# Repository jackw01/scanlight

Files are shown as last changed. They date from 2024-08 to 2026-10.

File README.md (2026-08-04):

# A Better Light Source For Scanning Color Negative Film

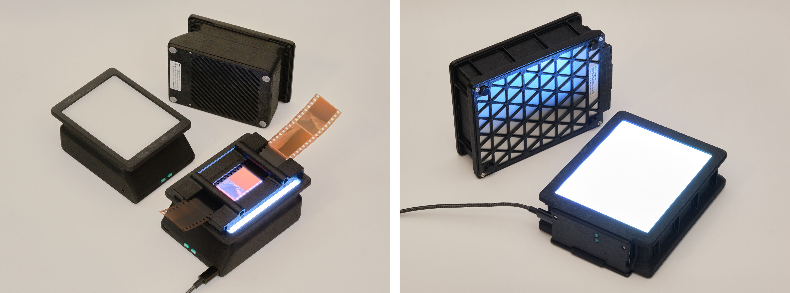
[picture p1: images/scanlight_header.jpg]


Left: [scanlight v4](./v4.md), right: [big scanlight](./big.md)

<small>Originally published 2024-08-05, last updated 2026-08-02</small>

## tl;dr

Narrowband trichromatic (RGB) light sources are superior to broadband (white) light for scanning color negative film; there are very good reasons why all commercial film scanners use RGB. ([film scanners were using blue LEDs at least a decade before they would be widely used in consumer products!](https://patents.google.com/patent/JPH09130546A/en?q=(film+scanner+LED)&oq=film+scanner+LED&sort=old)) Scanning film with an RGB light source produces high quality results with minimal post-processing, without the need for specialized software.

### the results

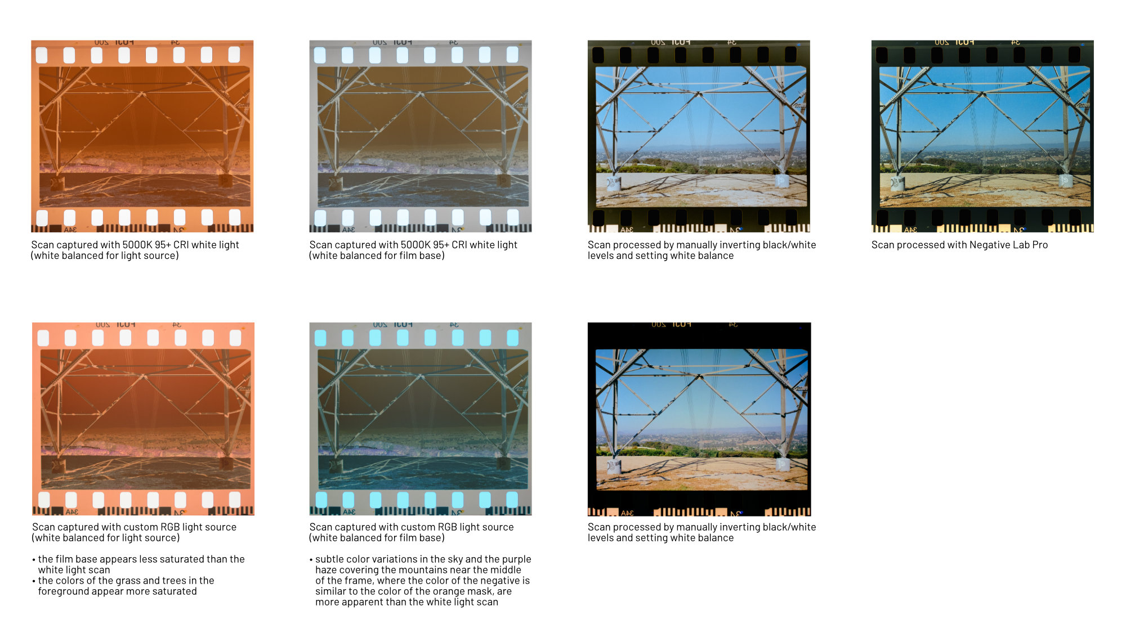
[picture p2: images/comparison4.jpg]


<small>Both scans captured using Fujifilm X-T30. White light scan captured using 95+ CRI 5000K light source. RGB scan captured using custom 450nm+525nm+665nm light source.</small>

## the simplified explanation

Color negative (C-41) film stores an image using cyan, magenta, and yellow dyes. Dyes appear a certain color because they absorb some wavelengths of light; for example, yellow dye mostly absorbs light in the 400-550nm range (which we perceive as violet through green), while allowing other wavelengths (yellow through red) to pass through the film. **These dyes are not intended to produce a human-viewable image, but rather to attenuate certain wavelengths of light for making prints on photosensitive paper.**

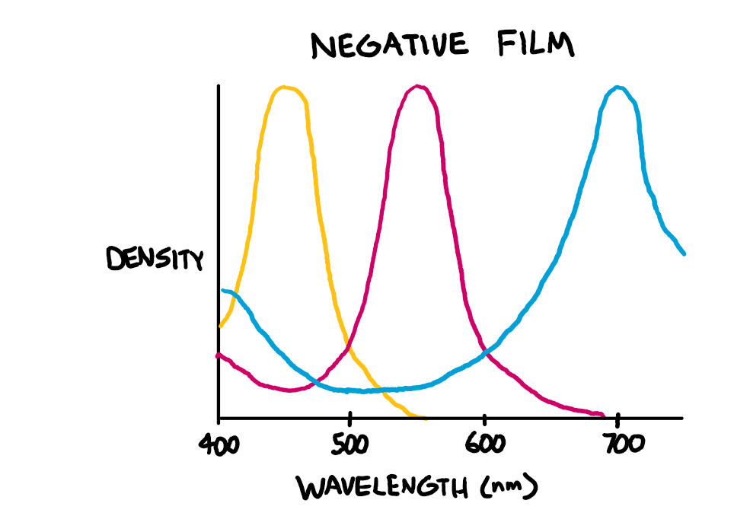
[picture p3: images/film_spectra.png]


White light sources emit light over a broad spectrum of wavelengths. When white light passes through C-41 film, some of these wavelengths are only slightly absorbed by the dyes, which means that these wavelengths aren't useful for recovering the information stored in the individual dye layers - for example, the 580-620nm band (yellow through red-orange light) is mostly transmitted through the film, with a small amount being absorbed by both the magenta and cyan dye layers.

The quality of white light sources is measured with CRI, which represents how well a light source reproduces the true color of a set of standardized color swatches. CRI is effectively a weighted average of how much light a light source emits across different parts of the visible light spectrum, and only a few of these parts matter when it comes to extracting information from color film. **CRI doesn't take into account the deep red (>630nm) and deep blue (<480nm) parts of the spectrum, so as a result, many high-CRI LEDs don't emit much light at these wavelengths, which happen to be where the yellow and cyan dyes absorb the most light.**

<small>note: Standardized scores that take into account these wavelength bands at the edges of the visible spectrum do exist (R9 and R12), but are not readily provided by all LED manufacturers.</small>

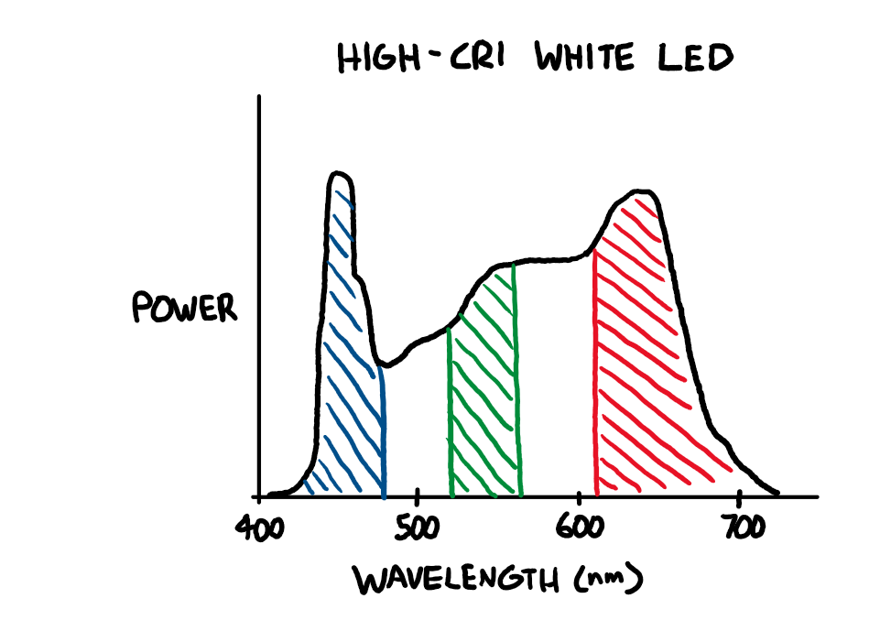
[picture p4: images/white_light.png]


With darkroom printing, this is not an issue, as RA-4 color print paper (and motion picture print film) are, by design, most sensitive to specific bands of wavelengths that avoid the crosstalk regions between the dye layers in negative film, and the paper is exposed with an incandescent light source with a smooth emission spectrum across the entire visible range (400-700nm) and beyond.

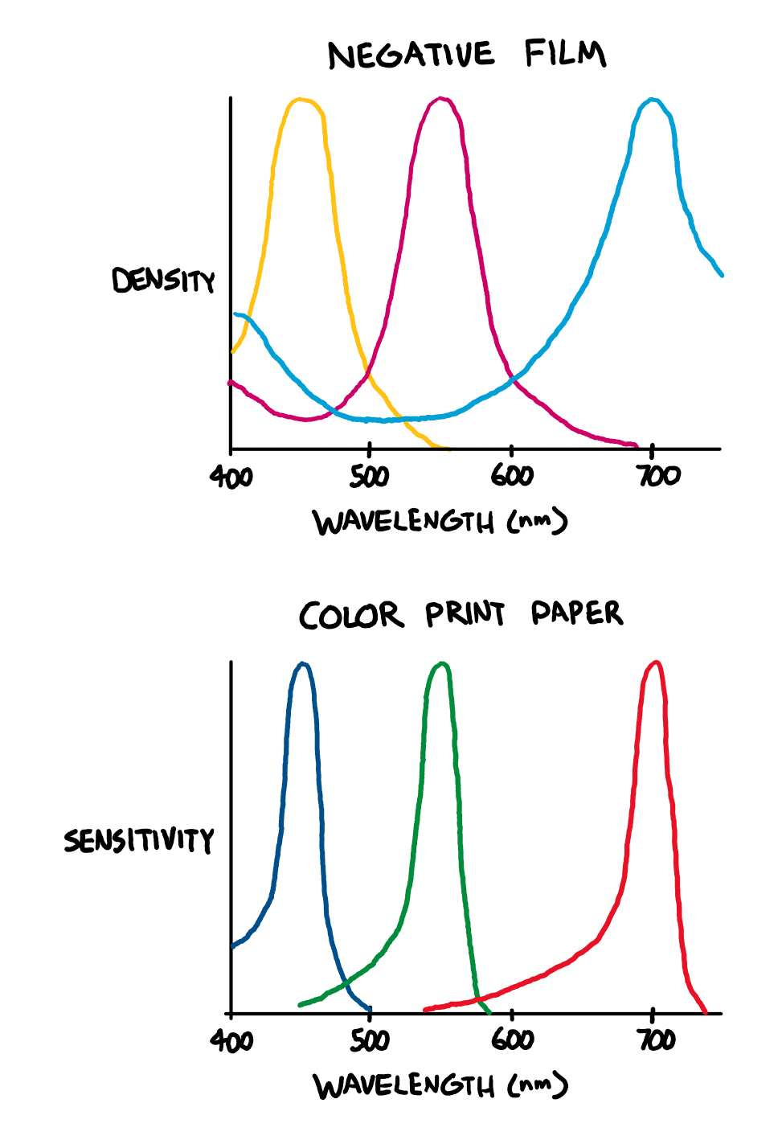
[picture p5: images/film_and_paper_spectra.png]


What about scanning film with a digital camera? Digital camera sensors are designed to capture light in a way that allows for a faithful reproduction of the colors that humans would perceive (this is a gross oversimplification.) C-41 film was *not* designed to be directly viewed by humans.

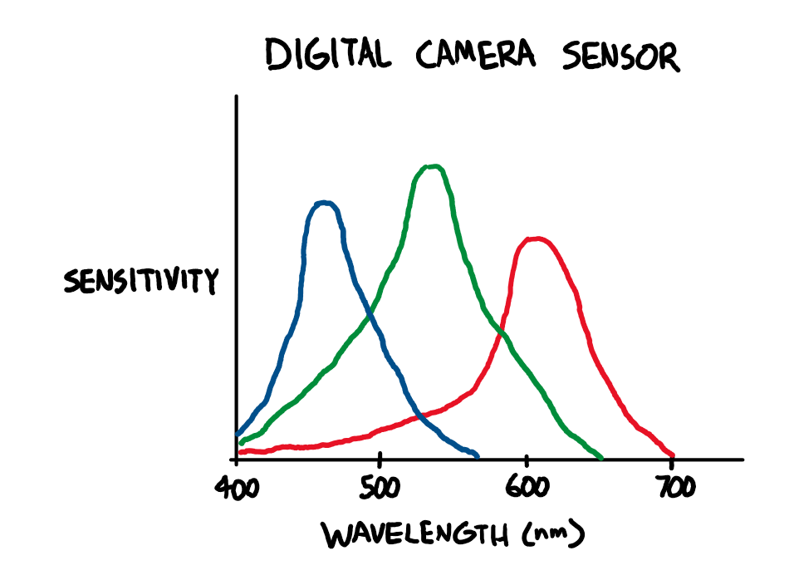
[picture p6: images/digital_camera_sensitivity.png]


Not only is the camera sensitive to wavelengths of light that are effectively ignored by RA-4 paper, there is significant crosstalk between the color channel sensitivities of digital camera sensors: light in the ~580-600nm range is seen roughly equally by the red and green channels, and light in the ~480-500nm range is seen by both the green and blue channels.

The red channel of the scan will contain not just information from the red-blocking cyan dye, but also the green-blocking magenta dye. The green channel will contain information from all three dye layers. Additionally, the overall light transmission of C-41 film is heavily biased towards yellow and orange wavelengths due to the orange mask and the relatively large gap between the magenta and cyan dye absorption peaks, which means that **a lot** of light gets through that interferes with both the red and green channels in the camera sensor without carrying much useful information about the colors stored in the film.

<small>note: the orange color of C-41 film is often misunderstood to be the color of the plastic film base, or an orange tint evenly applied over the whole image. It is actually a corrective mask made up of blue- and green-blocking positive images which compensate for deficiencies in the red-sensing and green-sensing layers of the film. For a good explanation of how this works, see [this article](https://observablehq.com/@dorskyee/understanding-color-film). In practice, this means that less-exposed parts of the negative let through disproportionately more yellow, orange, and red light.</small>

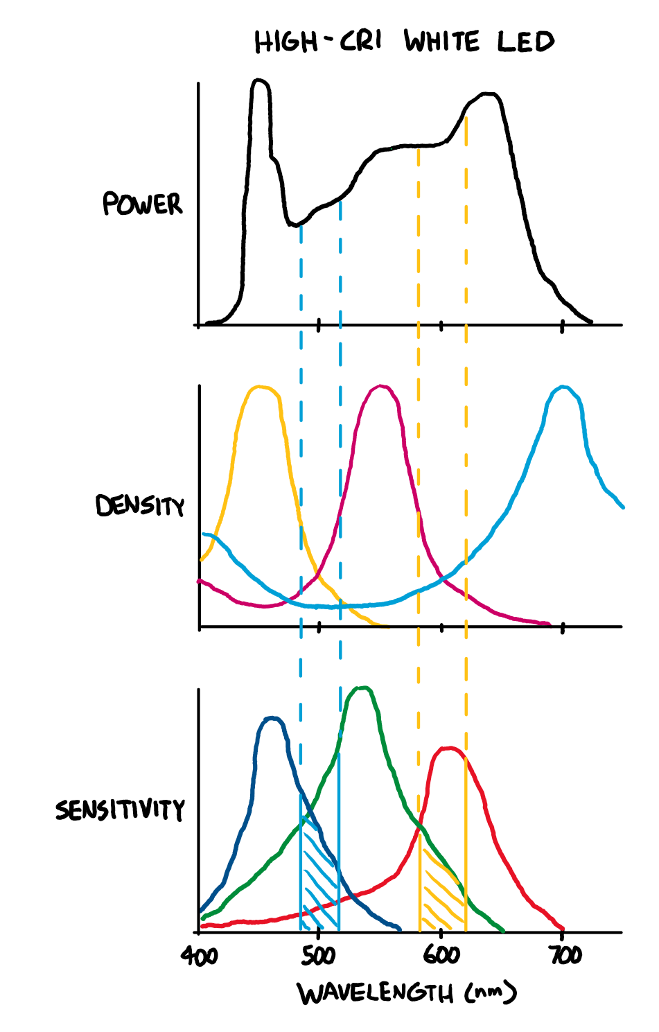
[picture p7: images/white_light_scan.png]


So if you scan color negative film with white light, you can't just invert the colors and expect a good result. You need to do some math to try to recover the individual dye layers of the film from ambiguous input data. This can't be done in standard image editing software, which is why dedicated software for negative conversion exists. The level of crosstalk on each channel depends heavily on both the emission spectra of the light source and the spectral sensitivity of the camera, so the conversion process needs to be either calibrated, manually adjusted until it looks “right”, or deduced by the processing software with varying degrees of accuracy. The color depth of the resulting positive image will be relatively low because much of the information recorded by the camera is effectively useless yellow-orange light that has passed through the film without being significantly attenuated by any of the dyes.

To avoid these issues, (almost?) all commercial negative film scanners use a trichromatic narrowband light source with red, green, and blue LEDs to minimize crosstalk between the dye layers in the film and the color channels on the image sensor, and some use monochrome sensors to eliminate sensor crosstalk entirely. When doing it this way, no guesswork is needed to recover a usable image and it's really as simple as inverting the color channels and setting the color balance and black/white points. There is still some crosstalk between camera sensor channels, but now that the light source emits light in three narrow, independently controllable wavelength bands, it can be easily measured and compensated for, or it can be avoided completely by imaging the red, green, and blue channels separately.

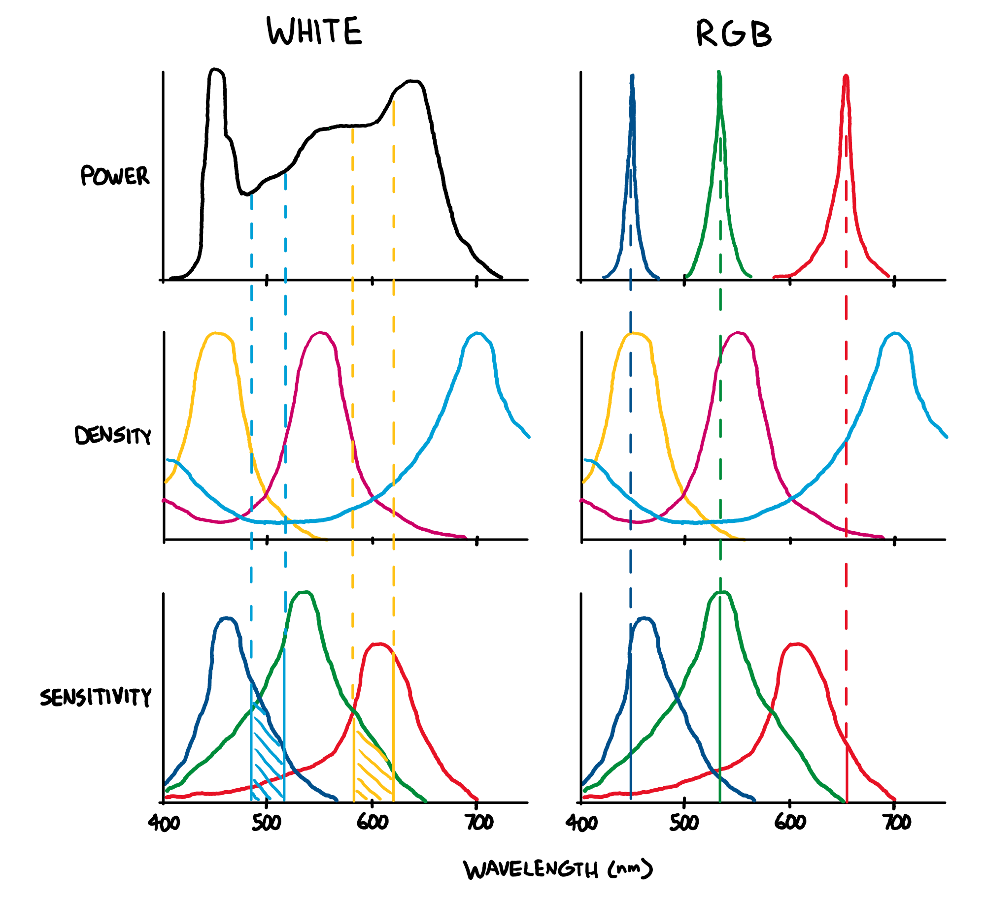
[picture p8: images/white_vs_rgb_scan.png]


### what light source works the best?

When considering the limitations of digital camera sensors, the ideal wavelengths are >650nm for red and <450nm for blue, as shown in the diagram above. Ideally, the green wavelength is 540-560nm to match the absorption peak of the magenta dye, but LEDs in that range are just not practical (see FAQ below for more details), and the standard 525nm works very well.

The next best alternative is to use general purpose RGB LEDs, which typically use 620-630nm for red and 460-480nm for blue. The results will not be the absolute best possible, but will still be far better than with white light. The Fuji Frontier SP3000, a popular professional scanner, uses 630nm for red and 465nm for blue ([source](https://discuss.pixls.us/t/input-color-profile-to-use-for-negatives/20271/13)), but it does not have to contend with the color channel sensitivity of a typical digital camera - it has a monochrome image sensor and combines three exposures taken with red, green, and blue light.

To get the best possible results, I designed my own custom RGB light sources using 665nm red and 455nm blue LEDs. More information on the designs can be found [here (scanlight v4)](./v4.md) and [here (big scanlight)](./big.md).



All design files for the light sources and film carriers, both current and older versions, can be downloaded from the [GitHub repository](https://github.com/jackw01/scanlight/).

### more sample scans

All scans were processed in [NegPy](https://github.com/marcinz606/NegPy), leaving all settings at the default values. Sensor calibration was used for the RGB scans. The groups of four negatives were scanned and manually processed together in order to demonstrate how the light source affects the overall look of the scans rather than to show a subjectively ideal edit for each photo.

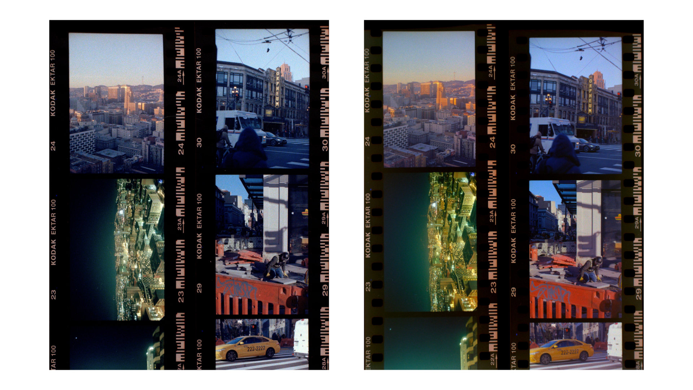
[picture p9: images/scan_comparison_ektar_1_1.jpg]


<p align="center"><small>Kodak Ektar 100 (left: white light, right: narrowband RGB light)</small></p>

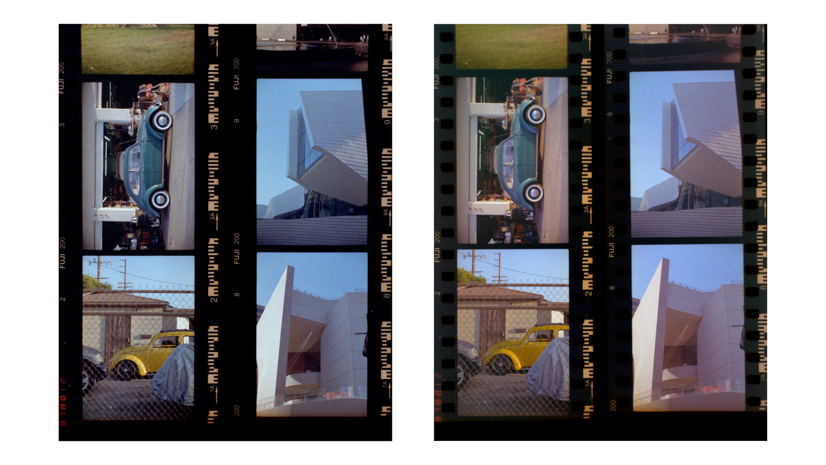
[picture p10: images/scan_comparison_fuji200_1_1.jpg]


<p align="center"><small>Fuji 200 (left: white light, right: narrowband RGB light)</small></p>

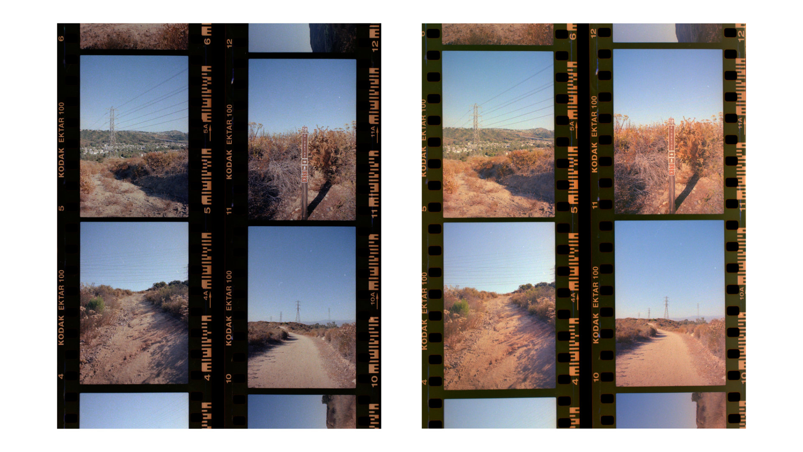
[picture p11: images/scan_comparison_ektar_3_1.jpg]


<p align="center"><small>Kodak Ektar 100 (left: white light, right: narrowband RGB light)</small></p>

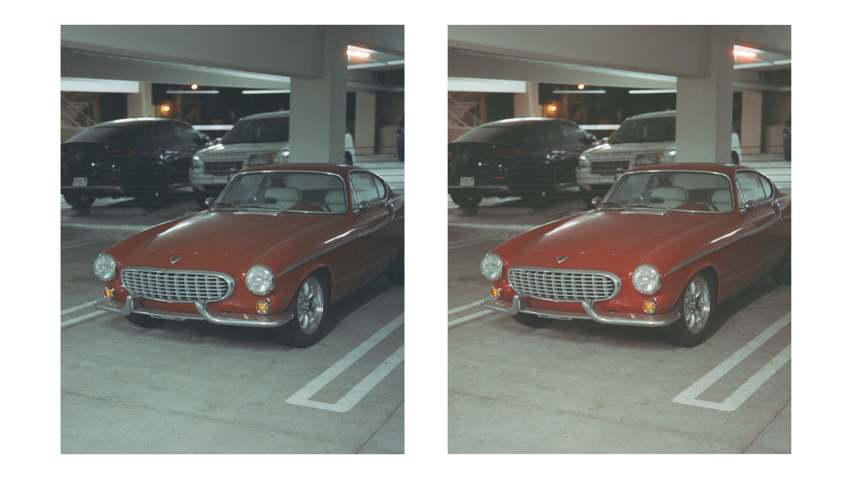
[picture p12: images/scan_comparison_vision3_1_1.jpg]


<p align="center"><small>Kodak Vision3 500T (left: white light, right: narrowband RGB light)</small></p>

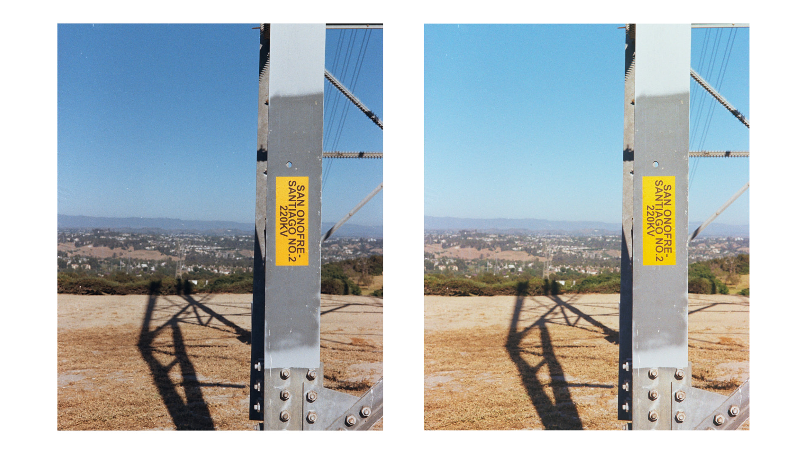
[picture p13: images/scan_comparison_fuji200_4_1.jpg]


<p align="center"><small>Fuji 200 (left: white light, right: narrowband RGB light)</small></p>

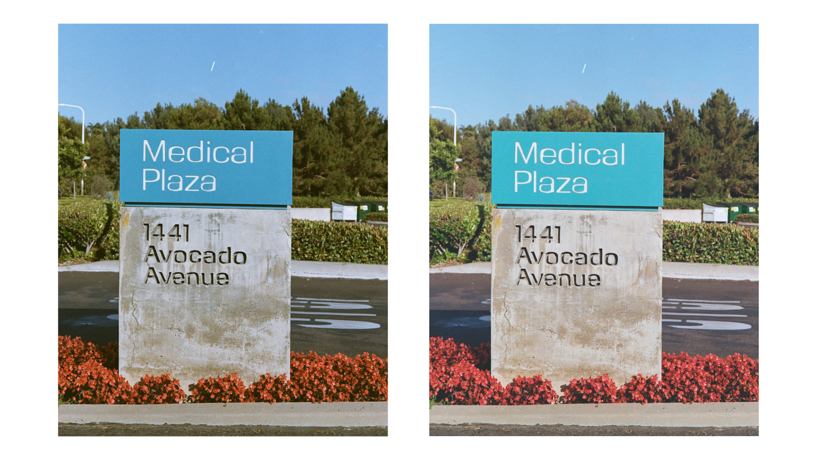
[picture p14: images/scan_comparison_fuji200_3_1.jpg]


<p align="center"><small>Fuji 200 (left: white light, right: narrowband RGB light)</small></p>

### recommended reading, if you're curious

* Edward J Giorgianni and Thomas E Madden, *Digital Color Management: Encoding Solutions, 2nd Edition*
* Robert L Shanebrook, *Making Kodak Film*

## part 2: responses to frequent questions and comments

<small>Updated 2026-08-02</small>

#### how should i process my scans?
As of 2026, free and open-source film scan processing software exists ([NegPy](https://github.com/marcinz606/NegPy)) which produces excellent results with little effort when inverting single-exposure RGB scans. NegPy uses a processing pipeline which emulates the RA-4 printing process, and supports flat-field correction and automatic merging of trichromatic (separate exposures for red, green, and blue) scans. I would highly recommend this to anyone who is looking to start scanning film at home or is having difficulty with their current processing workflow.

Using software specifically designed for processing white light scans (e.g. Negative Lab Pro) to process RGB scans may give suboptimal results. It's also possible to get good results without using any specialized software, by manually inverting your scans in photo editing software as described below. Manual inversion is much easier with RGB scans than with white light scans, but it still takes more effort than NegPy, and compensating for camera sensor crosstalk may be difficult depending on which image editing software you use.

#### but can't i just edit the white light scan to look like the RGB scan?
You can't get the exact same colors as the RGB scan by adjusting the white balance or individual color channels of a white light scan. This is physically impossible because the light interacted with the film in a fundamentally different way in the white light scan vs. the RGB scan before it was reduced to three bins of wavelengths approximately representing red, green, and blue by the camera sensor; some of the color information stored in the film is lost in this process.

#### but i keep seeing/hearing that using RGB light results in oversaturation or hue shifts
Increasing saturation is often done on purpose to produce a visually striking and not entirely accurate demonstration of why RGB is better (in practice, the differences in color reproduction are more subtle once saturation is equalized), or is the result of processing RGB scans with processing workflows intended to produce normal-looking results with white light scans. No one is saying you can’t adjust saturation in post, or use processing software that produces less-saturated results. Hue shifts are a result of using a processing workflow that doesn't compensate for camera sensor channel crosstalk, and should be a complete non-issue if using the sensor calibration tool in NegPy.

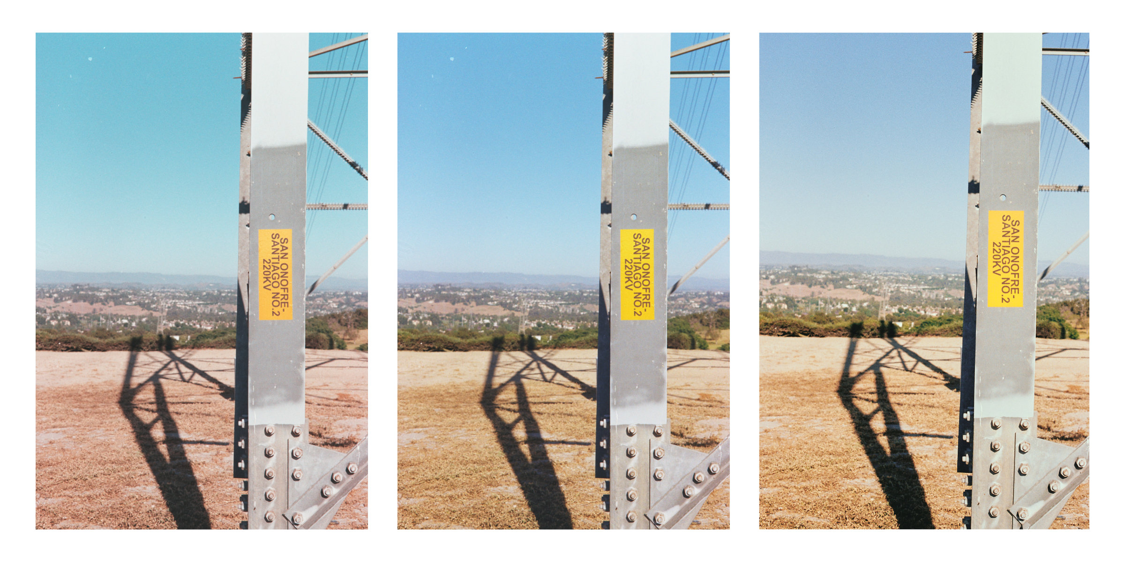
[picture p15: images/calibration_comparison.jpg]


<p align="center"><small>From left to right: RGB scan without sensor calibration (note blue-to-cyan and orange-to-magenta shifts); RGB scan with sensor calibration; Noritsu HS-1800 lab scan</small></p>

#### but the colors in the sample scans still don't look good to me / the colors don't look the way i think film should look
Getting the desired colors from C-41 film, whether by darkroom printing or scanning and editing, has always involved some level of manual adjustment. It is also worth noting that our collective idea of how film is supposed to look is often influenced by highly edited or low-quality scans; old, faded prints; or even software emulations. **Photography is art, and as such it has always involved making subjective decisions about how images should look; all photos are interpretations of raw data and it's up to the photographer to decide what interpretation looks best.** The best starting point for editing is a scan that represents the image data stored in the dye layers of the film with maximum dynamic range and minimal crosstalk.

#### won't this make all film look the same?
Scanning film with RGB light does not neutralize the differences in the "look" of different films; actually, it should produce results that are closer to the intended look of the film when printed on RA-4 paper. The differences in look come from differences in the film's sensitivity to light during exposure and chemical reactions that affect how the dyes are formed during development, not the absorption characteristics of the dyes themselves.

#### should i capture three separate exposures for each color channel?
You can either capture a single image with the red, green, and blue channels on at the same time or capture separate images for each color and merge them later. Both methods can produce satisfactory results. The latter approach has the potential for more technically accurate colors as it eliminates any chance of crosstalk between color channels, but takes significantly more work than capturing a single RGB image which can be processed directly.

When capturing red, green, and blue at the same time, the severity of crosstalk depends heavily on the spectral response of the camera's image sensor and camera manufacturer's color profile, and it may not even be noticeable in many cases. Crosstalk typically manifests as consistent color shifts (usually, reds appearing too pink or greens appearing too yellow,) and can usually be resolved by post-processing with software that supports a crosstalk matrix or RGB primary calibration, such as NegPy (open-source) or Lightroom.

#### how should i adjust the red/green/blue channel levels on the light source?
The red, green, and blue channels on the light source should be adjusted to maximize how much of the camera's dynamic range is utilized on all three color channels. To do this, set the camera white balance to neutral/5000K and adjust the light source so that the histogram peaks on each channel become aligned when the camera is viewing the light through an unexposed, developed piece of film. The deep red (~650nm) and deep blue (~450nm) wavelengths used for RGB scanning are near the edge of what most Bayer-filter image sensors are sensitive to, so some cameras will be significantly more sensitive to one of these wavelengths than others. Therefore, the optimal settings will differ between camera manufacturers and models.

#### should i use narrowband light for scanning color positive (slide) film?
Some people have had success using an adjustable RGB light source for recovering faded slides, but I would not recommend using a narrowband light source for scanning slides that are in good condition. The results I have seen so far are not promising compared to using white light, as colors are typically oversaturated and pink, red, and orange hues become indistinguishable from each other. This likely all comes down to the fact that color positive film is designed to reproduce colors naturally when viewed with a broad-spectrum light source. Any high CRI (95+) white light source should work well. There is some debate over the ideal color temperature: the majority of slide projectors used halogen bulbs with a 3000K-3500K color temperature, but some will argue that a 5000K color temperature should be used instead (this seems to be because Fujifilm datasheets recommend viewing with a ISO 3664 compliant viewer, which historically would have used specialized 5000K high-CRI fluorescent tubes as a light source). I haven't seen a side-by-side comparison, but I would assume that the difference in results would be very subtle or nonexistent if the white balance is corrected when editing the scans.

#### does light source / color matter for scanning black and white film?
No. White and narrowband light sources work equally well for scanning B&W film.

#### what are your thoughts on film carriers?
I have received quite a few emails echoing the sentiment that the film carriers on the market now are generally overpriced for what they are, and there seems to be little correlation between price and user experience. Most film carriers made for DSLR scanning guide the film through a narrow slot with an S-shaped curve on each end to keep it flat. For 35mm film, this seems to generally work well, and based on the reviews and comments I have seen I am not convinced that out of the many film carriers using this design, any perform significantly better than the others. For 120 film, the s-curve design struggles with film flatness when scanning the end frames on cut pieces of film, or if the film is curled across its width. There are a few alternative designs out there that should be able to provide superior film flatness in this case, but I haven't yet seen a thorough quantitative comparison of these. Some of these also involve rough 3D-printed parts coming into direct contact with the film emulsion, which doesn't seem ideal.

##### what about full-border scanning?
Film carriers that allow full-border scanning tend to be significantly worse at keeping the film flat and handling curled film, except for ones that hold the film against glass or acrylic, but those come with other issues (high cost, difficulty keeping the glass clean, Newton's rings, etc.)

#### what lens should i use?
[This list](https://www.pixl-latr.com/how-good-a-macro-lens-do-you-really-need-for-dslr-mirrorless-camera-scanning/) is generally a good starting point. The Micro-Nikkor 55mm f/2.8 AI is my personal recommendation; it outperforms many modern lenses in field flatness, corner-to-corner sharpness, and chromatic aberration, and it is very affordable.

I would **not** recommend low-cost third-party macro lenses like the TTArtisan 40mm f/2.8 Macro or 7artisans 60mm f/2.8 Macro II. While the build quality of these lenses is excellent and they generally have superior contrast to vintage lenses due to better optical coatings, in my experience they cannot match the top tiers of lenses in the above list in corner-to-corner sharpness and lack of chromatic aberration. I would also recommend against using extension tubes with modern lenses; this tends to result in field curvature and other aberrations which can be quite severe depending on the lens.

#### does brightness enhancing film actually work? should i use it?
Brightness enhancing film (BEF) does indeed work to make diffuse light sources more directional, but this can cause other issues. Collimated light makes the image on the film appear slightly sharper, but also exaggerates the appearance of dust and scratches. Depending on the relative positioning of the light source, film, and lens; and type of lens used; grid or moiré patterns may appear due to the structure of the brightness enhancing film and vignetting may occur or become more pronounced. BEF also tends to be difficult to keep clean of dust and fingerprints.

#### what about using an LCD/OLED display as the light source?
OLED displays do contain separate red, green, and blue emitters, but they typically have broader emission spectra than inorganic LEDs, and the red and blue peak wavelengths tend to be closer to 620nm and 470nm respectively. They will produce results with less crosstalk than a white light source, but not as good as RGB LEDs.

Older LCD displays generally emit white light that has been filtered through red, green, and blue filters and recombined. The results will depend on the emission spectrum of the exact display used, and will generally be no better than a white light source. Newer high-gamut LCDs (especially quantum dot LED LCDs) use backlight LEDs with special phosphors designed to emit in narrower bands than typical white LEDs, so they should in theory work as well as OLED.

#### 540-560nm appears to be the ideal green wavelength, why use 525nm?
LEDs in the 540-560nm range are impractical for most uses due to poor efficiency and thus are not widely available. Some GaP green LEDs exist which have peak emission at 555nm, but they are extremely inefficient, requiring hundreds to match the light output of a single 2835 mid-power InGaN LED. Some manufacturers do offer 530-535nm wavelength bins of their InGaN mid-power green LEDs, but these are difficult to source as they are commercially undesirable due to lower efficiency. Applications where a "true green" or "lime green" color is desired usually now use phosphor-converted LEDs, which are very efficient but are suboptimal for film scanning as they output light over a much broader band of wavelengths (60-100nm FWHM vs 15-30nm for direct green LEDs.)

##### how did old film scanners get ~540nm?
They either used cold-cathode fluorescent lamps with phosphors tuned to emit at the desired wavelengths, or used InGaN green LEDs from a higher wavelength bin. These have become increasingly hard to find as manufacturing processes have become more consistent and the industry has settled on ~525nm as the standard green wavelength for lighting and display applications. On the other hand, mid- and high-power ~450nm deep blue and ~660nm deep red LEDs have stayed available alongside their more common ~470nm and ~620nm counterparts due to increased demand, mostly in horticultural applications.

#### why does big scanlight have infrared LEDs?
The IR LEDs are for dust removal – the dyes in color negative film transmit infrared light, but dust does not. By capturing a separate IR image with an IR-sensitive camera, dust particles on the image can be easily located and inpainted. I originally added the LEDs for a specific customer who uses a specialized industrial camera and custom software processing pipeline to do this. As of June 2026, the only free/open-source software I know of that can automate this process is [NegPy](https://github.com/marcinz606/NegPy), although I haven't yet tested it with output from big scanlight.

#### will there be a desktop app for scanlight?
There are no plans for a desktop app right now, since the easiest way to make one by far is to just repackage a web app as a desktop app and there is little to be gained by doing this. It is possible to install the app as a progressive web app on most platforms, which will make it appear as a desktop app and allow it to be used without an internet connection.

#### what if i want to manually invert my scans?
It's definitely much easier to do this with narrowband scans than white light scans, but I still recommend using NegPy due to its automatic analysis and camera sensor calibration abilities.

##### 1. scan
Scan all frames as RAW using fixed white balance and exposure. Exposure should be set such that none of the color channels are clipping.
##### 2. import
Import scans into image editing software. Use a linear RAW profile. Apply lens corrections and use Lens Cast Calibration in Capture One or Flat-Field Correction in Lightroom to compensate for any unevenness in the light source if necessary.
##### 3. d-min balance
Neutralize the color of the minimum density (unexposed) areas of one negative by adjusting the red, green, and blue channel max levels.
##### 4. inversion
Invert the black and white points using the Levels or Curves tool and apply an s-shaped tone curve to adjust contrast. Use the brightness/gamma/Levels tool midpoint controls to adjust the overall scene brightness without affecting the black and white points.
##### 5. fine tuning
Apply the same adjustments to all scans from the same roll of film. Manually fine-tune the black and white points and brightness/gamma for all scans.
##### 6. crosstalk compensation
Use either the primary calibration panel in Lightroom, or the color tools in Capture One (more difficult), correct any hue shifts in the scans. Since hue shifts occur due to crosstalk between camera sensor channels in the light source emission bands, not any property of the film itself, this adjustment should be performed across a broad sample of images and saved for future use.

## license

The PCB schematic, layout, and Gerber files and the 3D CAD files for this project are released under the [CERN Open Hardware Licence Version 2 - Weakly Reciprocal](https://choosealicense.com/licenses/cern-ohl-w-2.0/) (CERN-OHL-W V2). Software and firmware are released under the MIT License. The text and illustrations in this article may not be reproduced without permission.

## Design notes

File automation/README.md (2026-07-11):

# scanlight firmware and web app

## hardware versions and binaries

| hardware | hardware version ID | firmware binary filename |
| --- | - | --- |
| scanlight v2/v3 | 2 | sl2_controller* |
| scanlight v4 with 26a901a PCB | 1 | sl4a_controller* |
| scanlight v4 with 26a901b PCB (focus support) | 3 | sl4b_controller* |
| big scanlight | 0 | bsl1_controller* |

## documentation

* [scanlight unified firmware control interface documentation](./bsl_control_interface.md)

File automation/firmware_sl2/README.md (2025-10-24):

Red, green, and blue channel control signals connect to Pi Pico pins 7, 8, and 9 respectively.

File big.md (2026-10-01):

# big scanlight info & instructions

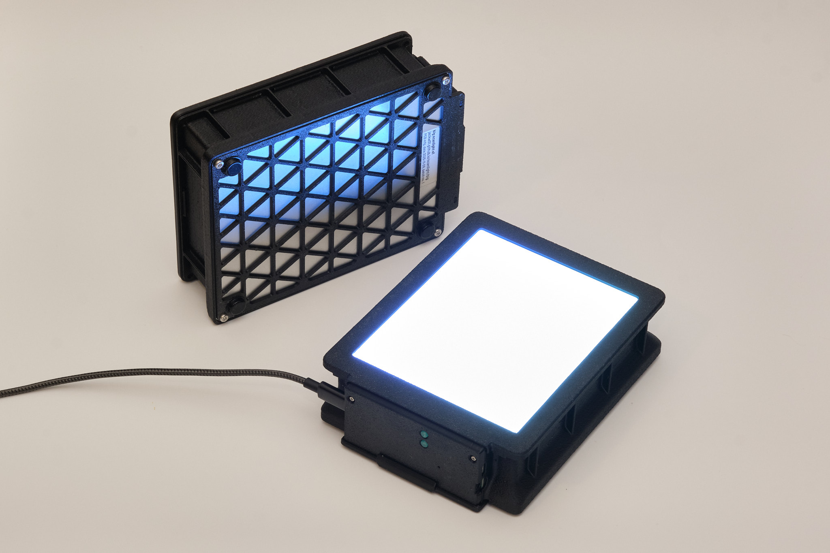
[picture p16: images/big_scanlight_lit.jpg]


## features
* Illuminated area dimensions: 108x134mm (approx. 4.25x5.25in)
* Suitable for use with 35mm, medium format, and 4x5 film
* 20 each of deep red (665nm), green (525nm), deep blue (455nm), and 5000K 95CRI white, and 16 infrared (850nm) LEDs mounted on aluminum PCB for optimal heat dissipation
* Up to 15EV brightness<sup>1</sup> in RGB combined mode, 14EV in white mode
* Better light uniformity over medium format frame sizes than scanlight v2/v3/v4
* Diffuser made from fingerprint- and scratch-resistant textured acrylic
* 3D printed ABS housing
* Fully controllable via USB with [web app](https://jackw01.github.io/scanlight/automation/app_bsl/dist/index.html)
* On/off and mode toggle buttons on light source for standalone usage
* Compatible with accessories made for Negative Supply 4x5" light sources<sup>2</sup>
* Adapters available for compatibility with ToneCarrier and Valoi 360 Advancer
* Minimalist 35mm and medium format film carriers available
* Automated camera shutter control for capturing separate red/green/blue images
* Powered using any USB-C power source (at least 9V at 18W required for full brightness)
* Open source hardware and software

<small>
<sup>1</sup>1/500s at f/8, ISO 100. Direct measurement of the light source (without film.)<br />
<sup>2</sup>big scanlight's diffuser panel is inside a 108x134mm, 1.5mm deep recess in the diffuser bezel, designed to accept masks and film carriers for Negative Supply 4x5" light sources. Check dimensions of accessories you plan to use before buying.
</small><br /><br />

Original article on scanning film with narrowband light (with sample scans): *[A Better Light Source For Scanning Color Negative Film](./README.md)*.

## instructions



### basic operation

The light source is powered via the **left USB-C port**. A USB-C PD power source that can supply at least 2A at 9V (e.g. most USB-C phone, tablet, and laptop chargers) is required to operate at full brightness; however, the light will still operate at reduced brightness from any USB power source capable of delivering at least 2A at 5V (e.g. almost all USB chargers from the last 10 years.)

*It is not recommended to power the light from a USB port on a computer; a dedicated USB power supply should be used instead.*

Press the **upper button** to toggle the light on and off. Press the **lower button** to toggle between narrowband RGB and 95CRI white modes. The buttons work even when the light is not connected to a computer. The default RGB channel brightnesses in this mode can be configured from the GUI, as explained below.

To adjust color and brightness and automate the process of scanning red, green, and blue channels separately, the light source can be connected to a computer via the **right USB-C port** and controlled with the web app located [here](https://jackw01.github.io/scanlight/automation/app_bsl/dist/index.html). The web app requires a Chromium-based web browser or Firefox 151 or newer.

In the **Manual Control** panel of the web app, the red, green, and blue channel brightnesses can be adjusted and the color channels can be turned on individually or together. In **RGB** (narrowband trichromatic) mode, the red, green, and blue LEDs are on at the same time. In **White** mode, only the 95CRI white LEDs are on. The red, green, blue, and infrared LEDs can also be turned on individually; the RGB channel brightness adjustments still apply in this case.

The **RGB Presets** panel of the web app allows RGB channel brightness settings to be stored to and loaded from web browser local storage, using the **Load**, **Create**, **Rename**, and **Delete** buttons.

The **Set as Default** and **Load Default** buttons refer to the default RGB preset, which is stored onboard the light source. This functionality is separate from presets stored in the web app and sets the RGB channel brightnesses used when the light is first powered on and when it is not connected to a computer.

### remote shutter release usage

The **3.5mm jack** can be connected to a camera so that the shutter can be remotely triggered from the web app to automatically capture images for each color channel. The length of the shutter trigger pulse and the delay after are both configurable. The default settings should work for most use cases. Operation in the **R,G,B** mode is shown in the timing diagram below; the other modes work similarly.



A cable with a male 3.5mm plug (otherwise known as a headphone connector) on one end and a camera-specific connector on the other end is required to use this functionality. A wide variety of these cables are available from online retailers; I cannot vouch for the quality of any of them or verify that a specific cable will work, as wiring diagrams are almost never published by the manufacturers. The design has been tested and works with several Fujifilm and Canon cameras that use the 2.5mm microphone jack as the remote shutter release input, with a 3.5mm to 2.5mm cable as well as a standard 3.5mm audio cable and 3.5mm to 2.5mm adapter.

On the original and current PCB revisions (26a902**a**/**b** marked on label), the 3.5mm jack is not electrically isolated. If planning to tether the camera to a computer while controlling the shutter using a light source with this PCB, test that the camera and cable are wired correctly first. Connect both the shutter control cable and a USB cable to the camera, and touch the tip of the 3.5mm plug to the exposed metal shell of the USB connector. If this *does not* trigger the camera shutter, the internal wiring of the camera or cable is likely reversed from the de facto standard and connecting the camera to both the light source and computer at the same time may cause issues. This PCB also does not connect the ring (focus) terminal on the 3.5mm jack, and requires a hardware modification to connect this terminal for remote shutter release compatibility with Nikon and Sony cameras, and possibly others. Units with the modification can be identified by light gray paint applied to the externally visible part of the 3.5mm jack. Some third-party remote shutter release cables for Nikon and Sony cameras already connect the shutter and focus signals together, so the issue may not occur with all camera/cable combinations. There is a workaround for using unmodified units with Nikon cameras, which is to connect the camera cable to the light through a 3.5mm mono-to-stereo adapter. If doing this, it is important that the male end of the adapter used is a two-terminal (mono) plug, rather than a three-terminal (stereo) plug.

### frequently asked questions

See [here](https://jackw01.github.io/scanlight/#part-3-responses-to-frequent-questions-and-comments)

### firmware updates

The web app will automatically notify if a firmware update is available and show a button to put the device into firmware update mode. To manually enter firmware update mode, press and hold down the **DFU mode button** while connecting the **right USB-C port** to a computer. The light source will show up as a USB storage device, and a firmware binary file can be copied to this device to update the firmware.

### cleaning precautions

Cleaning the acrylic diffuser panel with cleaning solutions containing high concentrations of isopropanol, other organic solvents, or ammonia can cause crazing or cracking of the acrylic. If needed, use a cleaner meant for eyeglasses or a diluted household all-purpose cleaner like Simple Green. Do not spray liquids directly on the light source.

### brightness trimming

In order to simplify the electrical design of the light source, the red, green, blue, and white color channels are split into two independently driven sides as shown below. The components used are very well matched, so the difference in brightness between the two sides should be a few percent at most and will generally not be noticed unless working with very low-contrast negatives. If there is a noticeable and consistent "split" in brightness or color across the centerline of the light source, the relative brightness of the two halves can be fine-tuned in the **Brightness Trimming** menu in the web app. Setting the trim values to a positive number increases the relative brightness of side 2; setting them to a negative number increases the relative brightness of side 1.



## technical details

### dimensions



### film carrier compatibility

Adapters are available for improved usability with [toneCarrier](https://tonephotographic.com/) and [Valoi 360 Advancer](https://cinestillfilm.com/products/valoi360-advancer) film carriers. Drawings of the adapters with critical dimensions are included below for reference; the dimensions of these third-party film carriers are not published by the manufacturers and are subject to change, so please use these drawings to verify compatibility with your film carriers before buying.

#### toneCarrier 35mm/120 adapter


<small>All dimensions in millimeters. This adapter is NOT compatible with the old 35mm toneCarrier design found on Printables.com.</small>

#### Valoi 360 Advancer adapter


<small>All dimensions in millimeters. Four M4 screws are required, such as the screws included in Valoi kits for attaching the CS-LITE adapter to the Valoi 360 Advancer.</small>

### optical design

Big scanlight uses a very simple optical design consisting of a matte white acrylic diffuser panel, an LED array which spans the entire illuminated area of the diffuser, and a housing with diffusely reflective sidewalls perpenicular to the PCB and chamfered corners to reduce brightness falloff. In both RGB and white modes, big scanlight achieves similar lighting uniformity to scanlight v4 (slightly better than scanlight v2/v3) over a larger area.

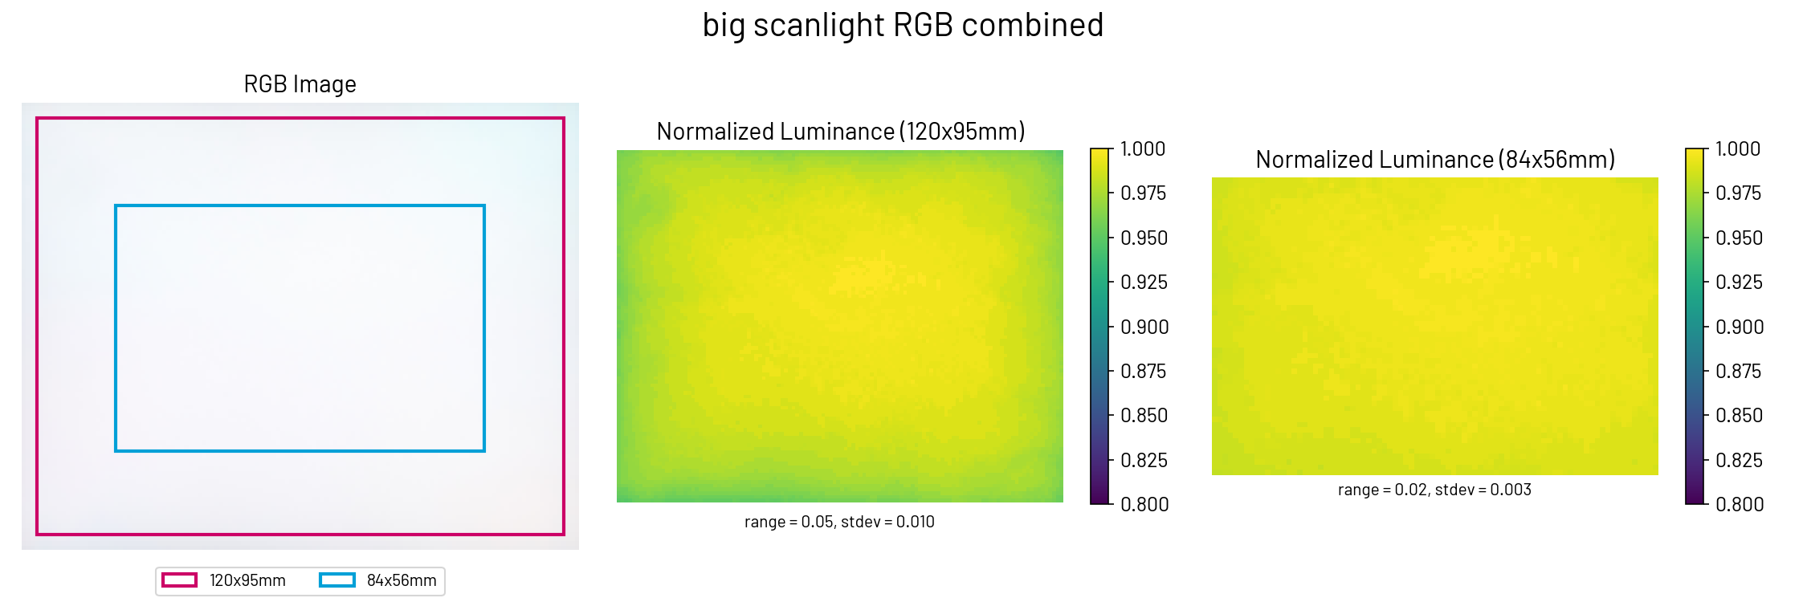
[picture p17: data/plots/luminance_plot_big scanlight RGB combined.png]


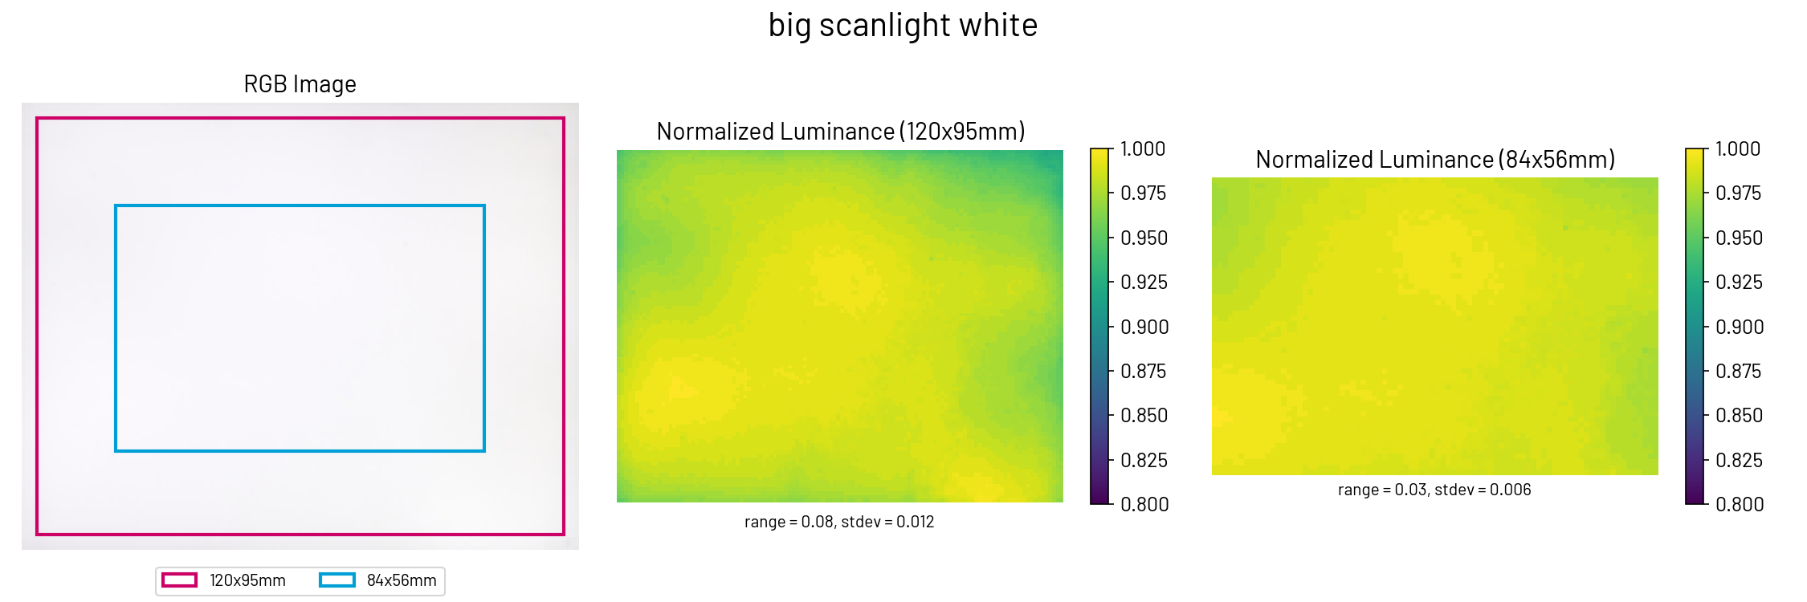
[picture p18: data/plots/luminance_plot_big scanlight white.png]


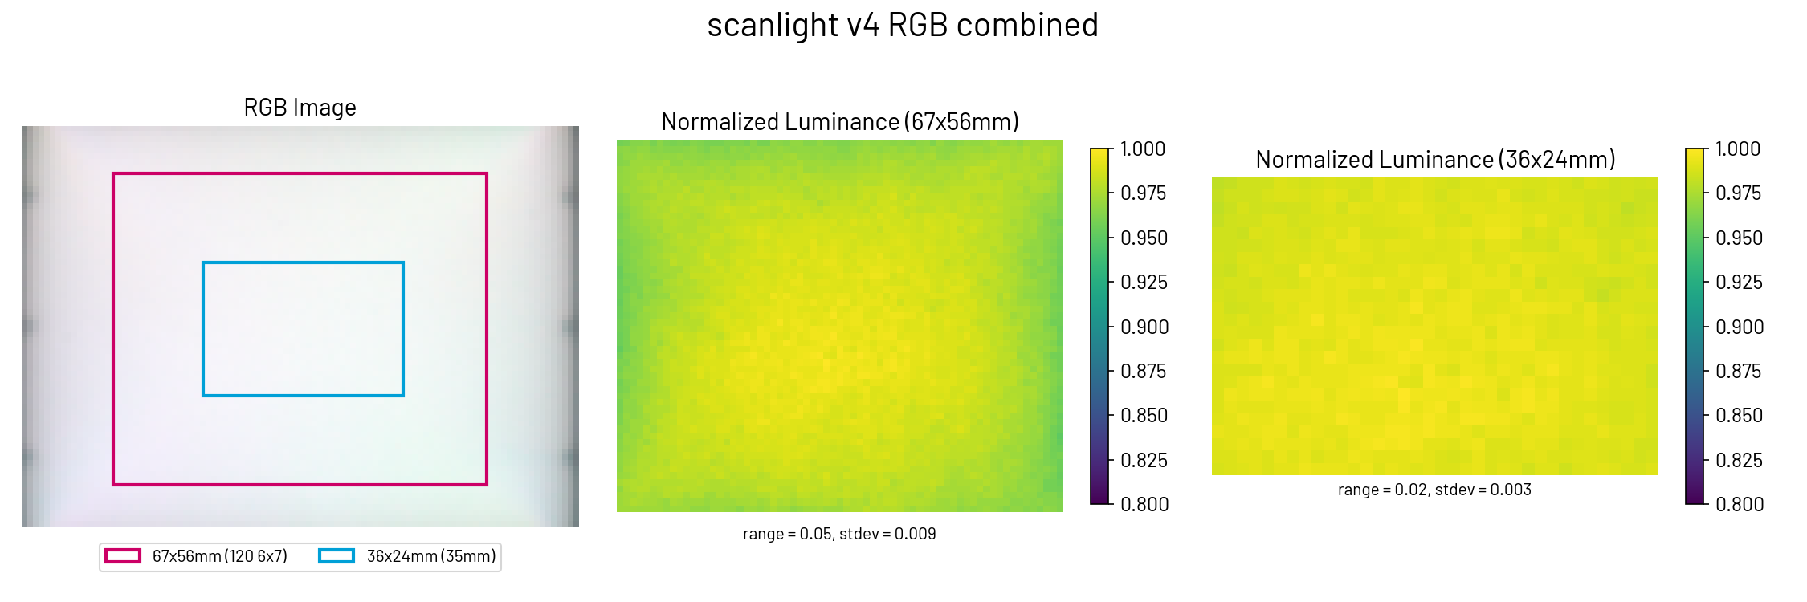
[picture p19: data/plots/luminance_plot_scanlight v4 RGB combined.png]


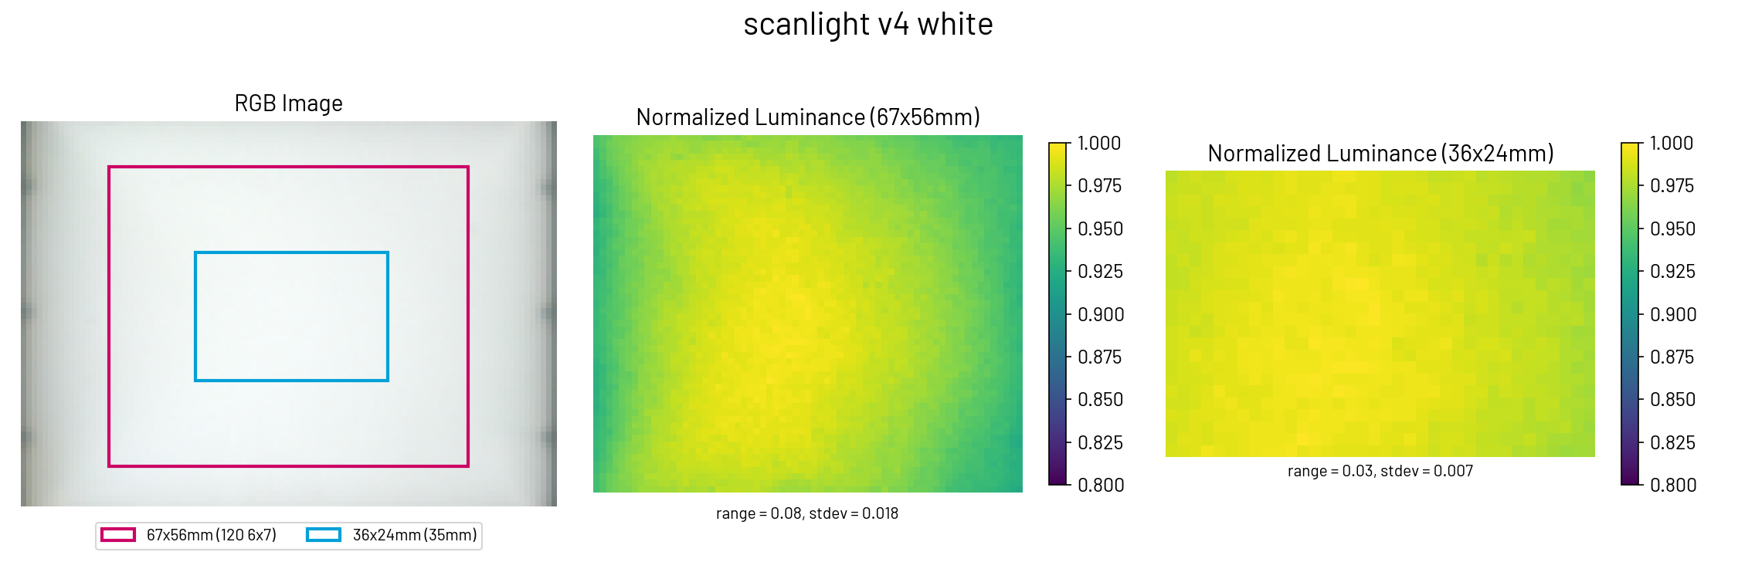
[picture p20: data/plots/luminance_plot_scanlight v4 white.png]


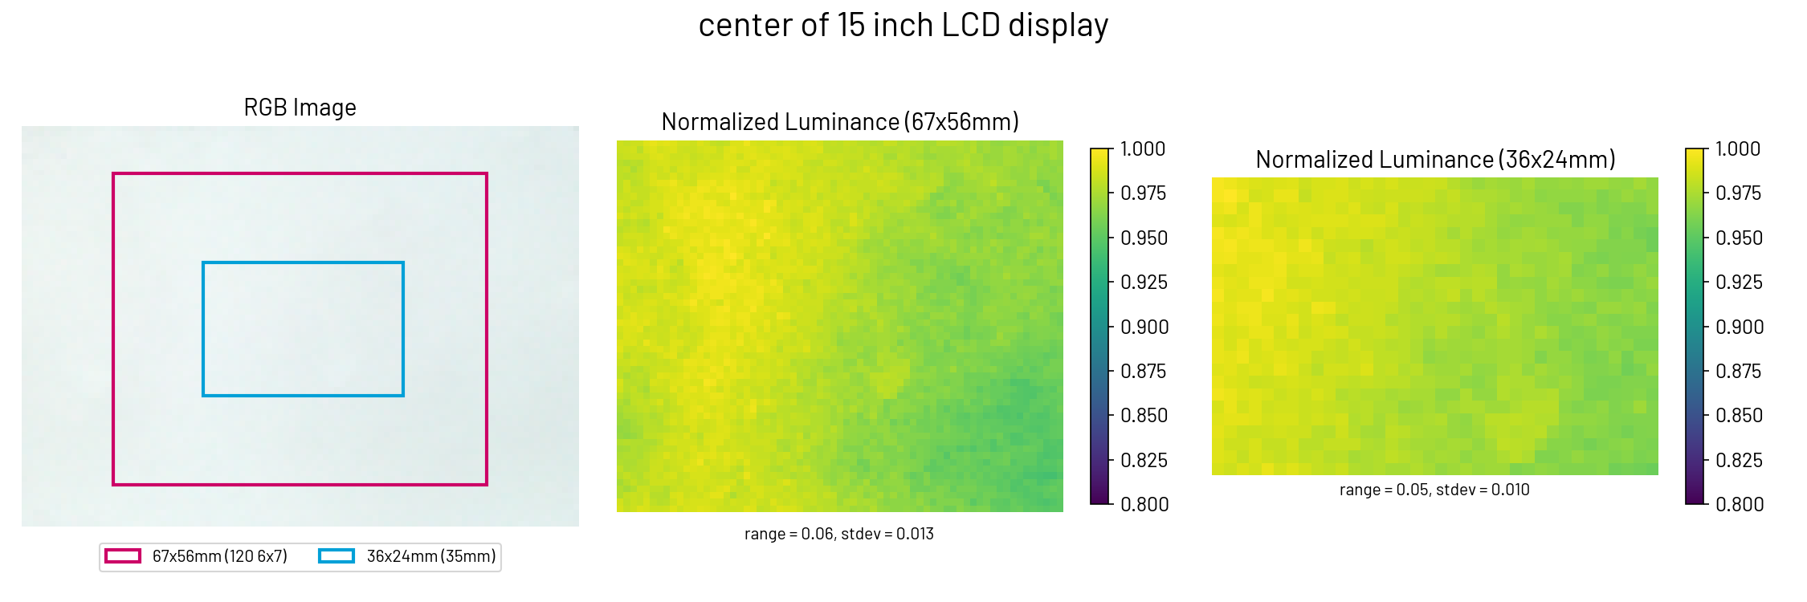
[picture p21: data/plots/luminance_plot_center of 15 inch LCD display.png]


### PCBs

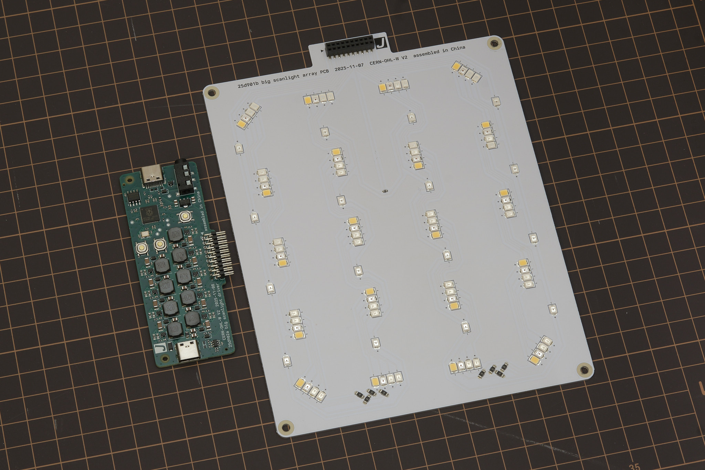
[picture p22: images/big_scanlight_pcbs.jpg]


The driver PCB integrates a RP2040 32-bit ARM Cortex-M0+ microcontroller, nine [TPS61169](https://www.ti.com/lit/ds/symlink/tps61169.pdf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) constant-current boost converters configured for 80mA output current at up to 38V, and a [CH221K](https://www.wch.cn/products/CH224.html) USB-PD protocol controller on a 86x34mm four-layer PCB.

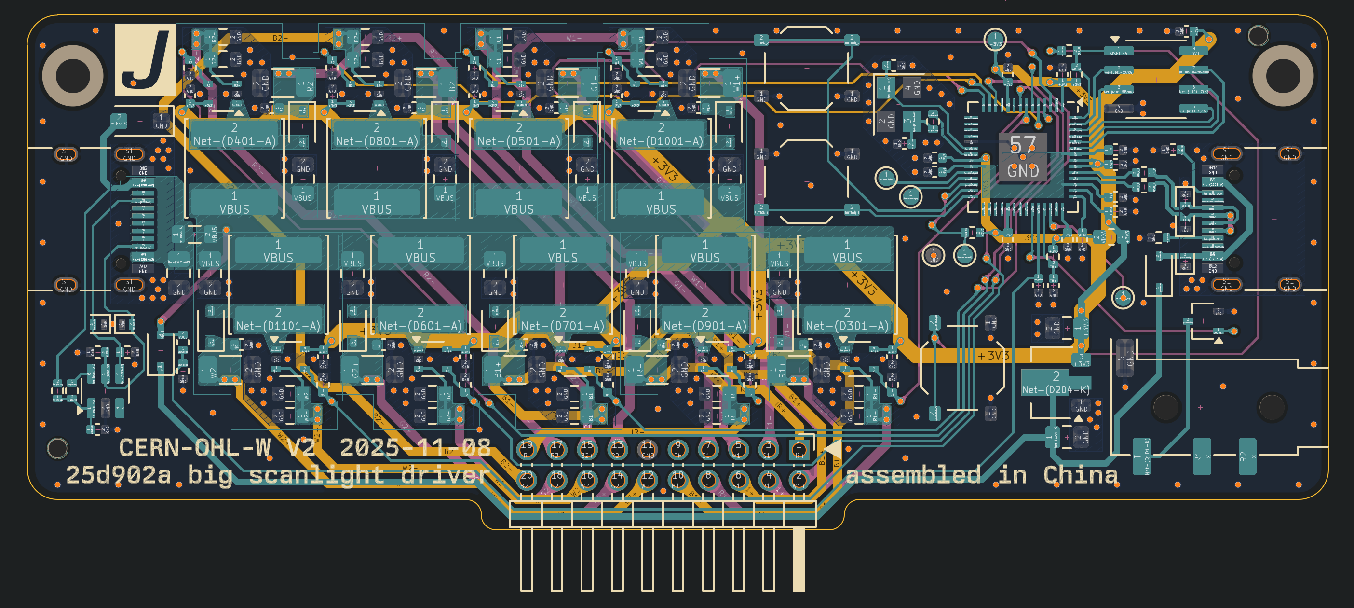
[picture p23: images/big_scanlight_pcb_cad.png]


All design files for the [driver pcb](https://github.com/jackw01/scanlight/tree/main/pcb/bsl_driver_v1.1) and [LED PCB](https://github.com/jackw01/scanlight/tree/main/pcb/bsl_array_v1.1) can be downloaded from the GitHub repository.

[Driver PCB Schematic (PDF)](pcb/bsl_driver_v1.1/bsl_drv_v1.1_20260120.pdf)

[Driver PCB BOM (CSV)](pcb/bsl_driver_v1.1/bsl_drv_v1.1_20260120.csv)

[LED PCB Schematic (PDF)](pcb/bsl_array_v1.1/bsl_array_v1.1_20260120.pdf)

[LED PCB BOM (CSV)](pcb/bsl_array_v1.1/bsl_array_v1.1_20260120.csv)

### mechanical design

STEP files for all parts of the light source, film carrier adapters, and film carriers can be downloaded from the [GitHub repository](https://github.com/jackw01/scanlight/tree/main/3d).

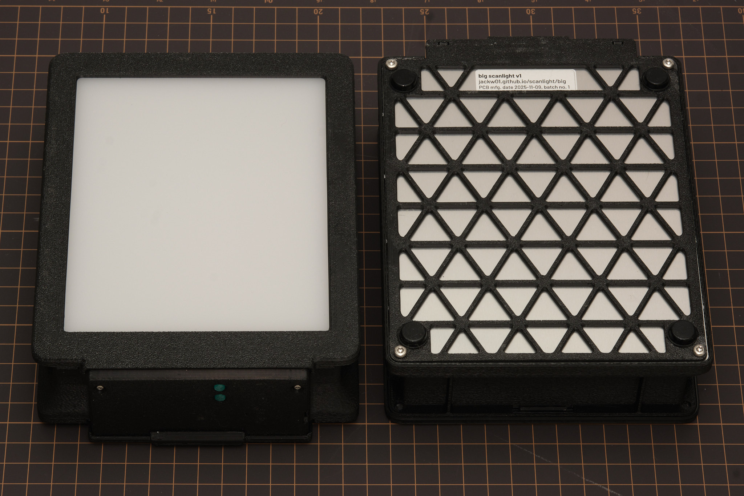
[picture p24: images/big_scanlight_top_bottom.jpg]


### firmware and web app

The [source code for the RP2040 firmware](https://github.com/jackw01/scanlight/tree/main/automation/firmware_bsl1), a [ready-to-flash firmware binary](https://github.com/jackw01/scanlight/blob/main/automation/bsl1_controller_v1.0.uf2), and the [source code for the remote control web app](https://github.com/jackw01/scanlight/tree/main/automation/app_bsl) can be downloaded from the GitHub repository. The firmware is implemented using the RP2040 SDK and the web app is made with [Vue](https://github.com/vuejs) and [Vuetify](https://github.com/vuetifyjs/vuetify).

Interested in building your own control software? The USB serial communication interface used by the firmware is fully documented [here](https://github.com/jackw01/scanlight/blob/main/automation/bsl_control_interface.md).

### license

The PCB schematic, layout, and Gerber files and the 3D CAD files for this project are released under the [CERN Open Hardware Licence Version 2 - Weakly Reciprocal](https://choosealicense.com/licenses/cern-ohl-w-2.0/) (CERN-OHL-W V2). Software and firmware are released under the MIT License.

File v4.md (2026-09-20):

# scanlight v4 info & instructions

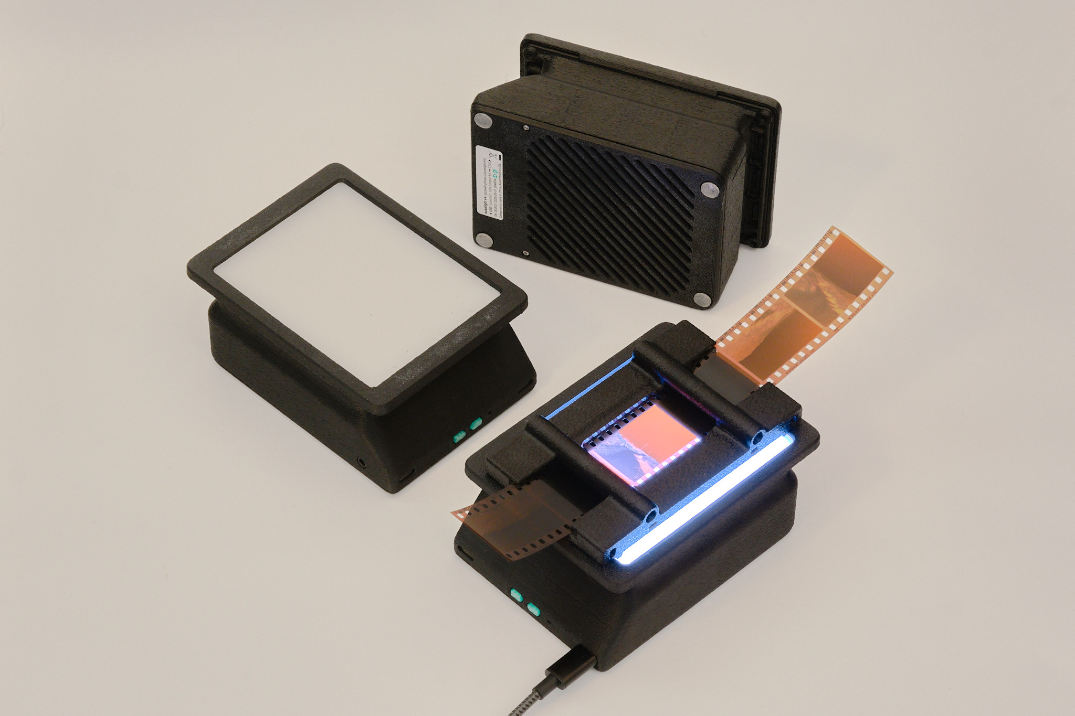
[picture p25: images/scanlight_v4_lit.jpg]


## features
* Illuminated area dimensions: 100x76mm (approx. 4x3in)
* Suitable for use with 35mm and medium format film (optimized for 6x7 and smaller sizes)
* Nine each of deep red (665nm), green (525nm), deep blue (455nm), and 5000K 95CRI white LEDs
* Up to 15EV brightness<sup>1</sup> in RGB combined mode, 14EV in white mode
* Moderately improved lighting uniformity for medium format over scanlight v2/v3
* Diffuser made from fingerprint- and scratch-resistant textured acrylic
* 3D printed ABS housing
* Fully controllable via USB with [web app](https://jackw01.github.io/scanlight/automation/app_bsl/dist/index.html)
* On/off and mode toggle buttons on light source for standalone usage
* Designed for vertical use with a copy stand or horizontal use with optional threaded insert mounting points
* Adapters available for compatibility with ToneCarrier and Valoi 360 Advancer
* Minimalist 35mm and medium format film carriers available
* Automated camera shutter control for capturing separate red/green/blue images
* Powered using any USB-C power source
* Open source hardware and software

<small>
<sup>1</sup>1/500s at f/8, ISO 100. Direct measurement of the light source (without film.)<br />
</small><br />

Original article on scanning film with narrowband light (with sample scans): *[A Better Light Source For Scanning Color Negative Film](./README.md)*.

## instructions



### basic operation

The light source is powered via the **right USB-C port**. A USB power source that can supply at least 2A at 5V (e.g. almost any USB charger from the last 10 years) is required.

*It is not recommended to power the light from a USB port on a computer unless the port is marked as a dedicated high-power or charging port; a dedicated USB power supply should be used instead.*

Press the **left button** to toggle the light on and off. Press the **right button** to toggle between narrowband RGB and 95CRI white modes. The buttons work even when the light is not connected to a computer. The default RGB channel brightnesses in this mode can be configured from the GUI, as explained below.

To adjust color and brightness and automate the process of scanning red, green, and blue channels separately, the light source can be connected to a computer via the **left USB-C port** and controlled with the web app located [here](https://jackw01.github.io/scanlight/automation/app_bsl/dist/index.html). The web app requires a Chromium-based web browser or Firefox 151 or newer.

In the **Manual Control** panel of the web app, the red, green, and blue channel brightnesses can be adjusted and the color channels can be turned on individually or together. In **RGB** (narrowband trichromatic) mode, the red, green, and blue LEDs are on at the same time. In **White** mode, only the 95CRI white LEDs are on. The red, green, and blue LEDs can also be turned on individually; the RGB channel brightness adjustments still apply in this case.

The **RGB Presets** panel of the web app allows RGB channel brightness settings to be stored to and loaded from web browser local storage, using the **Load**, **Create**, **Rename**, and **Delete** buttons.

The **Set as Default** and **Load Default** buttons refer to the default RGB preset, which is stored onboard the light source. This functionality is separate from presets stored in the web app and sets the RGB channel brightnesses used when the light is first powered on and when it is not connected to a computer.

### remote shutter release usage

The **3.5mm jack** can be connected to a camera so that the shutter can be remotely triggered from the web app to automatically capture images for each color channel. The length of the shutter trigger pulse and the delay after are both configurable. The default settings should work for most use cases. Operation in the **R,G,B** mode is shown in the timing diagram below; the other modes work similarly.



A cable with a male 3.5mm plug (otherwise known as a headphone connector) on one end and a camera-specific connector on the other end is required to use this functionality. A wide variety of these cables are available from online retailers; I cannot vouch for the quality of any of them or verify that a specific cable will work, as wiring diagrams are almost never published by the manufacturers. The design has been tested and works with several Fujifilm and Canon cameras that use the 2.5mm microphone jack as the remote shutter release input, with a 3.5mm to 2.5mm cable as well as a standard 3.5mm audio cable and 3.5mm to 2.5mm adapter.

As of the mid-July 2026 PCB revision (26a901**b** marked on label), the shutter and focus signals to the camera are independently controllable from the web app. When the **Send focus signal** checkbox is selected, the focus signal will be held (equivalent to half-pressing the shutter button) for the entire duration that the LEDs are on. Some cameras (mainly Nikon) may need the focus signal in order to trigger the shutter, and on a few other cameras, the focus signal may cause the camera to autofocus even when it is set to manual focus mode. The 3.5mm jack is electrically isolated from the USB ports in this revision. There is a workaround for using older units with Nikon cameras, which is to connect the camera cable to the light through a 3.5mm mono-to-stereo adapter. If doing this, it is important that the male end of the adapter used is a two-terminal (mono) plug, rather than a three-terminal (stereo) plug.

On the original PCB revision (26a901**a** marked on label), the 3.5mm jack is not electrically isolated. If planning to tether the camera to a computer while controlling the shutter using a light source with this PCB, test that the camera and cable are wired correctly first. Connect both the shutter control cable and a USB cable to the camera, and touch the tip of the 3.5mm plug to the exposed metal shell of the USB connector. If this *does not* trigger the camera shutter, the internal wiring of the camera or cable is likely reversed from the de facto standard and connecting the camera to both the light source and computer at the same time may cause issues.

### frequently asked questions

See [here](https://jackw01.github.io/scanlight/#part-3-responses-to-frequent-questions-and-comments)

### firmware updates

The web app will automatically notify if a firmware update is available and show a button to put the device into firmware update mode. To manually enter firmware update mode, press and hold down the **DFU mode button** while connecting the **left USB-C port** to a computer. The light source will show up as a USB storage device, and a firmware binary file can be copied to this device to update the firmware.

### cleaning precautions

Cleaning the acrylic diffuser panel with cleaning solutions containing high concentrations of isopropanol, other organic solvents, or ammonia can cause crazing or cracking of the acrylic. If needed, use a cleaner meant for eyeglasses or a diluted household all-purpose cleaner like Simple Green. Do not spray liquids directly on the light source.

## technical details

### dimensions



### film carrier compatibility

Adapters are available for improved usability with [toneCarrier](https://tonephotographic.com/) and [Valoi 360 Advancer](https://cinestillfilm.com/products/valoi360-advancer) film carriers. Drawings of the adapters with critical dimensions are included below for reference; the dimensions of these third-party film carriers are not published by the manufacturers and are subject to change, so please use these drawings to verify compatibility with your film carriers before buying.

#### toneCarrier 35mm/120 adapter


<small>All dimensions in millimeters. This adapter is NOT compatible with the old 35mm toneCarrier design found on Printables.com. As of 2026-05-29, the design has been changed to increase the spacing between the bezel and the toneCarrier to 5mm to accommodate  toneCarrier tray accessories.</small>

#### Valoi 360 Holder/Advancer adapter


<small>All dimensions in millimeters. Mounting holes are sized for M4 socket head cap screws. As of 2026-06-20, the design has been updated to support using the Valoi 360 35mm and medium format film holders without the Advancer. The offset mounting slots and removable snap-in mask are for use with the 35mm holder which has an off-center film gate.</small>

### optical design

Scanlight v4 uses a very simple optical design consisting of a matte white acrylic diffuser panel and a diffusely reflective housing with angled walls and chamfered corners to reduce brightness falloff. Compared to scanlight v2/v3, the light source has been changed from six LED clusters to nine and the diffuser box has been tweaked to sacrifice lighting uniformity outside of the central ~6x7cm area for better brightness and chroma uniformity inside that area. In RGB mode, scanlight v4 has improved lighting uniformity over scanlight v2/v3, and lighting uniformity in both RGB and white modes over the 6x7 image area is similar to big scanlight's lighting uniformity over the 4x5" image area.



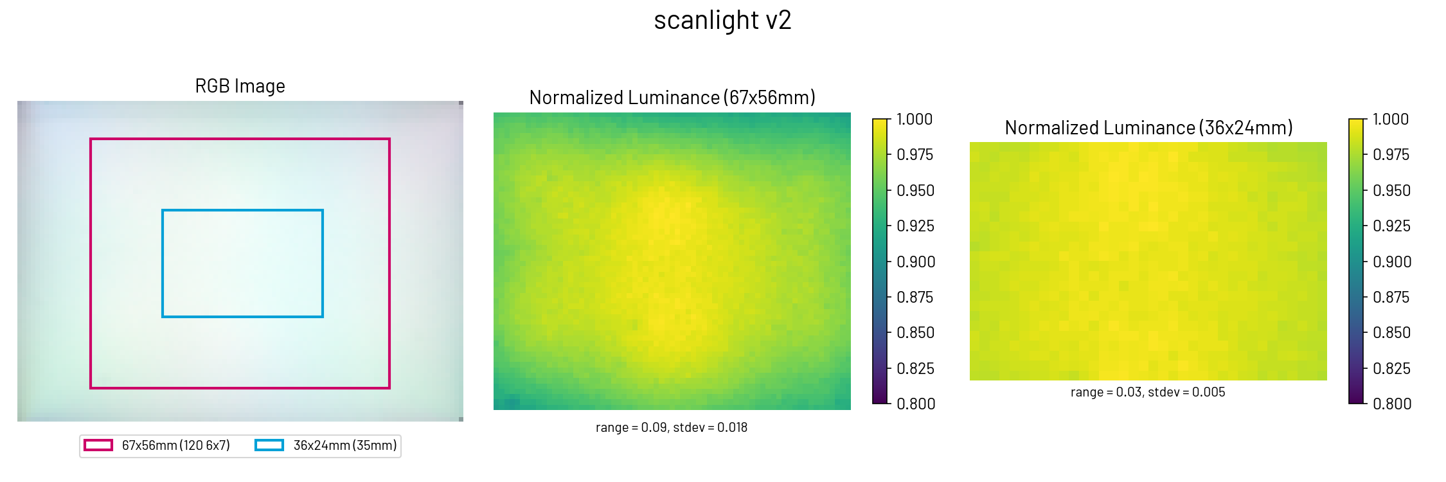
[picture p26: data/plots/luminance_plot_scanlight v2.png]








### film carriers

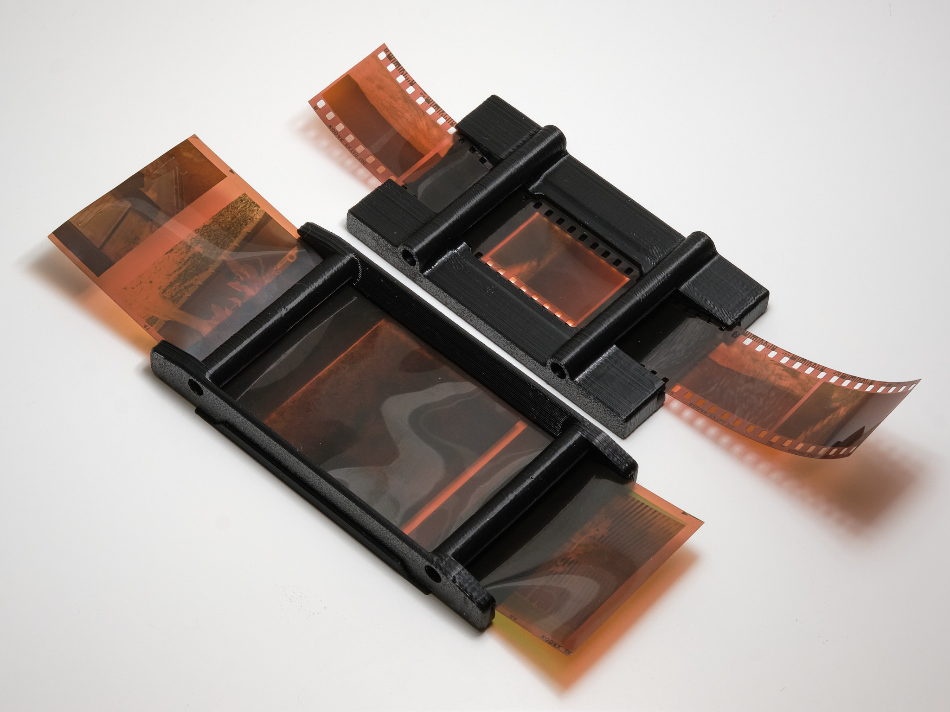
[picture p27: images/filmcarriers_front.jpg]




The 35mm and medium format film carriers use a double S-curve design to keep the film flat and have a small film-to-light distance (~5mm) to minimize vignetting. Both film carriers feature interchangeable masks that snap into the back of the carrier to block stray light from reaching the camera, and the 35mm carrier has a snap-on hood to prevent external light from reflecting off the film. Medium format masks are available in all common sizes, and the film carrier exposes enough area to scan 6x9 negatives when no mask is installed. The double S-curve design is optimized for scanning full rolls or cut pieces >150mm in length; scanning shorter pieces may be difficult especially if the film is curled across its width.

As of September 2026, the film carriers now include separate 3D printed spring clips for mounting them securely to scanlight v4 in both upright and horizontal orientations, replacing the previous magnetic attachment method for horizontal usage.

### horizontal mounting

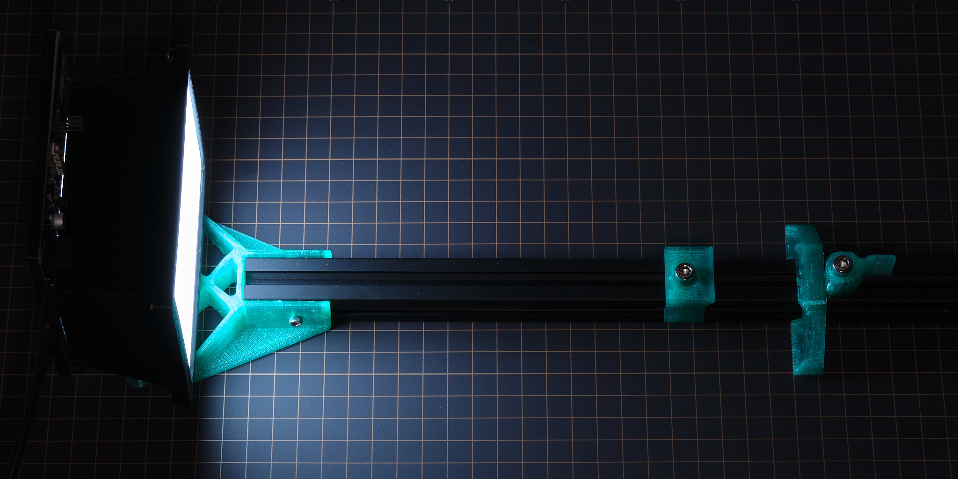
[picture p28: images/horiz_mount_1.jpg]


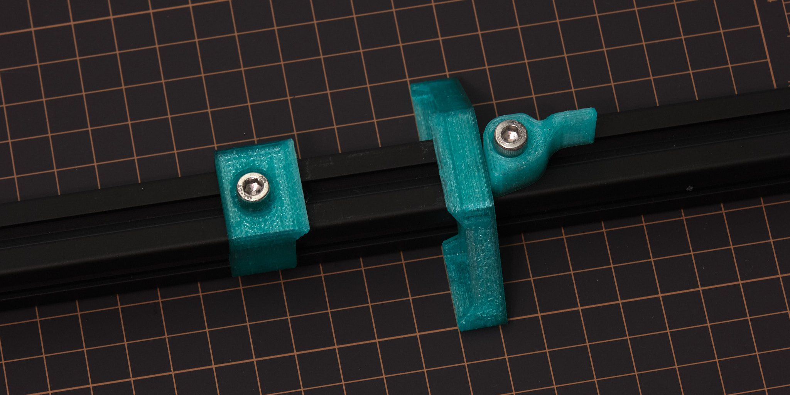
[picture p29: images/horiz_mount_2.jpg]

<small>HW v2 shown, v3 and v4 similar.</small>

As an alternative to using a tripod or vertical copy stand, designs for 3D printable parts for mounting the light source and a camera with an Arca-Swiss quick-release plate to a piece of 20x20mm T-slot aluminum extrusion are available. This mounting method accommodates cameras where the distance between the horizontal center plane of the lens and the bottom plane of the quick-release plate is at least 36 mm - the included 3D printable spacers can be used to offset the height of the light source to accommodate larger cameras.

For scanlight v4, horizontal mounting requires an alternate version of the main housing with added mounting bosses as shown below. The layout and size of the mounting bosses is the same as scanlight v2 and v3.



Design files are available [here](https://github.com/jackw01/scanlight/tree/main/3d/horizontal).

### PCBs

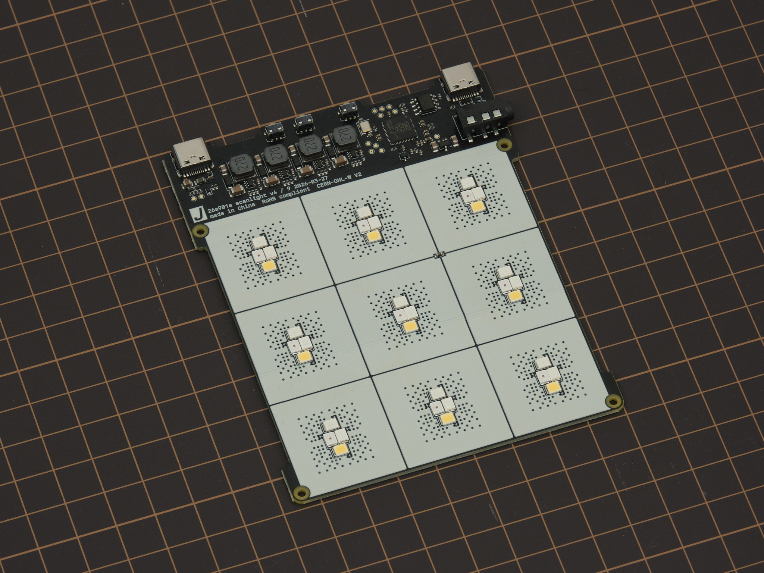
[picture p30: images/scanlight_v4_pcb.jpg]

<small>PCB rev. A shown, rev. B similar</small>

Scanlight v4 integrates a RP2040 32-bit ARM Cortex-M0+ microcontroller, four [TPS61169](https://www.ti.com/lit/ds/symlink/tps61169.pdf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) constant-current boost converters configured for 90mA output current at up to 38V, and an array of 36 2835 mid-power LEDs on a 107.4x87mm four-layer PCB. Revision B (26a901**b** marked on label) adds electrically isolated photorelay output drivers for both the shutter and focus signals on the 3.5mm jack.

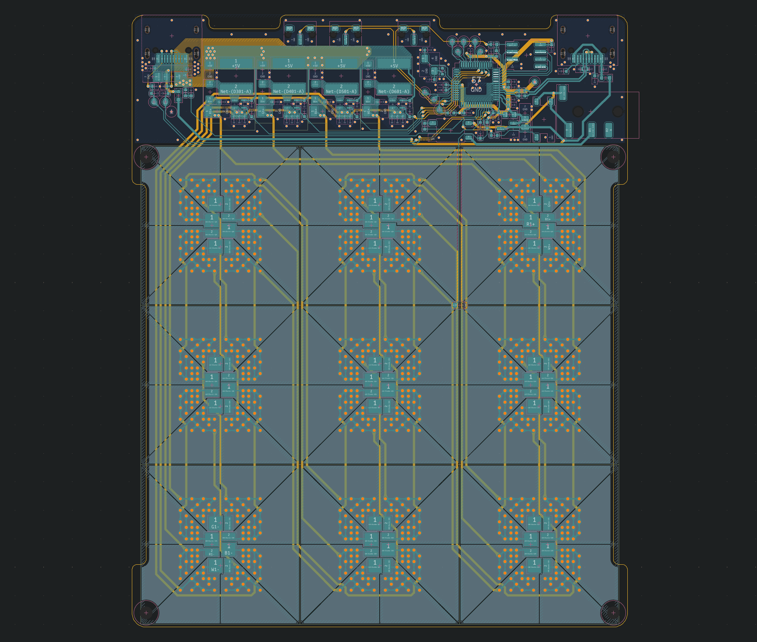
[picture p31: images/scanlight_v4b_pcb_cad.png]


All design files for the PCB can be downloaded from the [GitHub repository](https://github.com/jackw01/scanlight/tree/main/pcb/sl_v4b).

[scanlight v4b schematic (PDF)](pcb/sl_v4b/sl_v4b_20260628.pdf)

[scanlight v4b PCB BOM (CSV)](pcb/sl_v4b/sl_v4b_20260628.csv)

### mechanical design

STEP files for all parts of the light source, film carrier adapters, and film carriers can be downloaded from the [GitHub repository](https://github.com/jackw01/scanlight/tree/main/3d).

### firmware and web app

The [source code for the RP2040 firmware](https://github.com/jackw01/scanlight/tree/main/automation/firmware_bsl1), a [ready-to-flash firmware binary](https://github.com/jackw01/scanlight/blob/main/automation/sl4_controller_v1.1.uf2), and the [source code for the remote control web app](https://github.com/jackw01/scanlight/tree/main/automation/app_bsl) can be downloaded from the GitHub repository. The firmware is implemented using the RP2040 SDK and the web app is made with [Vue](https://github.com/vuejs) and [Vuetify](https://github.com/vuetifyjs/vuetify).

Interested in building your own control software? The USB serial communication interface used by the firmware is fully documented [here](https://github.com/jackw01/scanlight/blob/main/automation/bsl_control_interface.md).

### license

The PCB schematic, layout, and Gerber files and the 3D CAD files for this project are released under the [CERN Open Hardware Licence Version 2 - Weakly Reciprocal](https://choosealicense.com/licenses/cern-ohl-w-2.0/) (CERN-OHL-W V2). Software and firmware are released under the MIT License.

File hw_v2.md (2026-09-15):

# scanlight v3 info

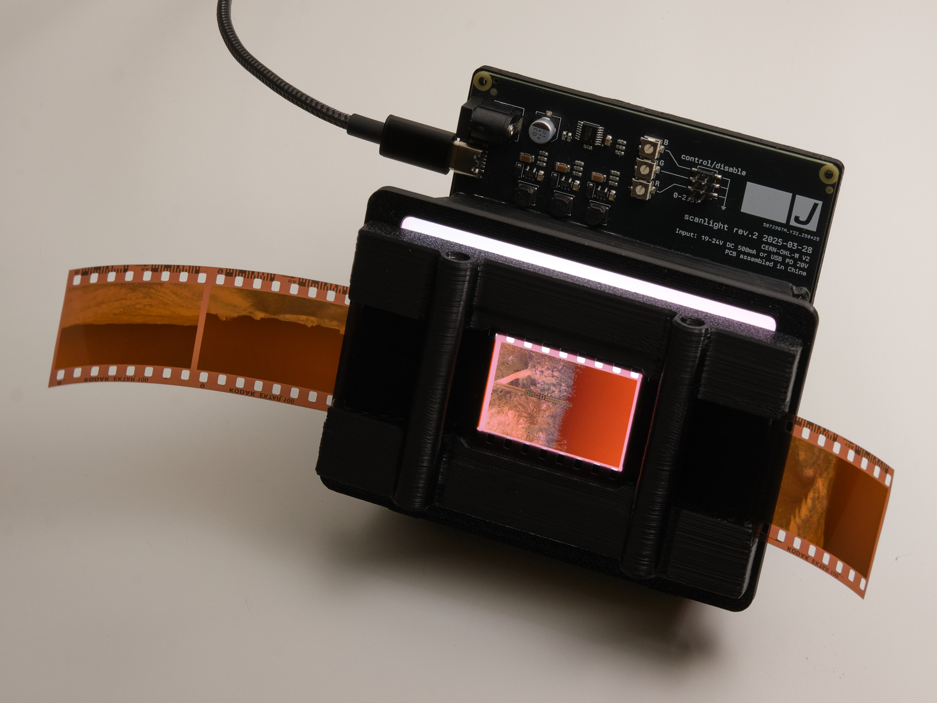
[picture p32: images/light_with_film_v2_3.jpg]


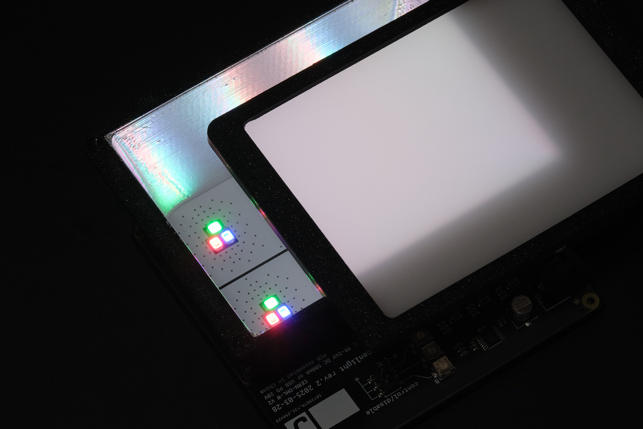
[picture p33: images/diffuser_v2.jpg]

<small>HW v2 shown, v3 similar.</small>

## features
* Illuminated area dimensions: 100x74mm
* Suitable for use with 35mm and medium format film
* Six each of deep red (665nm), green (525nm), and deep blue (455nm) LEDs
* Front diffuser made from fingerprint- and scratch-resistant textured acrylic
* 3D printed ABS housing with high reflectivity interior achieved using aluminum pigment paint
* Capable of per-channel brightness control, and **tethered remote control from a computer** (new in v3)
* Designed for vertical use with a copy stand or horizontal use with optional threaded insert mounting points
* Magnetically-attached 35mm and medium format film carriers available
* Powered using either a 19-24V barrel jack AC adapter or a 20V-capable USB PD supply
* Open source hardware and software

Original article on scanning film with narrowband light (with sample scans): *[A Better Light Source For Scanning Color Negative Film](./README.md)*.

I will be building a limited quantity of scanlight units for sale - for more details, see [my shop on Ko-Fi](https://ko-fi.com/jackw01/shop).

Low-cost upgrade kits are available to v1 buyers: request one [here](https://ko-fi.com/s/b195e963f8).

## technical info

### optical design

In terms of light uniformity, the new diffuser design is significantly better than version 1 and is generally on par with other uniform light sources. Scanlight 2 and 3 perform nearly as well when evaluated for 6x8 medium format film as scanlight 1 does when evaluated for 135 film:



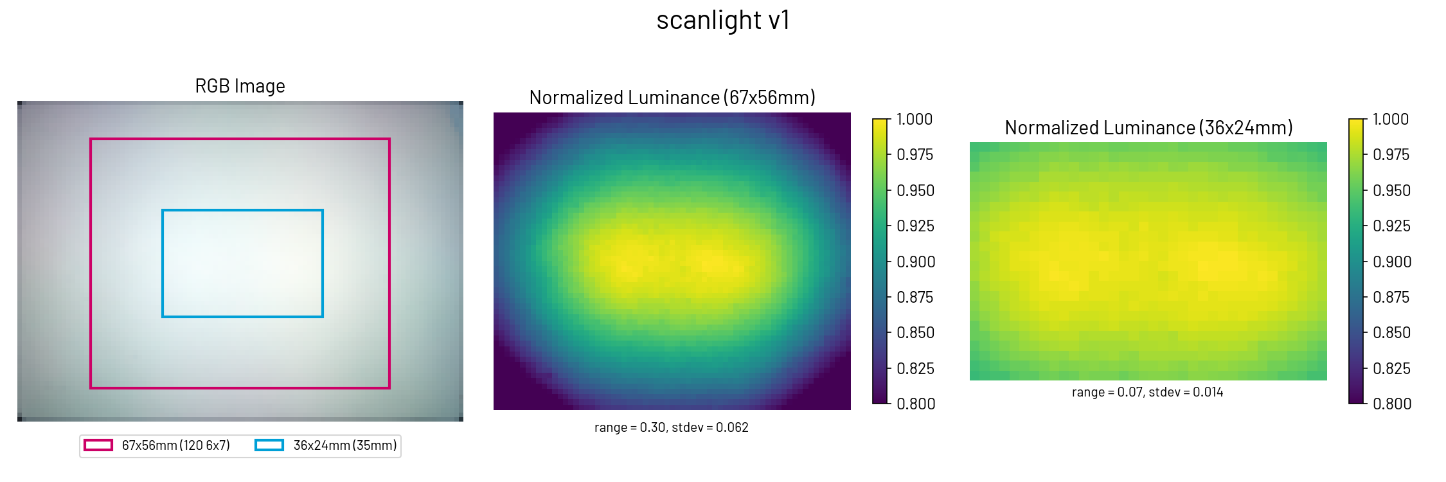
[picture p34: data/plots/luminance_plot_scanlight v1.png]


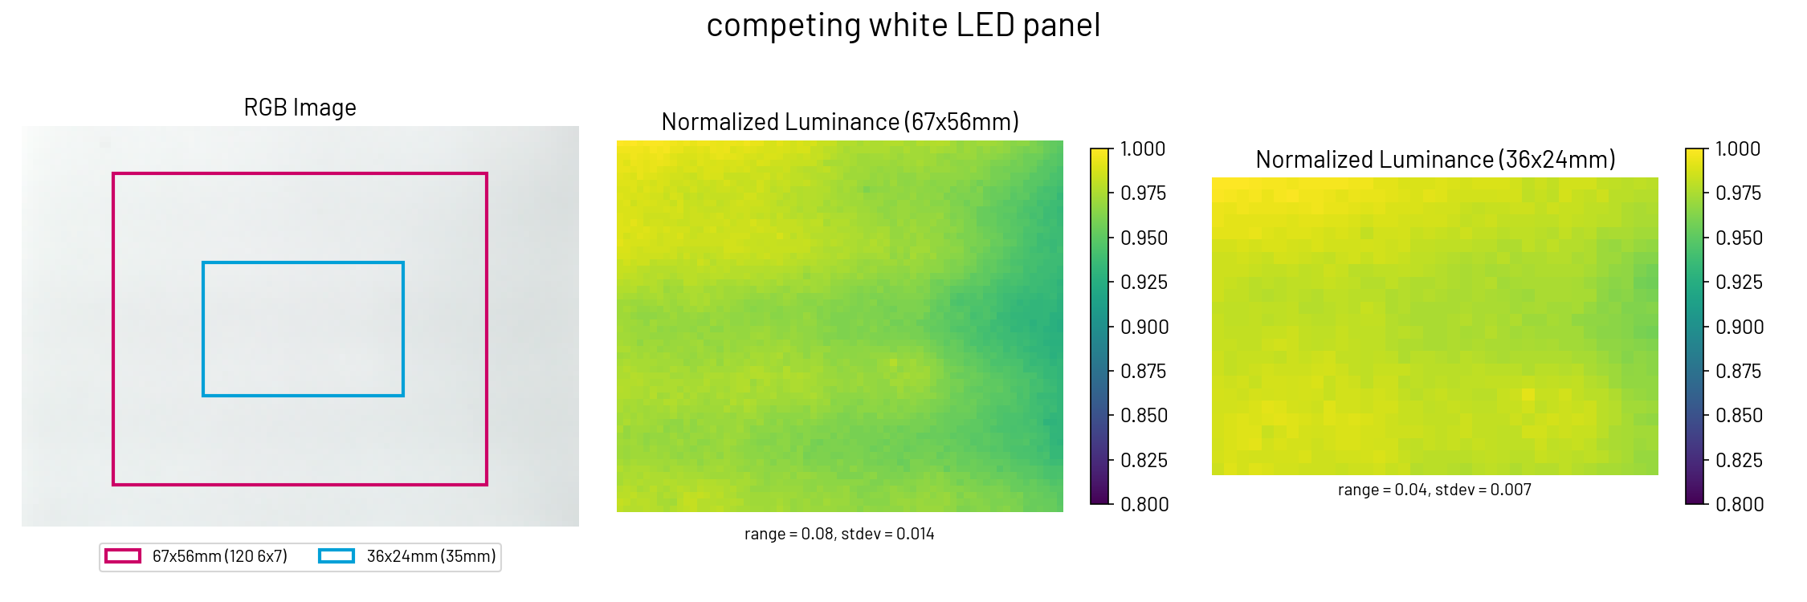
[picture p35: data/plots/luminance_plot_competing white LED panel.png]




<p align="center"><small>Comparison: scanlight 1 vs scanlight 2 vs competing white LED light panel vs LCD monitor. All images show a 100x72mm physical area at the center of each light source. A thin plastic diffuser was placed over the LCD display to avoid moiré effect.</small></p>

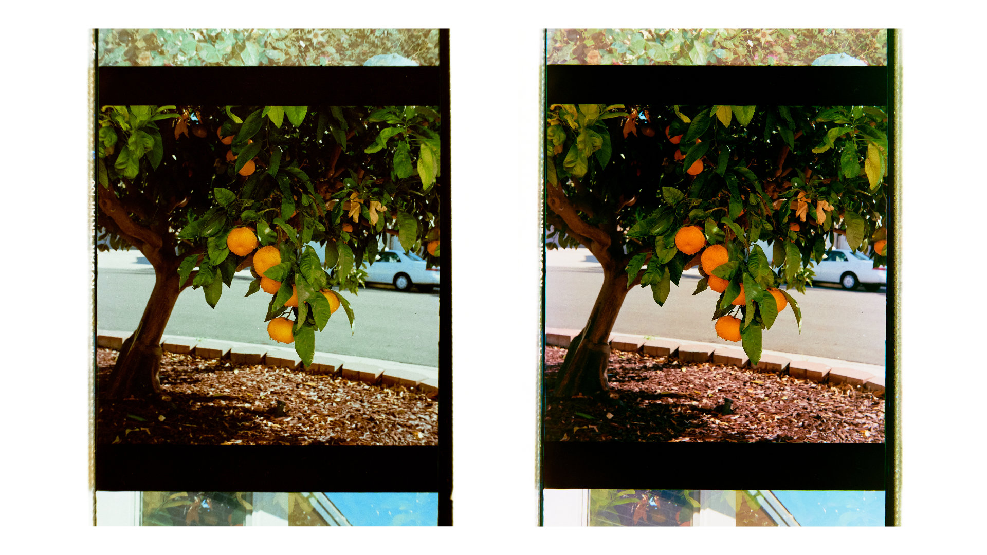
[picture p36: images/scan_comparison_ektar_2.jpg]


<p align="center"><small>Comparison: white LED light panel (left) vs scanlight 2 (right)</small></p>

Both of these scans have been inverted and color balanced *without* any calibration for light source luminance or color uniformity. Negatives are 6x6 medium format Kodak Ektar 100.

All this is achieved using a simpler optical design inspired by professional film scanner light sources, using a reflective housing and single high-quality acrylic diffuser to improve both color mixing and luminance uniformity over version 1. The diffuser is made from ACRYLITE® Satinice light-diffusing acrylic, which has a finely textured surface that hides fingerprints and scratches and is easy to keep clean.

**Note: Using Lens Cast Calibration in Capture One or Flat-Field Correction in Lightroom is still highly recommended no matter which light source you use.**

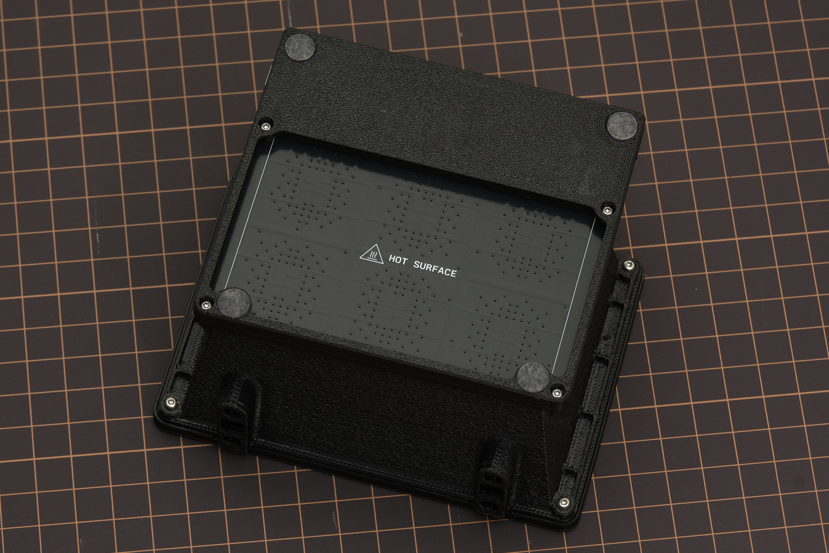
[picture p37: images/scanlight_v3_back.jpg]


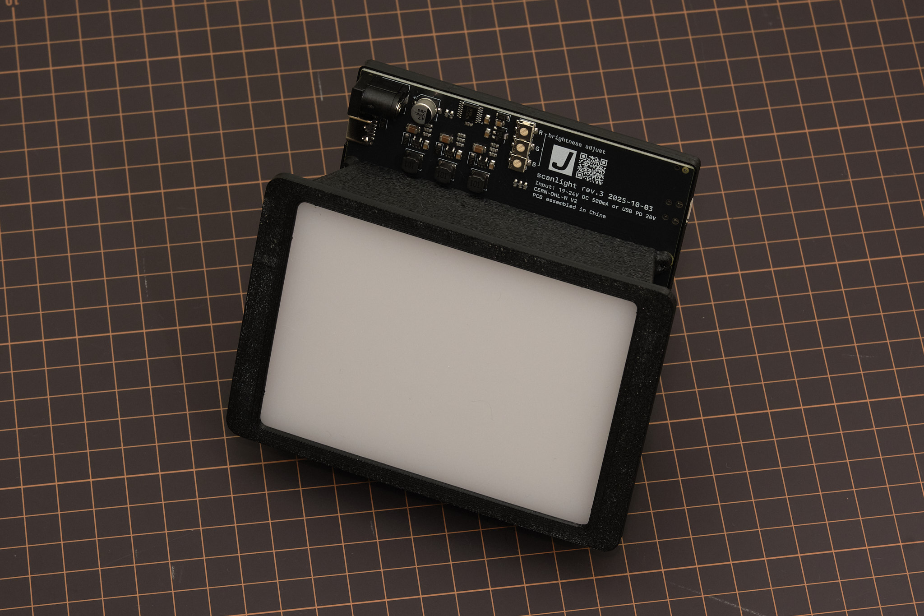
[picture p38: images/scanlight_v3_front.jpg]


### film carriers



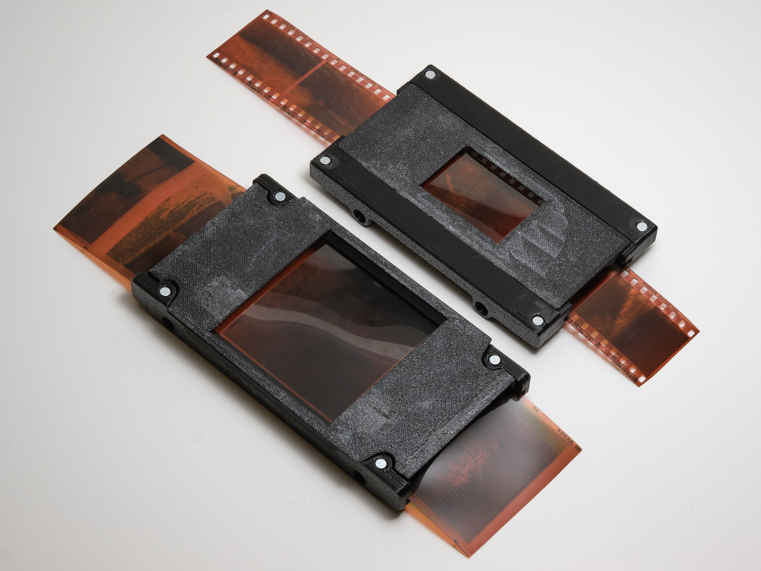
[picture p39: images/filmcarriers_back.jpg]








The 35mm and medium format film carriers use a double S-curve design to keep the film flat and have a small film-to-light distance (35mm: 2.8mm, medium format: 3.8mm) to minimize vignetting. Both film carriers feature interchangeable masks that snap into the back of the carrier to block stray light from reaching the camera, and the 35mm carrier has a snap-on hood to prevent external light from reflecting off the film. Medium format masks are available in all common sizes, and the film carrier exposes enough area to scan 6x9 negatives when no mask is installed. The double S-curve design is optimized for scanning full rolls or cut pieces >150mm in length; scanning shorter pieces may be difficult especially if the film is curled across its width.

### horizontal mounting




<small>HW v2 shown, v3 similar.</small>

As an alternative to using a tripod or vertical copy stand, 3D printable parts for mounting the light source and a camera with an Arca-Swiss quick-release plate to a piece of 20x20mm T-slot aluminum extrusion are included. This mounting method will accommodate cameras where the distance between the center of the lens and the bottom plane of the quick-release plate is at least 36 mm - the included 3D printable spacers can be used to offset the height of the light source to accommodate larger cameras.

Design files are available [here](https://github.com/jackw01/scanlight/tree/main/3d/horizontal).

### note on brightness enhancing film

When installed below the main diffuser and a significant distance away from the LEDs, brightness enhancing film appears to create hotspots in the spaces in the center of each group of 4 LED clusters. When installed above the main diffuser, it introduces vignetting around the center of the image. Brightness enhancing film also scratches easily and is difficult to keep free of dust and oils. Because of this, the v2 diffuser does not use brightness enhancing film internally. Separate sheets of BEF (3M BEF3-T-155n; equivalent to Cinestill CS-LiteBrite+) will be available as a low-cost addon for anyone who wants to experiment with it.



### PCB details

The version 3 PCB is an incremental improvement over version 2 and allows a Raspberry Pi Pico microcontroller to be attached directly to the main board, which enables full control of the light from a computer using the web app here: https://jackw01.github.io/scanlight/automation/app/dist/index.html. This functionality can also be enabled on v2 by connecting an external Raspberry Pi Pico to the header on the PCB.

All design files can be downloaded from the [GitHub repository](https://github.com/jackw01/scanlight/tree/main/pcb/sl_v3).



[PCB Schematic as PDF (Rev. 3)](pcb/sl_v3/scanlight_schematic_v3_20251023.pdf)

[PCB BOM](pcb/sl_v3/scanlight_bom_v3_20251023.csv)

[LED datasheet](https://downloads.cree-led.com/files/ds/j/JSeries-2835-Color.pdf)

### mechanical design

STEP files for all parts of the light source and film carriers can be downloaded from the [GitHub repository](https://github.com/jackw01/scanlight/tree/main/3d).

### firmware and web app

**As of July 2026, scanlight v2 and v3 are supported by the updated firmware and web app used by scanlight v4 and big scanlight.** The new web app is available [here](https://jackw01.github.io/scanlight/automation/app_bsl/dist/index.html) and the firmware binary for v2/v3 is [here](https://github.com/jackw01/scanlight/blob/main/automation/sl2_controller_v1.2.uf2). A Chromium-based web browser is required as other browser engines do not support the WebUSB/WebSerial API.

The deprecated web app for controlling scanlight v2/v3 is available [here](https://jackw01.github.io/scanlight/automation/app/dist/index.html).

The [source code for the old Pi Pico firmware](https://github.com/jackw01/scanlight/tree/main/automation/firmware_sl2), a [ready-to-flash firmware binary](https://github.com/jackw01/scanlight/blob/main/automation/sl2_controller_v1.2.uf2), and the [source code for the remote control web app](https://github.com/jackw01/scanlight/tree/main/automation/app_sl2) can be downloaded from the GitHub repository. The firmware is implemented using the RP2040 SDK and the web app is made with [Vue](https://github.com/vuejs) and [Vuetify](https://github.com/vuetifyjs/vuetify).

### license

The PCB schematic, layout, and Gerber files and the 3D CAD files for this project are released under the [CERN Open Hardware Licence Version 2 - Weakly Reciprocal](https://choosealicense.com/licenses/cern-ohl-w-2.0/) (CERN-OHL-W V2). Software and firmware are released under the MIT License.

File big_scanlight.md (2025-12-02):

# big scanlight info & user manual

## features
* Illuminated area dimensions: 108x134mm (4.25x5.25in)
* Suitable for use with 35mm, medium format, and 4x5 film
* 20 each of deep red (665nm), green (525nm), deep blue (455nm), and 95CRI white, and 16 infrared (850nm) LEDs mounted on aluminum PCB for optimal heat dissipation
* Up to 15EV brightness (1/500s at f/8 ISO 100) in RGB combined mode, 14EV in white mode
* Better light uniformity over medium format frame sizes than scanlight v2/v3
* Diffuser made from fingerprint- and scratch-resistant textured acrylic
* 3D printed ABS housing
* Fully controllable via USB with web app
* On/off and mode toggle buttons on light source for standalone usage
* Compatible with accessories made for Negative Supply 4x5" light sources
* Simple 35mm and medium format film carriers available
* Powered using any USB-C power source (at least 9V at 18W required for full brightness)
* Open source hardware and software

Original article on scanning film with narrowband light: *[A Better Light Source For Scanning Color Negative Film](./README.md)*.

## instructions



### basic operation

The light source is powered via the **left USB-C port**. A USB-C PD power source that can supply at least 2A at 9V (e.g. most USB-C phone, tablet, and laptop chargers) is required to operate at full brightness; however, the light will still operate at reduced brightness from any USB power source capable of delivering at least 2A at 5V (e.g. almost all USB chargers from the last 10 years.)

*It is not recommended to power the light from a USB port on a computer; a dedicated USB power supply should be used instead.*

Press the **upper button** to toggle the light on and off. Press the **lower button** to toggle between narrowband RGB and 95CRI white modes. The buttons work even when the light is not connected to a computer. The default RGB channel brightnesses in this mode can be configured from the GUI, as explained below.

To adjust color and brightness and automate the process of scanning red, green, and blue channels separately, the light source can be connected to a computer via the **right USB-C port** and controlled with the web app located [here](https://jackw01.github.io/scanlight/automation/app_bsl/dist/index.html). The web app requires a Chromium-based web browser.

In the **Manual Control** panel of the web app, the red, green, and blue channel brightnesses can be adjusted and the color channels can be turned on individually or together. In **RGB** (narrowband trichromatic) mode, the red, green, and blue LEDs are on at the same time. In **White** mode, only the 95CRI white LEDs are on. The red, green, blue, and infrared LEDs can also be turned on individually; the RGB channel brightness adjustments still apply in this case.

The **RGB Presets** panel of the web app allows RGB channel brightness settings to be stored to and loaded from web browser local storage, using the **Load**, **Create**, **Rename**, and **Delete** buttons.

The **Set as Default** and **Load Default** buttons refer to the default RGB preset, which is stored onboard the light source. This functionality is separate from presets stored in the web app and sets the RGB channel brightnesses used when the light is first powered on and when it is not connected to a computer.

### remote shutter release usage

The **3.5mm jack** can be connected to a camera so that the shutter can be remotely triggered from the web app. The length of the shutter trigger pulse and the delay after are both configurable. The default settings should work for most use cases. Operation in the **R,G,B** mode is shown in the timing diagram below; the other modes work similarly.



A cable with a male 3.5mm plug (otherwise known as a headphone connector) on one end and a camera-specific connector on the other end is required to use this functionality. A wide variety of these cables are available from online retailers; I cannot vouch for the quality of any of them or verify that a specific cable will work, as wiring diagrams are almost never published by the manufacturers.

Because the 3.5mm jack is not electrically isolated from the USB ports, it is recommended out of an abundance of caution that the camera should not be connected to the same USB power supply or computer as the light source when using the remote shutter control function. For most cameras, doing so will not cause any issues, but because there is no formal standard for how remote shutter cables or connectors are wired, some cameras may exist that could be damaged by such a setup.

### firmware updates

The web app will automatically notify if a firmware update is available and show a button to put the device into firmware update mode. To manually enter firmware update mode, press and hold down the **DFU mode button** while connecting the **right USB-C port** to a computer. The light source will show up as a USB storage device, and a firmware binary file can be copied to this device to update the firmware.

### cleaning precautions

Cleaning the acrylic diffuser panel with cleaning solutions containing high concentrations of isopropanol, other organic solvents, or ammonia can cause crazing or cracking of the acrylic. If needed, use a cleaner meant for eyeglasses or a diluted household all-purpose cleaner like Simple Green. Do not spray liquids directly on the light source.

## technical details

### optical design

### PCBs

### firmware and web app

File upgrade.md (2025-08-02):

## v1 to v2 upgrade instructions

### 1

Remove the four screws holding the PCB to the diffuser housing using a 1.5mm hex screwdriver or allen key and separate the PCB from the housing.





### 2

Clip the baseplate onto the PCB, starting at the top edge of the PCB.





### 3

Blow any dust or debris out of the inside of the new diffuser housing. Place the PCB onto the new diffuser housing and install the four screws. Some downwards pressure will be needed when starting to thread the screws into the plastic.





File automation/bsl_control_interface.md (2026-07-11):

# big scanlight / scanlight v4 control interface documentation

## firmware releases

All scanlight hardware revisions now run the same firmware, with hardware support defined by compile-time flags. The old scanlight v2 firmware (`firmware_sl2` folder) and web app (`app_sl2` folder) are deprecated.

| version | commit  | FW_VERSION_ID | note |
| --- | --- | --- | --- |
| 1.0 | 43c5425 | 0 | initial release for big scanlight v1  |
| 1.1 | 07a1f8f | 1 | add compatibility for scanlight v4 |
| 1.2 | 5130904 | 2 | add compatibility for scanlight v4 rev. b PCB, scanlight v2/v3 |

The information in this document is current as of firmware version 1.2.

## USB connection

Scanlight enumerates as a USB Serial CDC device, which can be accessed by, for example, the WebSerial API or PySerial.

## communication protocol overview

Both host-to-device and device-to-host communications use the same packet format. The data length byte may be zero, in which case it is the last byte in the packet.

| byte index | description |
|---|---|
| 0 | start byte (always 0xFE) |
| 1 | packet header |
| 2 | packet data length |
| >= 3 | packet data |

### valid packet headers

#### host-to-device

```
PKT_H2D_SET_COLOR = 0
PKT_H2D_GET_DEFAULT_RGB = 1
PKT_H2D_GET_FW_VERSION = 2
PKT_H2D_SHUTTER_PULSE = 3
PKT_H2D_DFU_MODE = 4
PKT_H2D_SET_TRIM = 5
PKT_H2D_GET_TRIM = 6
PKT_H2D_SET_FOCUS = 7
```

#### device-to-host

```
PKT_D2H_LED_TEMP = 1
PKT_D2H_VBUS = 2
PKT_D2H_FW_VERSION = 3
PKT_D2H_DEFAULT_RGB = 4
PKT_D2H_TRIM = 5
```

### web app initial communication flow

1. Host sends `PKT_H2D_GET_FW_VERSION` and waits for response. If device firmware version ID is less than `LatestFWVersionID` (defined in `config.js`), notify user. `LatestFWVersionID` is only updated when API-breaking changes are made or significant new firmware features are added.
2. Host sends `PKT_H2D_GET_DEFAULT_RGB` and `PKT_H2D_GET_TRIM` and waits for response. Response values are used to populate GUI.

## packet reference

### host-to-device

#### PKT_H2D_SET_COLOR

|properties||
|---|---|
| header | 0 |
| data length | 6 |

| data byte index | description |
|---|---|
| 0 | red channel value (0 to 255) |
| 1 | green channel value (0 to 255) |
| 2 | blue channel value (0 to 255) |
| 3 | white channel value (0 to 255) |
| 4 | IR channel value (0 to 255) |
| 5 | save preset flag (0 to 1) |

Requests the device to update the LED driver state. The device firmware performs input validation, ensuring that maximum power is reduced if operating more than one channel at a time with an insufficient power supply and preventing the white and IR channels from being operated at the same time as the RGB channels. If the 'save preset flag' byte is set to 1, the red, green, and blue channel settings will be saved to nonvolatile memory as the default RGB setting which is used at power-on. The application software should only set this byte to 1 when absolutely needed, as the nonvolatile memory has a finite write cycle lifespan. *Note: IR channel value is ignored by the scanlight v4 firmware variant.*

#### PKT_H2D_GET_DEFAULT_RGB

|properties||
|---|---|
| header | 1 |
| data length | 0 |

Requests the device to respond with `PKT_D2H_DEFAULT_RGB`.

#### PKT_H2D_GET_FW_VERSION

|properties||
|---|---|
| header | 2 |
| data length | 0 |

Requests the device to respond with `PKT_D2H_FW_VERSION`.

#### PKT_H2D_SHUTTER_PULSE

|properties||
|---|---|
| header | 3 |
| data length | 1 |

| data byte index | description |
|---|---|
| 0 | shutter pulse length in 10-millisecond units (0 to 255) |

Requests the device to output a camera shutter trigger pulse. Timing of pulse length is handled by the device firmware, and timing between pulses is to be handled by the application software.
With Fujifilm mirrorless cameras, the minimum shutter pulse length is around 300ms and the minimum pulse interval is around 1000ms in single-shot drive mode. Using a bracketing or continuous drive mode on the camera is necessary for faster shutter actuation. Experimentation with other camera brands is needed.

#### PKT_H2D_DFU_MODE

|properties||
|---|---|
| header | 4 |
| data length | 0 |

Requests the device to enter device firmware upgrade (DFU) mode. USB serial connection will be lost when this packet is processed by the device.

#### PKT_H2D_SET_TRIM

|properties||
|---|---|
| header | 5 |
| data length | 4 |

| data byte index | description |
|---|---|
| 0 | red channel value (-127 to 127 - two's complement format) |
| 1 | green channel value (-127 to 127 - two's complement format) |
| 2 | blue channel value (-127 to 127 - two's complement format) |
| 3 | white channel value (-127 to 127 - two's complement format) |

Requests the device to set the red, green, blue, and white channel trimming settings (the difference between the left and right side LED driver PWM levels). New trimming settings are automatically saved to nonvolatile memory when received. *Note: this packet is ignored by the scanlight v4 firmware variant.*

#### PKT_H2D_GET_TRIM

|properties||
|---|---|
| header | 6 |
| data length | 0 |

Requests the device to respond with `PKT_D2H_TRIM`. *Note: this packet is ignored by the scanlight v4 firmware variant.*

#### PKT_H2D_SET_FOCUS

|properties||
|---|---|
| header | 7 |
| data length | 1 |

| data byte index | description |
|---|---|
| 0 | focus signal state |

Requests the device to set the state of the camera focus control signal (equivalent to half-pressing the shutter button). Setting this signal may be necessary for some cameras to actuate the shutter. On some cameras it may cause the shutter to respond more quickly (good), and on some cameras it may cause undesired autofocusing even when the camera is in manual focus mode (bad), therefore it should be independently controllable from the shutter. *Note: this packet is ignored if the hardware does not support controlling the camera focus signal. Currently, only scanlight v4 with the 26a902b PCB revision supports this.*

### device-to-host

#### PKT_D2H_LED_TEMP

|properties||
|---|---|
| header | 1 |
| data length | 4 |

| data byte index | description |
|---|---|
| 0-3 | LED temperature in millidegrees Celsius (32-bit signed integer in two's complement format) |

Telemetry packet sent automatically by the device every 200ms. *Note: not supported on big scanlight rev1 hardware (driver PCB PN 25d902a)*

#### PKT_D2H_VBUS

|properties||
|---|---|
| header | 2 |
| data length | 4 |

| data byte index | description |
|---|---|
| 0-3 | power USB port VBUS voltage in millivolts (32-bit signed integer in two's complement format) |

Telemetry packet sent automatically by the device every 200ms. *Note: there is no need for the application software to do anything in response to this packet. USB port voltage changes are handled by the device firmware.*

#### PKT_D2H_FW_VERSION

|properties||
|---|---|
| header | 3 |
| data length | 4 |

| data byte index | description |
|---|---|
| 0-1 | device firmware version ID (16-bit unsigned integer) |
| 2-3 | device hardware version ID (16-bit unsigned integer) |

Reports the device firmware and hardware version IDs.

#### PKT_D2H_DEFAULT_RGB

|properties||
|---|---|
| header | 4 |
| data length | 3 |

| data byte index | description |
|---|---|
| 0 | red channel value (0 to 255) |
| 1 | green channel value (0 to 255) |
| 2 | blue channel value (0 to 255) |

Reports the default RGB settings (used at power-on) stored in nonvolatile memory.

#### PKT_D2H_TRIM

|properties||
|---|---|
| header | 5 |
| data length | 4 |

| data byte index | description |
|---|---|
| 0 | red channel value (-127 to 127 - two's complement format) |
| 1 | green channel value (-127 to 127 - two's complement format) |
| 2 | blue channel value (-127 to 127 - two's complement format) |
| 3 | white channel value (-127 to 127 - two's complement format) |

Reports the current channel trimming settings stored in nonvolatile memory. *Note: only supported by the big scanlight firmware variant.*

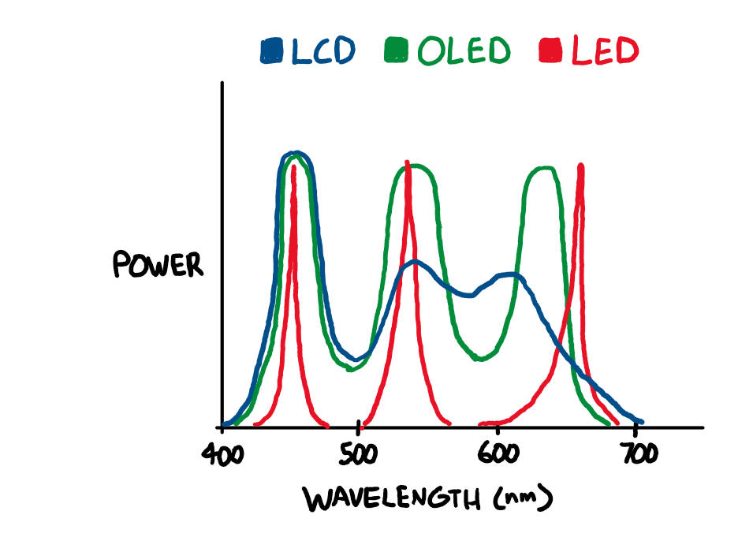
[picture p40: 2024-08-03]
images/oled_and_lcd_spectra.png

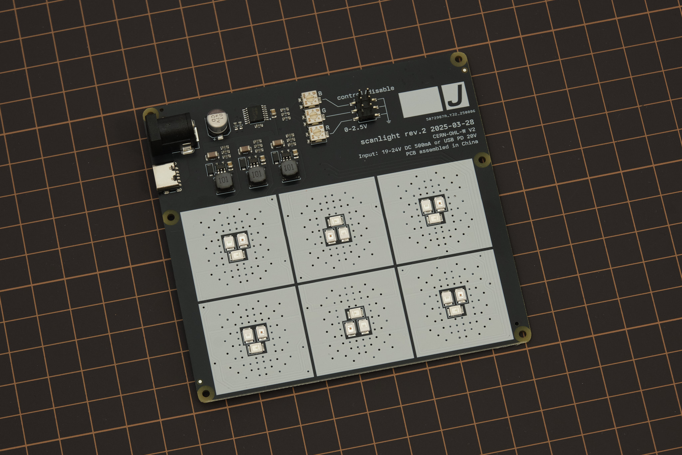
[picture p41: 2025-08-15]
images/pcb_r2.jpg

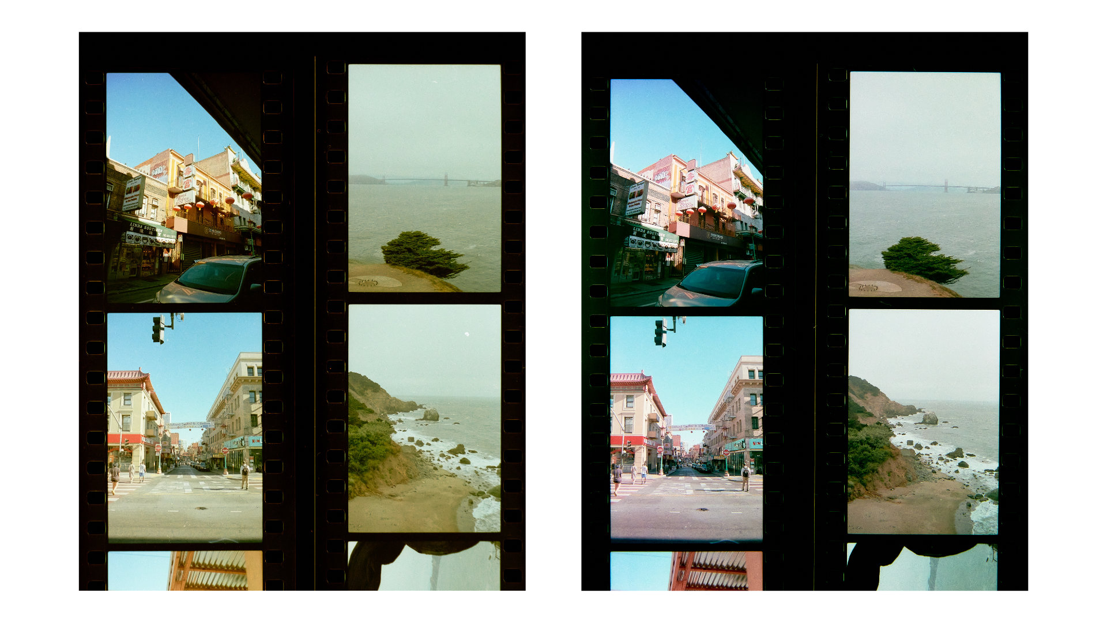
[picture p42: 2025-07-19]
images/scan_comparison_aerocolor_2.jpg

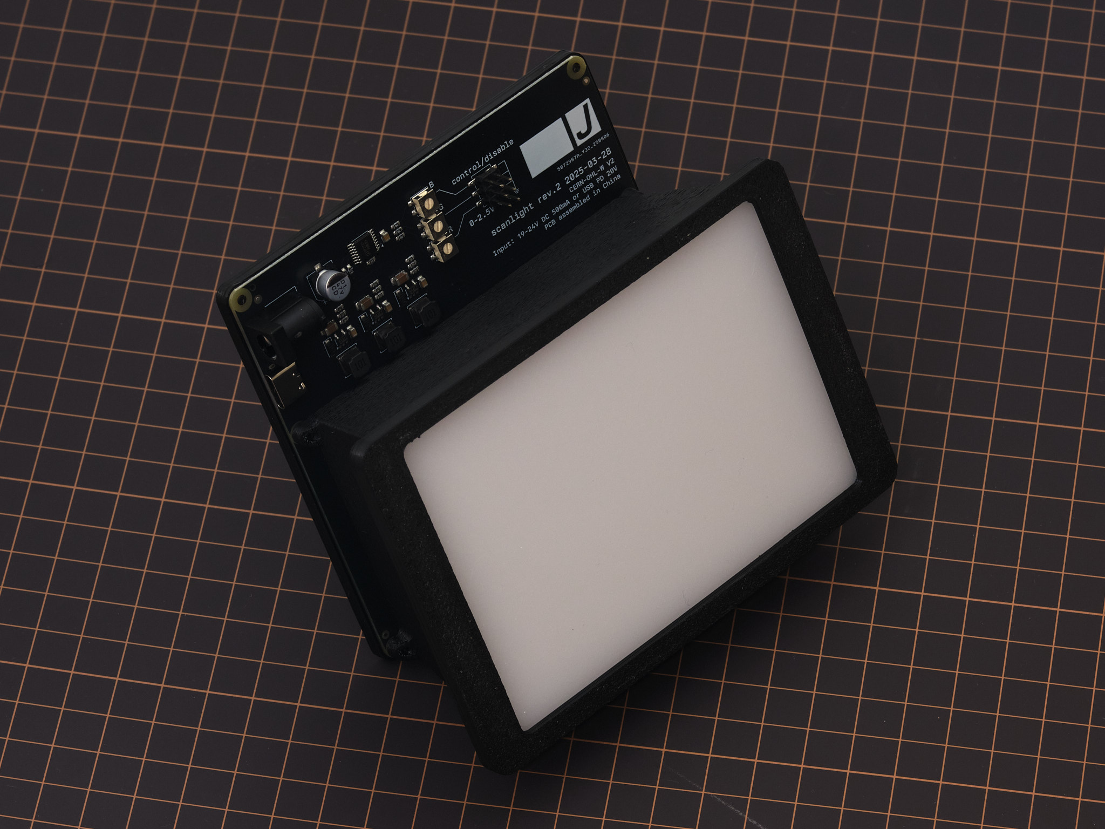
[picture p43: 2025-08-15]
images/scanlight_v2_front.jpg

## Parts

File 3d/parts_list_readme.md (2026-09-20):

# parts list

## 3d printing notes
Print all parts in black ABS or ASA, using a 0.4mm or 0.6mm nozzle with 4 or 3 perimeters, respectively, 0.2mm layer height, and 30% infill. Fuzzy skin may be used on external contours only (**NOT** the painted interior surfaces of the diffuser box.) Printing orientation for all parts should be obvious based on the design. The "Support on Build Plate Only" or equivalent option should be used since several parts have counterbore holes.

## painting notes
The interior surfaces of the diffuser box housing must be painted with 2-3 coats of paint containing only extra fine leafing aluminum flake pigment, such as Dupli-Color CS101 or Rust-Oleum 7718830. The surface of the 3D printed part does not need to be meticulously prepared before painting; lightly scuffing the surface with Scotch-Brite or a brass wire brush is enough. Spray paints containing acetone or toluene can be used on ABS or ASA without primer. Painting this way will make any imperfections in the 3D print extremely visible; don't worry about it.

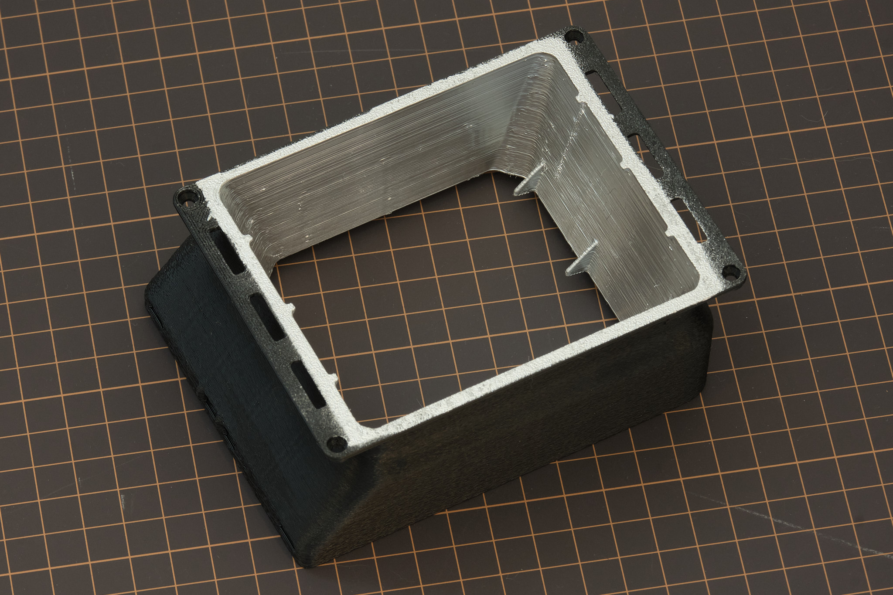
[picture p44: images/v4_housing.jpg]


Alternatively, the inside of the diffuser housing can be covered in aluminum foil tape. This can work relatively well if done carefully, but may not reach the same level of brightness uniformity as painting. Sanding the surface of the tape with ~300 grit sandpaper before applying it is recommended to reduce specular reflections.

## scanlight v4

[assembly instructions](./scanlight%20v4/assembly_instructions.md)

### scanlight v4 only
* assembled PCB
* front diffuser (4x3.25x0.118" ACRYLITE® Satinice WD008 DF light-diffusing acrylic, or standard white acrylic with <50% light transmittance)
* 26A101D 3D printed diffuser box housing (use variant E for horizontal mounting option)
* 26A103B 3D printed diffuser bezel
* 26A104 3D printed button (may be printed in other materials than ABS)
* 26A105 3D printed PCB cover
* 2x M2x10mm pan head self-tapping screw for plastic (head diameter 4mm or less)
* 4x 8mm diameter adhesive-backed rubber bumper (3M SJ5370 or equivalent)
* 4x 6mm diameter x 3mm thick N52 neodynium magnet (optional since May 2026 - 3D printed clips now recommended for horizontal usage)

### optional
* 26A110B 3D printed tonecarrier compatibility plate
* 26A111 3D printed valoi 360 advancer compatibility plate (deprecated; for 360 advancer only)
* 26A112 3D printed valoi 360 holder compatibility plate (deprecated; for 360 film holders only)
* 26A113 3D printed valoi 360 combined compatibility plate (supports both 360 film holders and 360 advancer)

*Note: if printing ToneCarrier/Valoi compatibility parts, double-check that the dimensions of the STEP file match the accessory you are using it with. Dimensions of these third-party products may change without notice.*

## big scanlight

[assembly instructions](./big%20scanlight%20v1/assembly_instructions.md)

### big scanlight only
* assembled driver PCB
* assembled LED PCB
* front diffuser (4.5x5.5x0.118" ACRYLITE® Satinice WD008 DF light-diffusing acrylic, or standard white acrylic with <50% light transmittance)
* 25D101C 3D printed diffuser box housing
* 25D103A 3D printed diffuser bezel
* 25D104 3D printed backplate
* 25D105B 3D printed PCB cover
* 25D107 3D printed button (may be printed in other materials than ABS)
* 2x M2x10mm pan head self-tapping screw for plastic (head diameter 4mm or less)
* 4x M3x8mm pan head self-tapping screw for plastic (head diameter 6.5mm or less)
* 4x 12mm diameter, 4mm tall adhesive-backed rubber bumper

### optional
* 25D108 3D printed film carrier compatibility plate (**use variant B for film carriers made starting May 2026, variant A otherwise**)
* 25D110 3D printed tonecarrier compatibility plate
* 25D111 3D printed valoi 360 advancer compatibility plate
* 25D114B 3D printed lobster holder v2.1 compatibility plate
* 25D115 3D printed essential film holder compatibility plate

### valoi easy120 integration
* **replace** 25D103**A** with 25D103**B** 3D printed diffuser bezel (screw mount variant)
* 25D112 3D printed valoi easy120 baseplate
* 25D113 3D printed valoi easy120 mounting block
* 4x M3x20mm socket head cap screw
* 4x M3 heat-set insert (5mm diameter, 4-5mm length)

*Note: if printing ToneCarrier/Valoi compatibility parts, double-check that the dimensions of the STEP file match the accessory you are using it with. Dimensions of these third-party products may change without notice.*

## accessories

Current film carrier design files are in the [film carriers v1.1 folder](./film%20carriers%20v1.1/).

### 35mm film carrier

* 2x 25C012 3D printed 35mm film carrier half
* 25C011 3D printed 35mm mask
* 25C020 3D printed 35mm half frame mask (optional)
* 25C018A 3D printed 35mm film carrier hood
* 2x 26A114 3D printed 35mm film carrier clip
* 2x M2x10mm pan head self-tapping screw for plastic
* 4x 4mm diameter x 2mm thick N52 neodynium magnet (optional since May 2026 - 3D printed clips now recommended for horizontal usage)

### medium format film carrier

* 2x 25C013 3D printed medium format film carrier half
* 25C014 3D printed 6x8 mask (optional)
* 25C015 3D printed 6x7 mask (optional)
* 25C016 3D printed 6x6 mask (optional)
* 25C017 3D printed 6x4.5 mask (optional)
* 2x 26A115 3D printed medium format film carrier clip
* 2x M2x10mm pan head self-tapping screw for plastic (head diameter 4mm or less)
* 4x 4mm diameter x 2mm thick N52 neodynium magnet (optional since May 2026 - 3D printed clips now recommended for horizontal usage)

### scanlight v2/v3/v4 horizontal mount

*camera_height* is the vertical distance in millimeters between the bottom flat surface of your camera's Arca-Swiss quick release plate and the central axis of the lens.

* 20x20mm T-slot aluminum extrusion at least 350mm long, depending on close focusing ability of your lens
* 25C032 3D printed diffuser mount
* 25C034 3D printed camera clamp slider
* 25C035 3D printed camera clamp cleat
* 25C036 3D printed camera clamp cam
* 25C037 3D printed M3x1mm spacer (quantity = 4 * (*camera_height* - 37))
* 4x M3 socket head cap screw (length = 12 + (*camera_height* - 37) +/- 2 mm)
* M3 washers (as needed)
* 4x M3 heat-set insert (5mm diameter, 4-5mm length)
* 2x M3x8mm socket head cap screw
* 2x M3 T-slot nut for 2020 aluminum extrusion
* 1x M5x8mm button head cap screw
* 1x M5x12mm socket head cap screw
* 2x M5 T-slot nut for 2020 aluminum extrusion

## old versions (for reference only, do not build)

### scanlight v2/v3 only
* assembled PCB
* front diffuser (4x3x0.118" ACRYLITE® Satinice WD008 DF light-diffusing acrylic, or standard white acrylic with <50% light transmittance)
* 3D printed PCB baseplate
* 3D printed diffuser box housing
* 3D printed diffuser bezel
* 4x 6mm diameter x 3mm thick N52 neodynium magnet (if using magnetically attached film carriers)
* 8x M2x6mm pan head self-tapping screw for plastic (head diameter 4mm or less)
* 4x 8mm diameter adhesive-backed rubber bumper (3M SJ5370 or equivalent)

Note: the reflector box housing and diffuser bezel are available in two variants, screw-together and snap-fit. The snap-fit versions are designed specifically to print in ABS on a very well-tuned printer with a heated chamber; good results are not guaranteed otherwise.

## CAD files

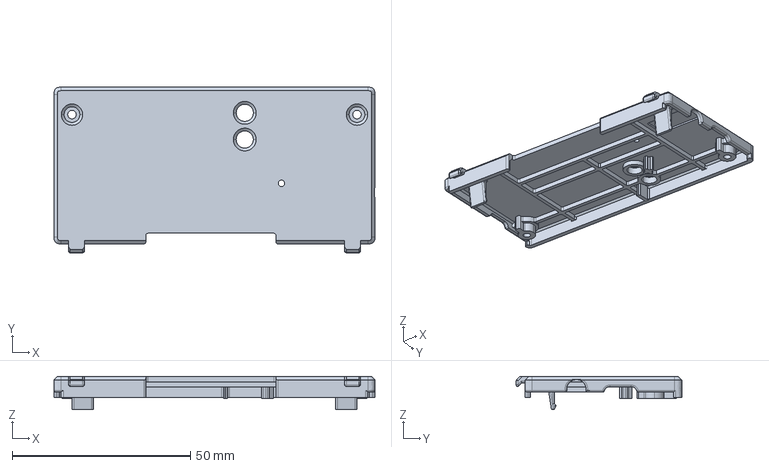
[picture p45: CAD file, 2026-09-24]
3d/big scanlight v1/25d105b pcb cover.step
90.1 x 46.5 x 9.30 mm

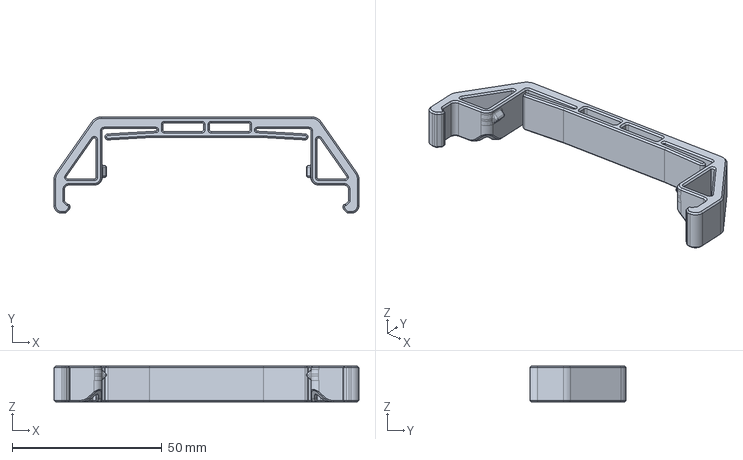
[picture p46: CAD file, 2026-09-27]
3d/film carriers v1.1/26a115 film carrier clip 120.step
101.8 x 32.2 x 12.0 mm

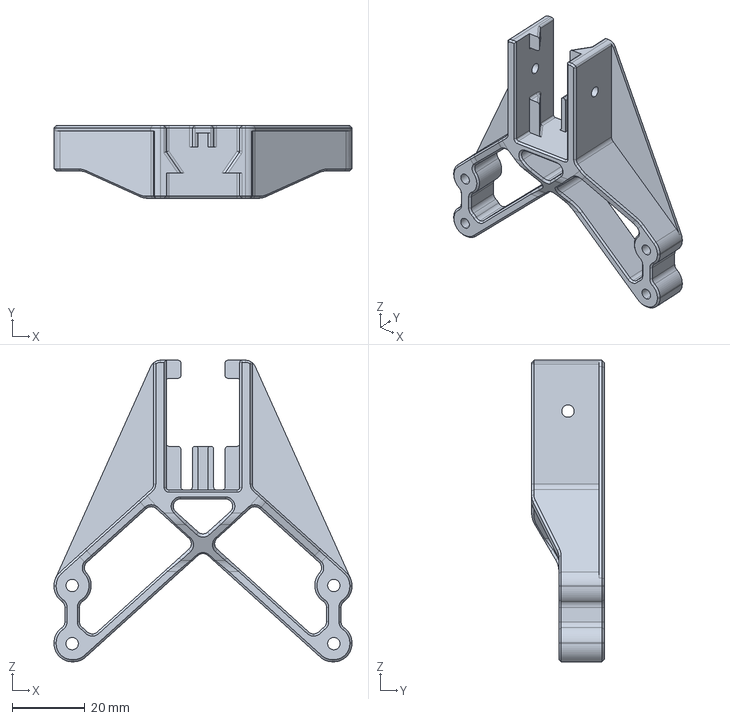
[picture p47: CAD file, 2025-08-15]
3d/horizontal/25c032 diffuser mount.step
82.0 x 20.0 x 83.0 mm

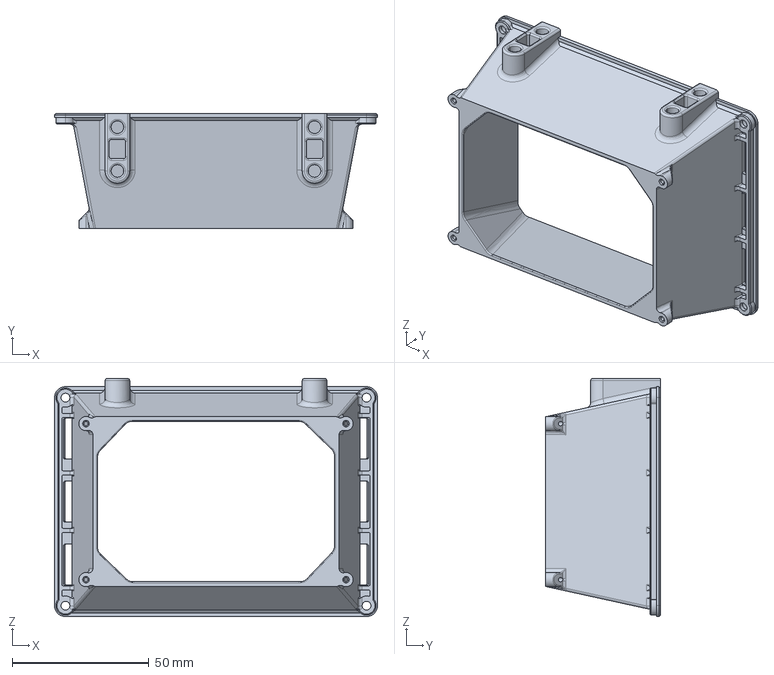
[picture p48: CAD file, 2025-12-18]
3d/light source v3/25c-p001f2 reflector box housing snapfit.step
118.0 x 42.0 x 87.0 mm

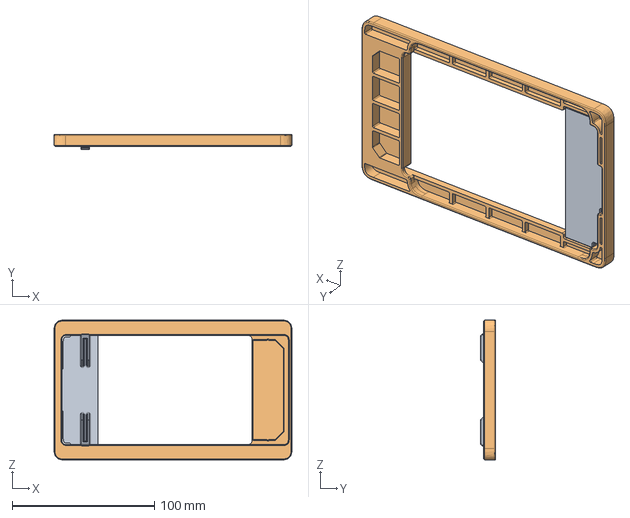
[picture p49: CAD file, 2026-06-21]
3d/scanlight v4/26a112 valoi 360 mask compatibility plate.step
167.3 x 10.6 x 98.4 mm

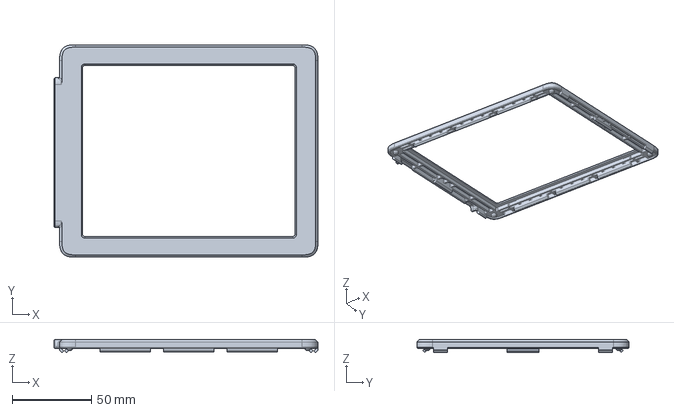
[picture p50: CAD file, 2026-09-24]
3d/big scanlight v1/25d103a diffuser bezel.step
166.5 x 134.0 x 8.00 mm

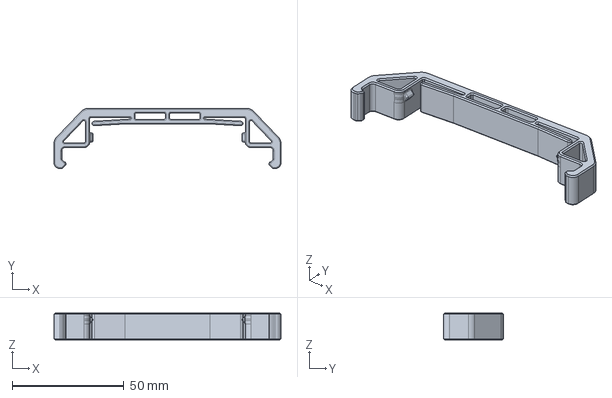
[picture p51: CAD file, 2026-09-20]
3d/film carriers v1.1/26a114 film carrier clip 35.step
101.8 x 26.9 x 12.0 mm

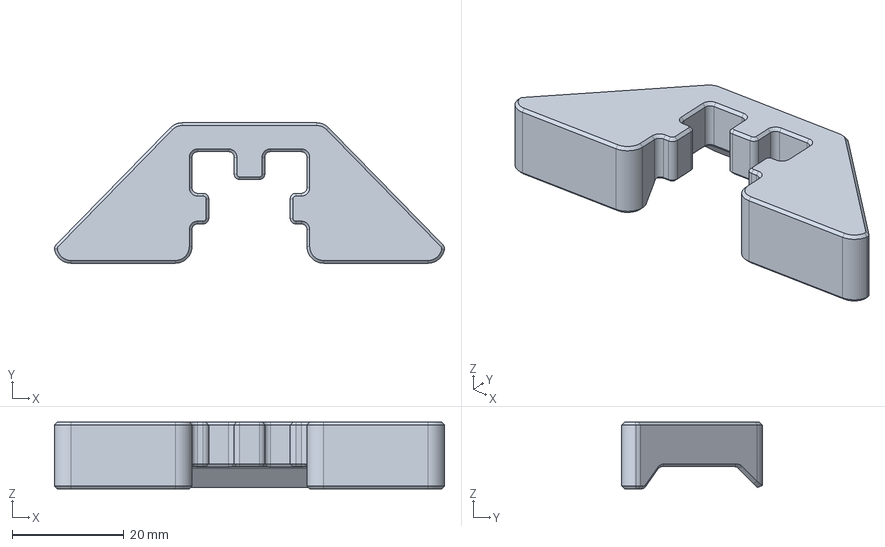
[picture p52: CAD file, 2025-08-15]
3d/horizontal/25c034 camera clamp slider.step
69.9 x 25.2 x 12.0 mm

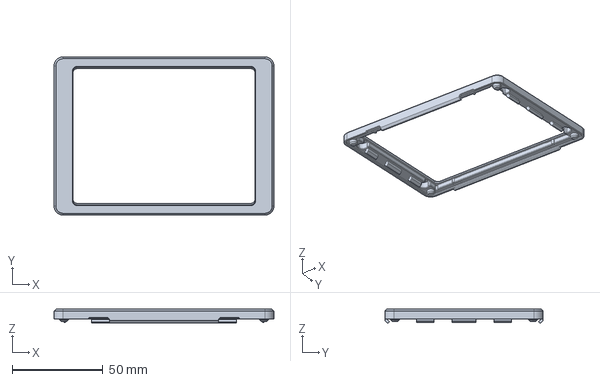
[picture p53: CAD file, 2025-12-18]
3d/light source v3/25c-p003b2 diffuser bezel snapfit.step
121.0 x 87.0 x 7.50 mm

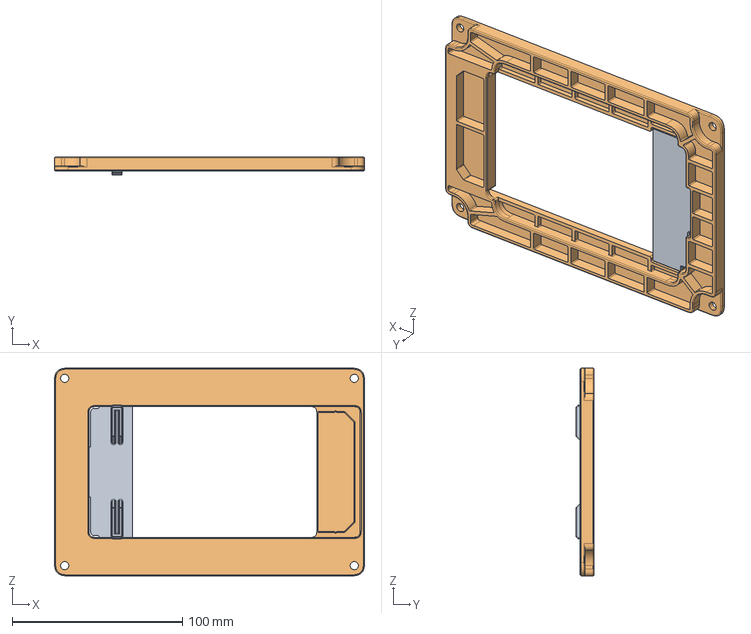
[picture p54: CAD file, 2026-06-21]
3d/scanlight v4/26a113 valoi 360 combined compatibility plate.step
182.0 x 10.6 x 122.0 mm

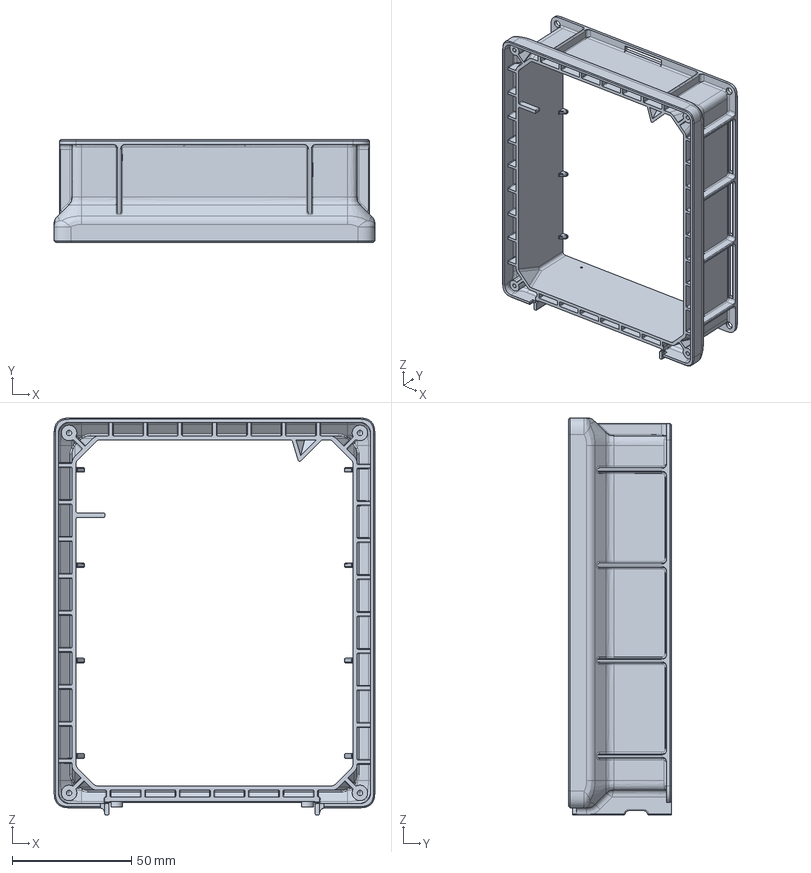
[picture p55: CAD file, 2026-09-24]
3d/big scanlight v1/25d101c diffuser box.step
134.5 x 43.0 x 166.5 mm

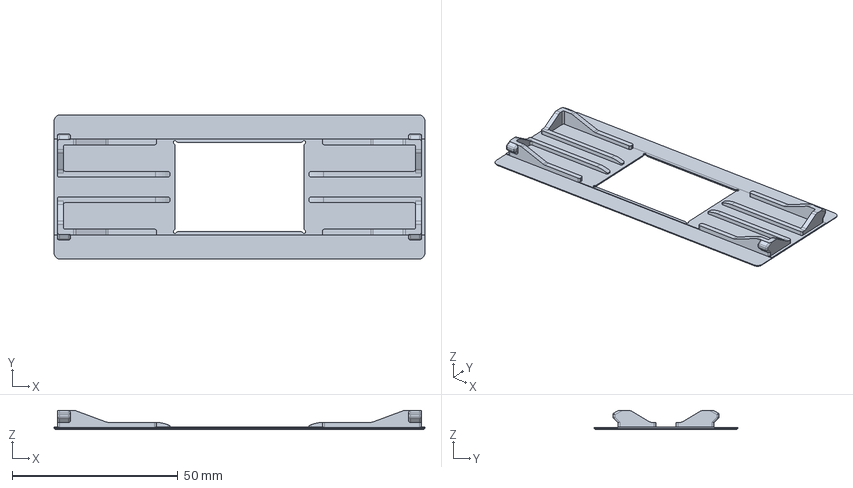
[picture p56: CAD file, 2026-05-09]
3d/film carriers v1.1/25c011 35mm mask.step
112.0 x 43.6 x 5.80 mm

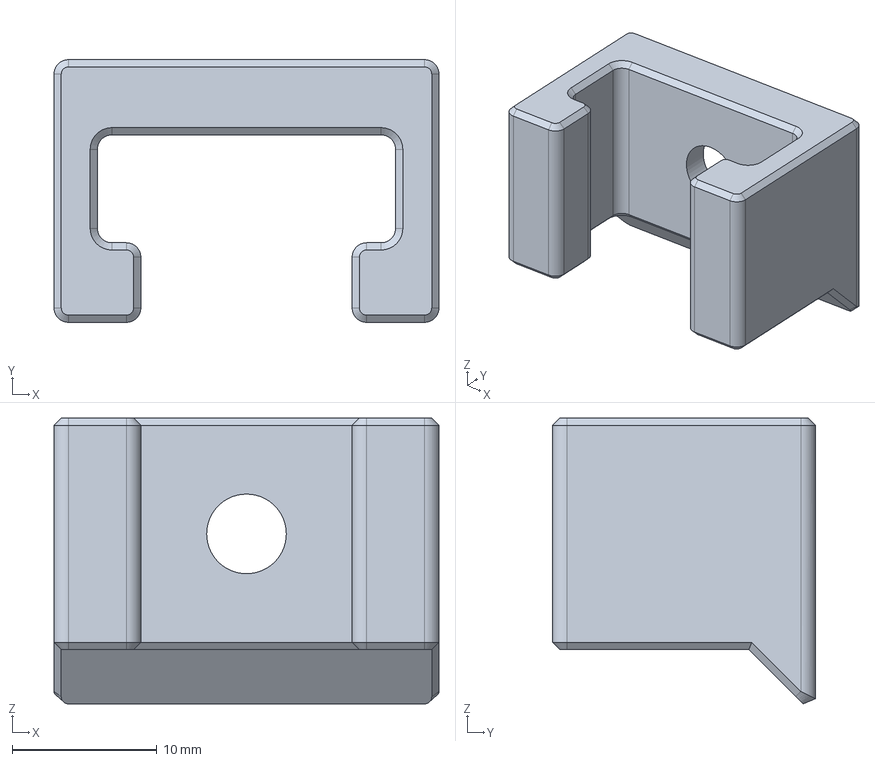
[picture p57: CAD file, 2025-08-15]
3d/horizontal/25c035 camera clamp cleat.step
26.6 x 18.1 x 19.7 mm

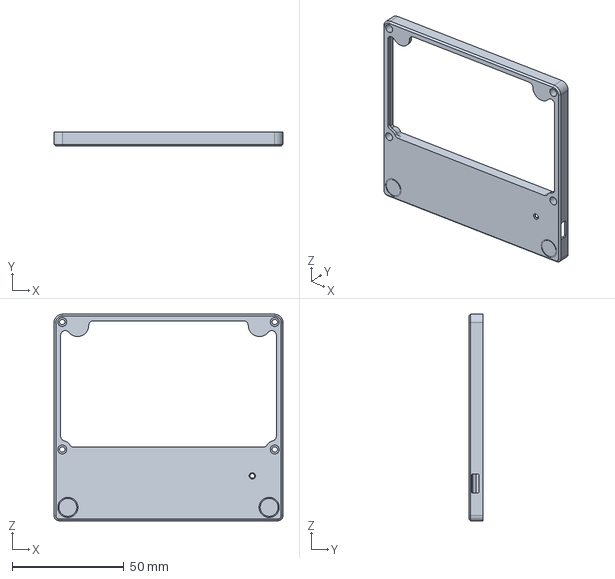
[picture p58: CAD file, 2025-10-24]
3d/light source v3/25c-p004b pcb baseplate v3.step
102.4 x 6.30 x 92.4 mm

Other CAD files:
3d/scanlight v4/26a110b tonecarrier compatibility plate.step
3d/big scanlight v1/25d107 button.step
3d/film carriers v1.1/25c014 120 68 mask.step
3d/horizontal/25c036 camera clamp cam.step
3d/big scanlight v1/25d103b diffuser bezel screw mount.step
3d/big scanlight v1/25d104 backplate.step
3d/big scanlight v1/25d108a film carrier compatibility plate.step
3d/big scanlight v1/25d108b film carrier compatibility plate.step
3d/big scanlight v1/25d110 tonecarrier compatibility plate.step
3d/big scanlight v1/25d111 valoi 360 advancer compatibility plate.step
3d/big scanlight v1/25d112 valoi easy120 baseplate.step
3d/big scanlight v1/25d113 valoi easy120 mounting block.step
3d/big scanlight v1/25d114b lobster compatibility plate.step
3d/big scanlight v1/25d115 efh compatibility plate.step
3d/film carriers v1.1/25c012 35mm film carrier half.step
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

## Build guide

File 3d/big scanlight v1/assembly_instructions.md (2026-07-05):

# big scanlight assembly instructions

## 1

Remove the protective film from the acrylic sheet and insert it into the diffuser bezel.

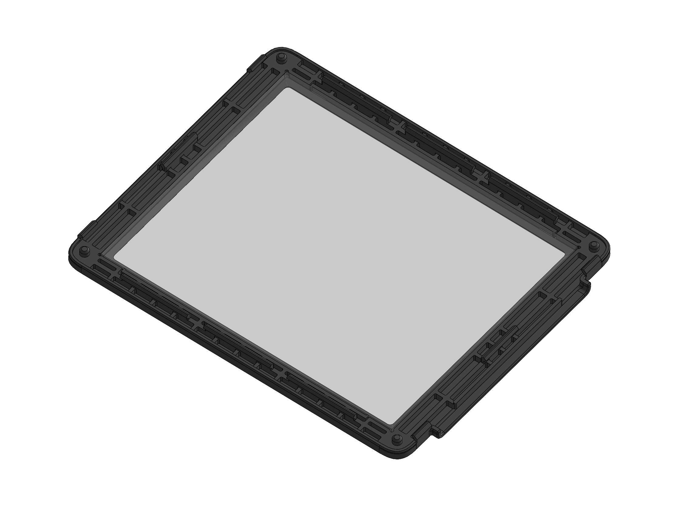
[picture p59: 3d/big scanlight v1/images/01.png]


## 2

Engage the rim of the diffuser box (on the side with the two protruding flanges) with the hooks on the matching side of the diffuser bezel as shown. Fit the alignment posts on the bezel into the matching holes on the rim of the diffuser box. The angle between the parts is exaggerated in the images; they will want to sit flat with each other in real life.

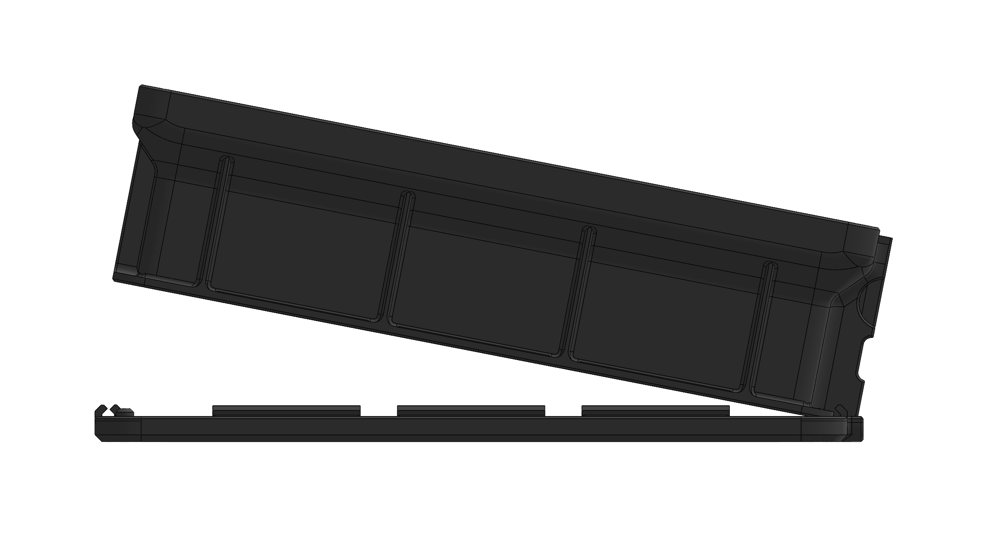
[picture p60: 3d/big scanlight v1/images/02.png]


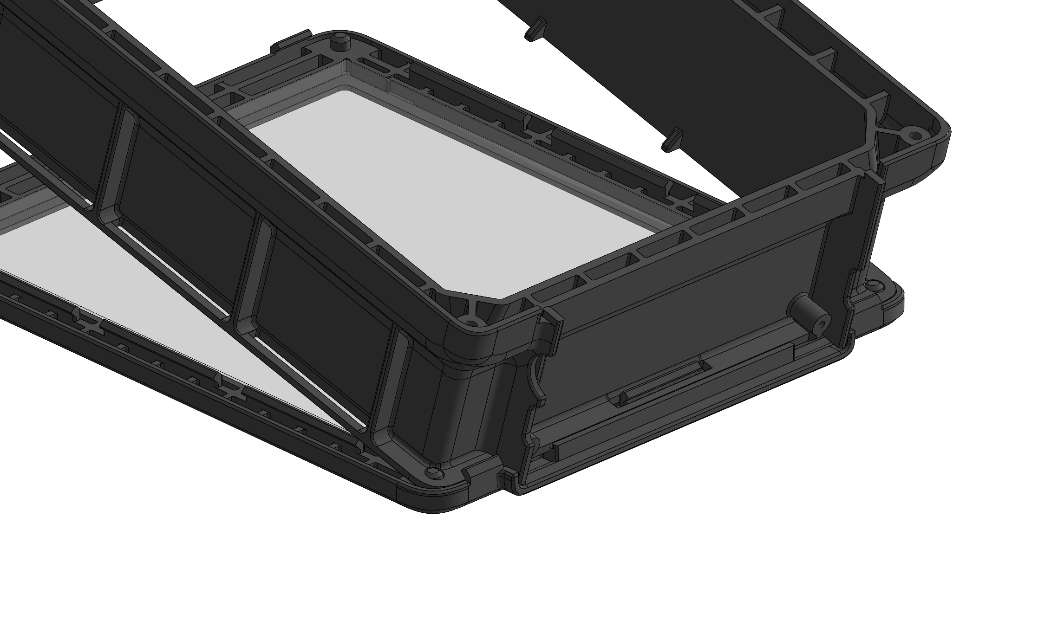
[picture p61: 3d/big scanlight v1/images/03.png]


Press the diffuser box onto the bezel to fasten it in place, squeezing the parts together in the locations and order shown.

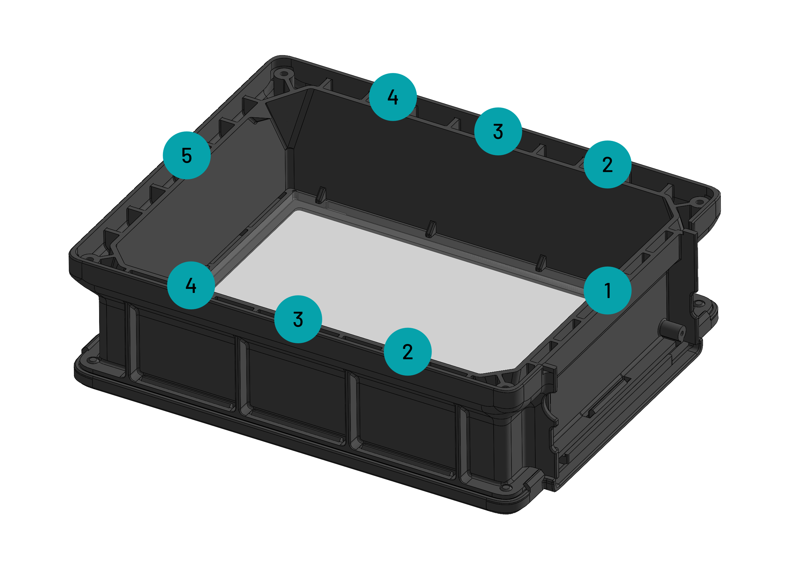
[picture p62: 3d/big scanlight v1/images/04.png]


*The bezel snap-fit is intended to be permanent. It is possible to disassemble by inserting a flexible steel pry tool into the gap between the bezel and diffuser box rim, but the risk of damaging the bezel is relatively high.*

## 3

Insert the buttons into the rear side of the PCB cover. Snap the driver PCB into the cover.

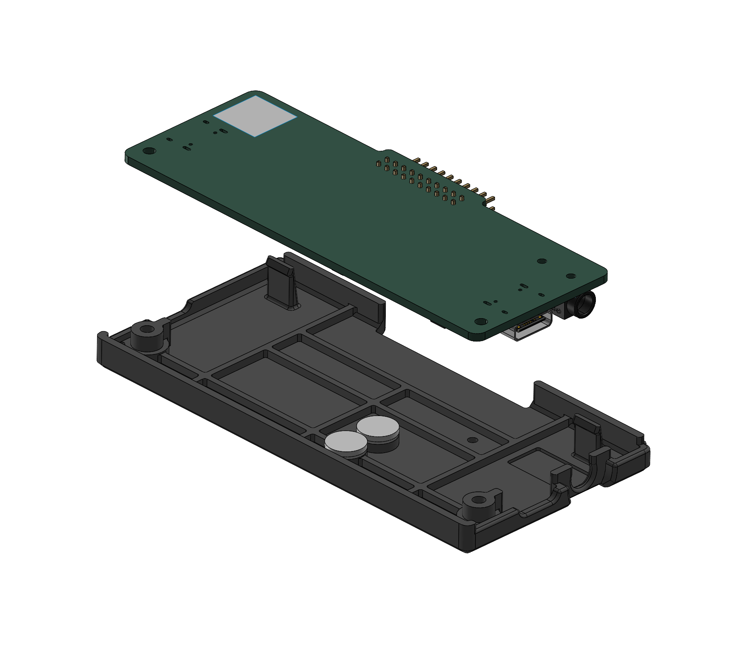
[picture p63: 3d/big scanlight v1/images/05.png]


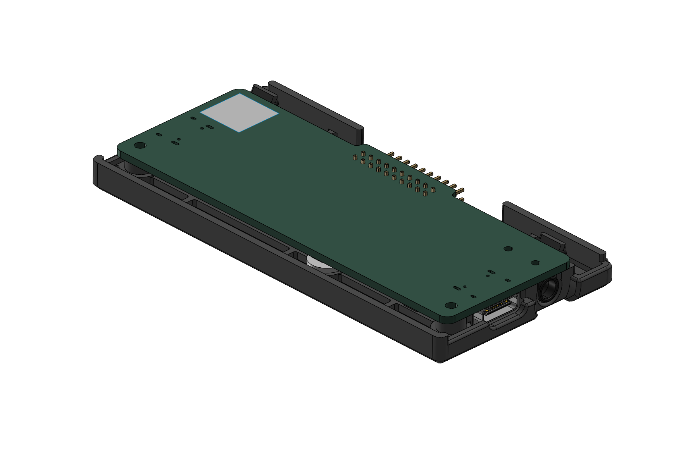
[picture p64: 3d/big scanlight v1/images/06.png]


## 4

Insert the PCB assembly into the recess on the side of the diffuser box, aligning the mounting holes on the PCB with the mounting bosses on the diffuser box. Secure the PCB and cover in place with two M2x10 self-tapping screws using a T6 Torx screwdriver.

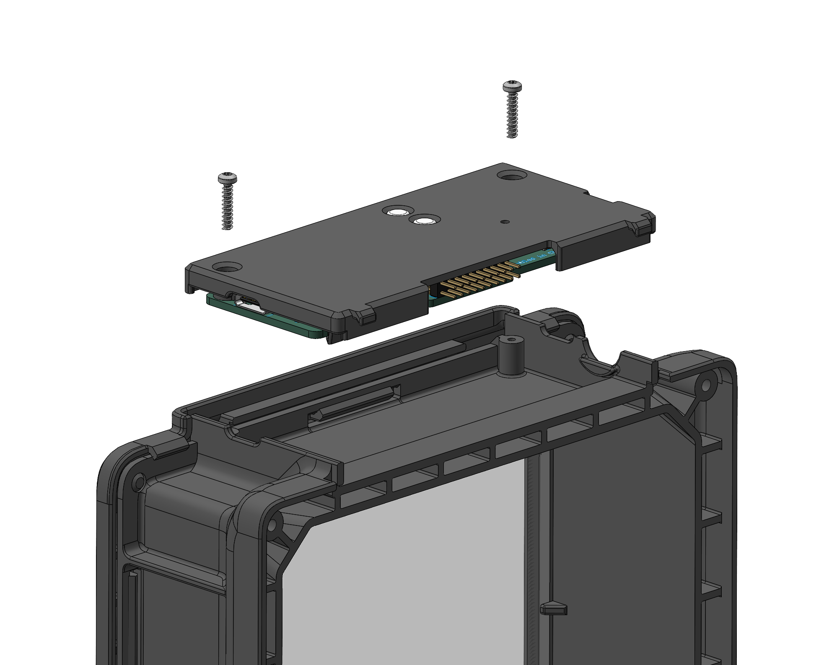
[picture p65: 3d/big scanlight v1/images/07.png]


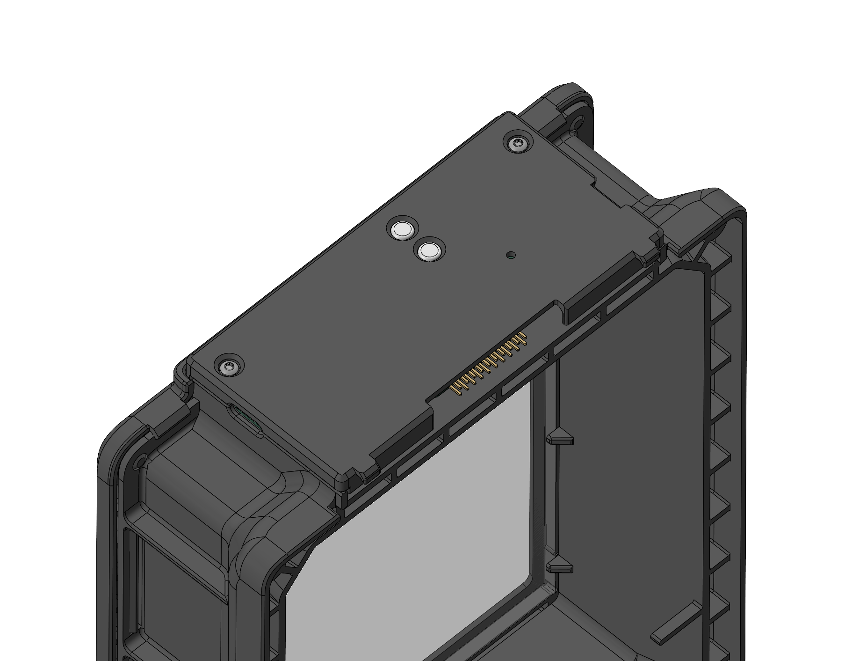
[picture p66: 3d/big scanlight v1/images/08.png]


## 5

Use compressed air or a handheld blower tool to remove any dust or debris from the inside of the diffuser box. Place the LED PCB into the opening on the rear of the diffuser box, aligning the black connector on the LED PCB with the pins on the driver PCB. Press down on the back of the LED PCB around the connector area to connect the PCBs together.

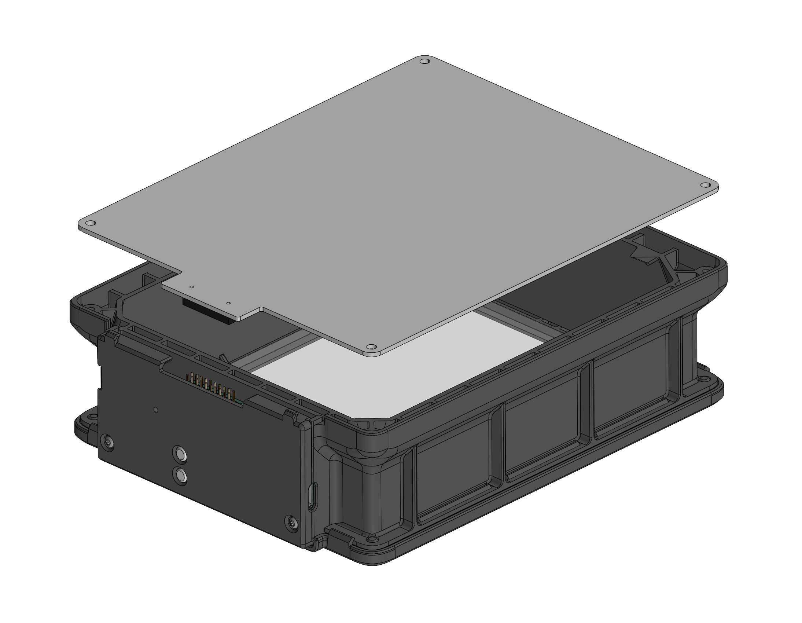
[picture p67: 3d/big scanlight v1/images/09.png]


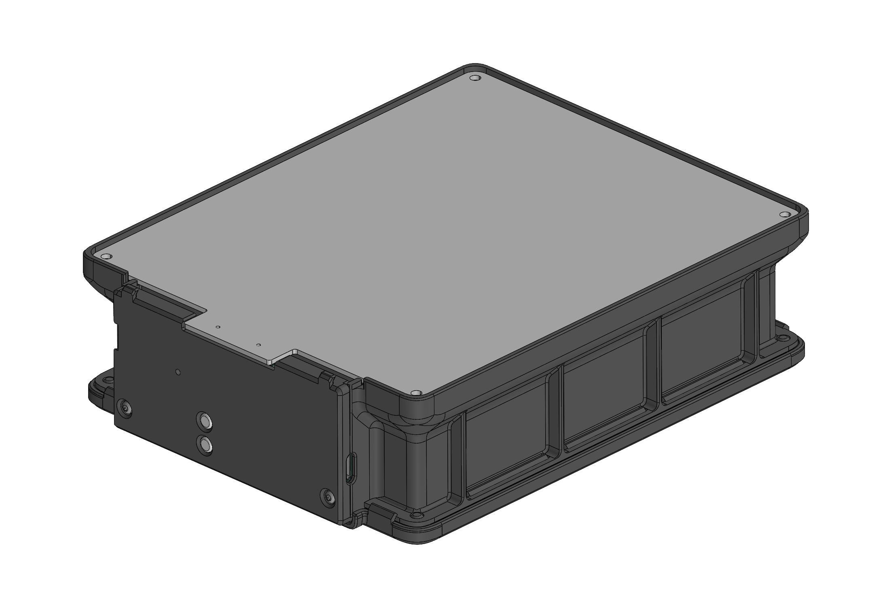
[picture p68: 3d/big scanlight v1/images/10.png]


## 6

Place the backplate over the PCB so that the protruding flange covers the exposed edge of the LED PCB, lining up the two rectangular holes at the edge of the backplate with the tabs protruding from the driver PCB cover. Press on the backplate around these holes to snap the backplate onto the PCB cover. Install the four M3x8 self-tapping screws that secure the LED PCB and backplate to the diffuser box using a T9 Torx screwdriver.

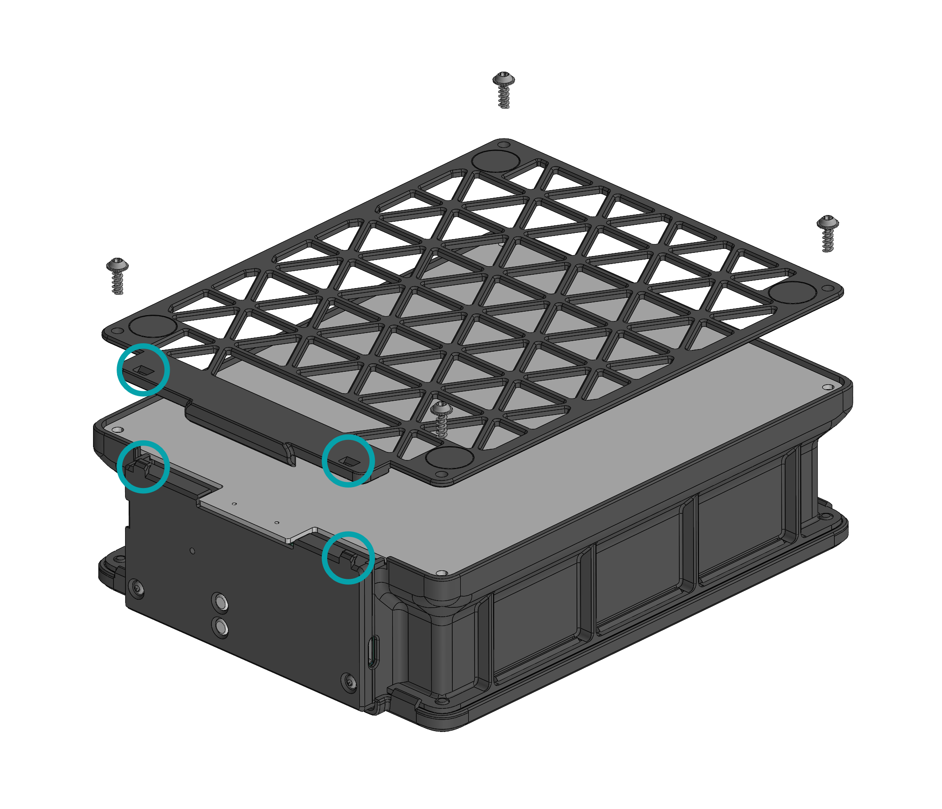
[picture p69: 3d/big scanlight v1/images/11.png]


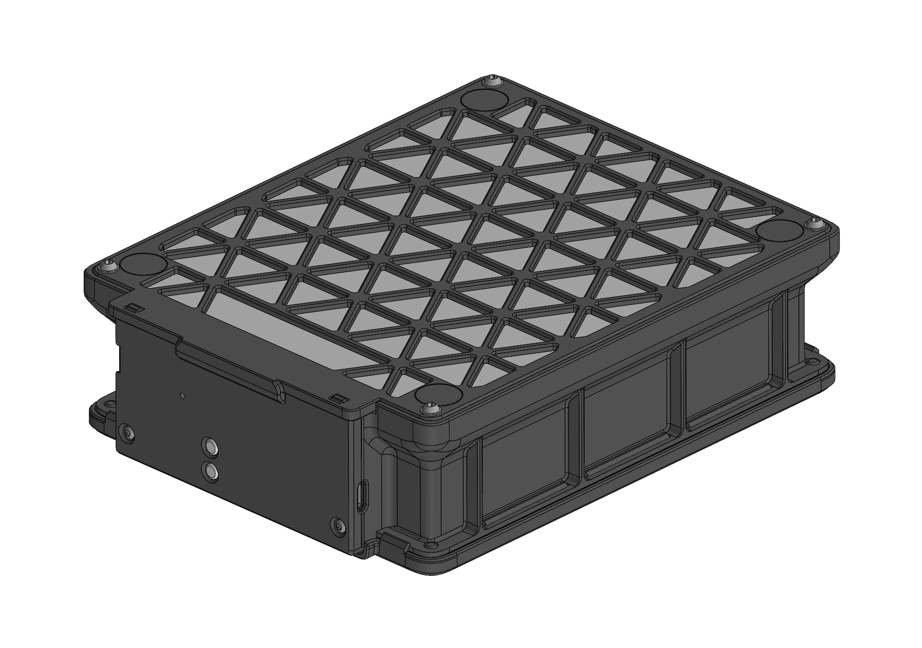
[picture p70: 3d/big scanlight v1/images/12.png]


## 7

Clean the circular areas on the backplate where the rubber feet will attach with a paper towel and isopropanol. Stick on the rubber feet.

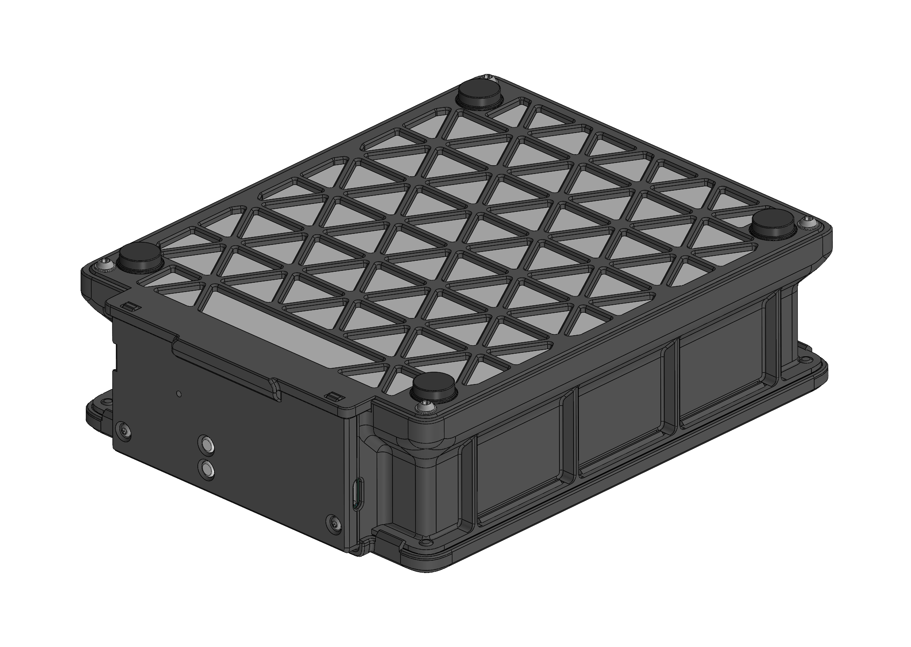
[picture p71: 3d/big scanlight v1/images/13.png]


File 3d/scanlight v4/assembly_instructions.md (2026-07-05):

# scanlight v4 assembly instructions

## 1

Remove the protective film from the acrylic sheet and insert it into the diffuser bezel.

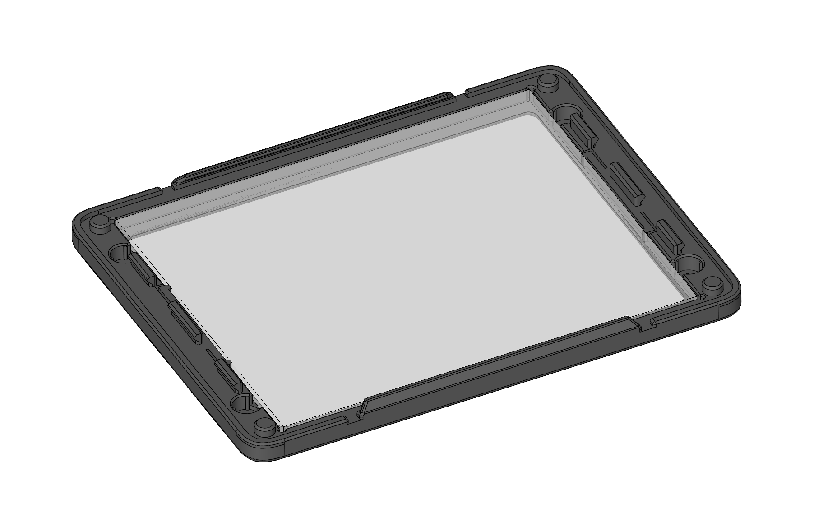
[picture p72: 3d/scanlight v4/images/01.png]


If desired, press four 6x3mm neodynium magnets into the circular holes on the bezel. If you already have film carriers with magnets inserted, ensure that the magnet polarities match and the film carrier attaches firmly to the bezel.

## 2

Engage the rim of the diffuser box housing with the hooks on the diffuser bezel. Fit the alignment posts on the bezel into the matching holes on the rim of the diffuser box, fit the edges of the diffuser box under the two long flanges on either side of the bezel, and press the diffuser box onto the bezel to fasten it in place, one end at a time. The angle between the parts is exaggerated in the images; they will want to sit flat with each other in real life.

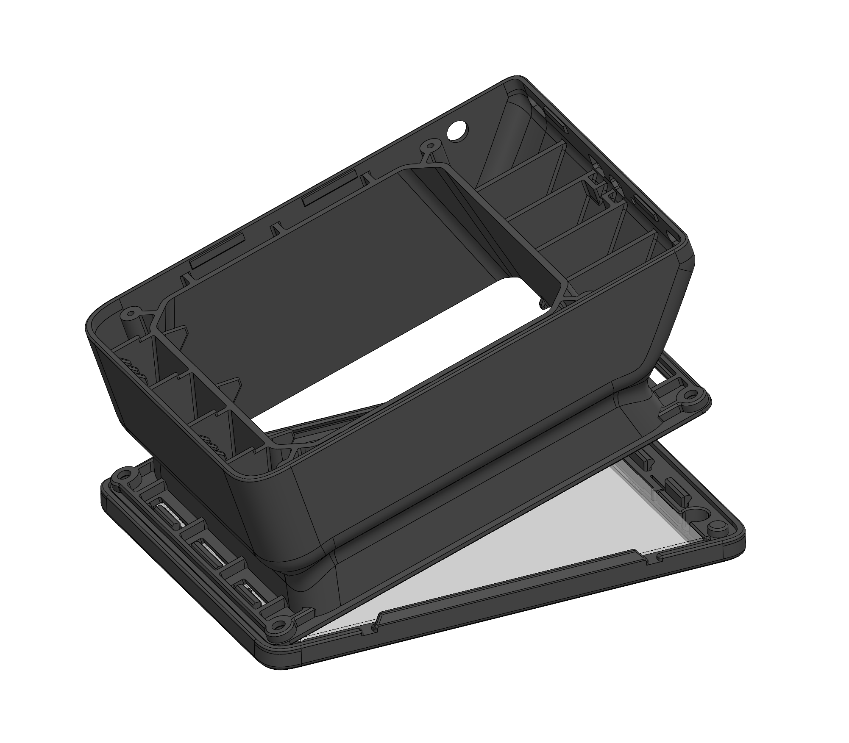
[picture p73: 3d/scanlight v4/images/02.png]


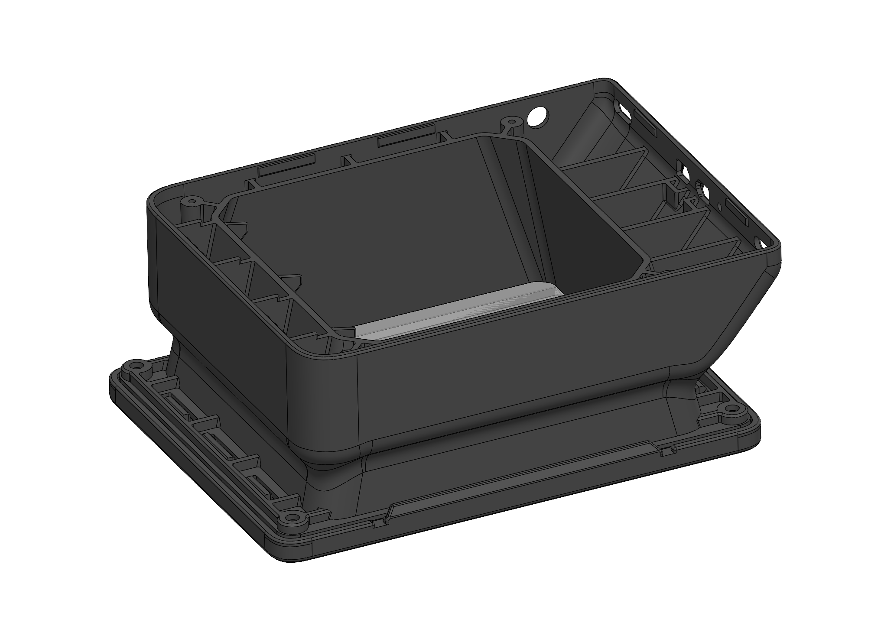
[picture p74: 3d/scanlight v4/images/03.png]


*The bezel snap-fit is intended to be permanent. It is possible to disassemble by inserting a flexible steel pry tool into the gap between the bezel and diffuser box rim, but the risk of damaging the bezel is relatively high.*

## 3

Use compressed air or a handheld blower tool to remove any dust or debris from the inside of the diffuser box. Insert the button piece into the matching holes on the diffuser box housing.

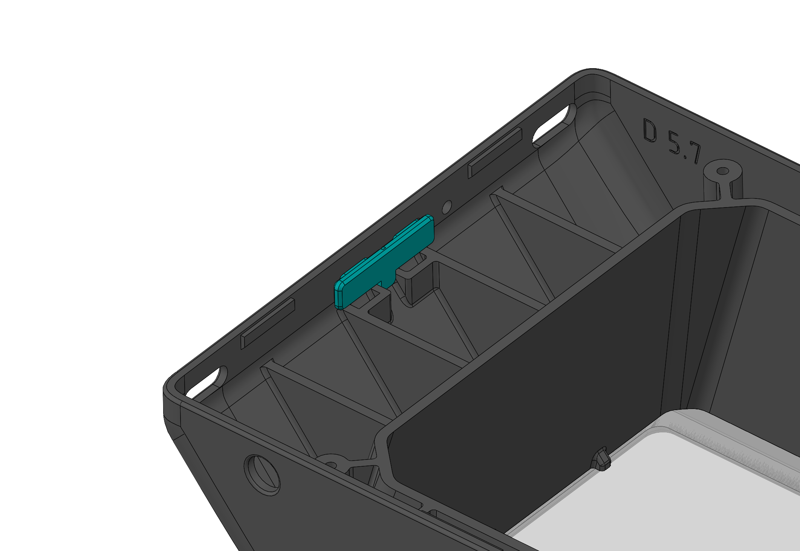
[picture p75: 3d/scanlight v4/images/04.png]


Align the 3.5mm jack on the PCB with the matching hole on the housing, and rotate the PCB into the housing.

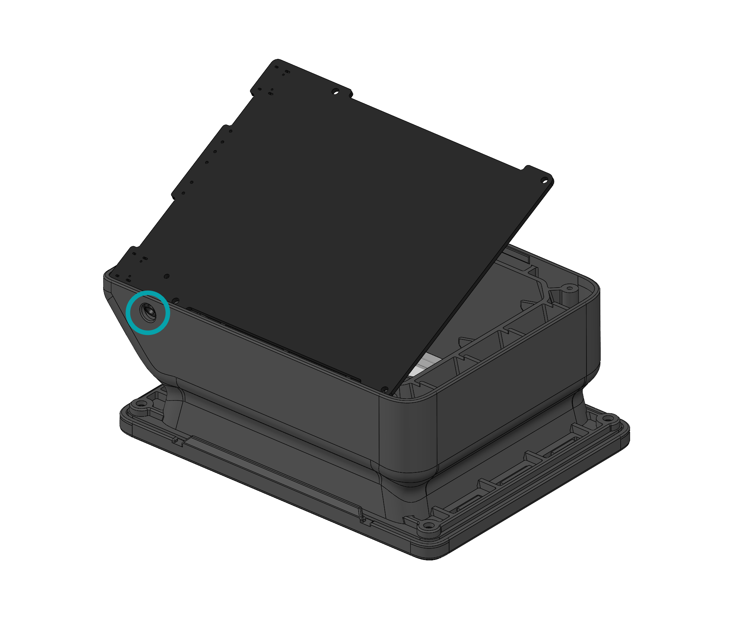
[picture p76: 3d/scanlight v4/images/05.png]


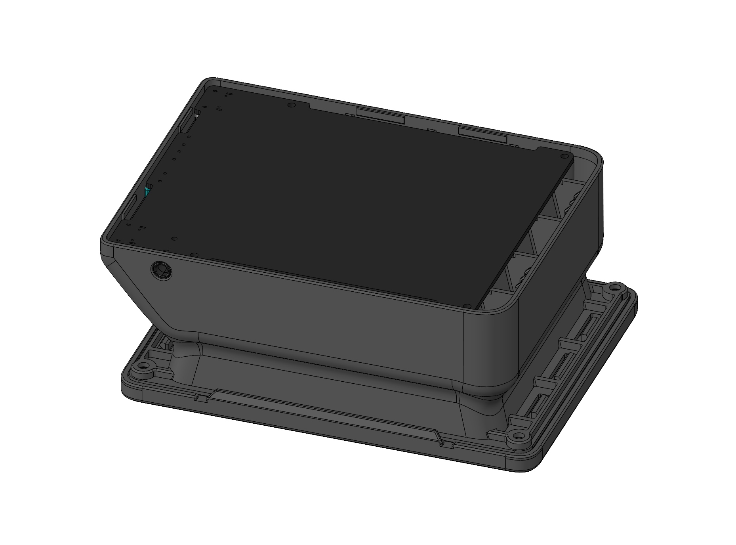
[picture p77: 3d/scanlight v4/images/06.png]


## 4

Align the two tall locating bosses on the PCB cover with the matching tabs on the inside of the housing (shown in cutaway view). Snap the PCB cover into the housing by applying pressure in the locations and order shown, pushing down into the housing and horizontally in the direction of the arrow.

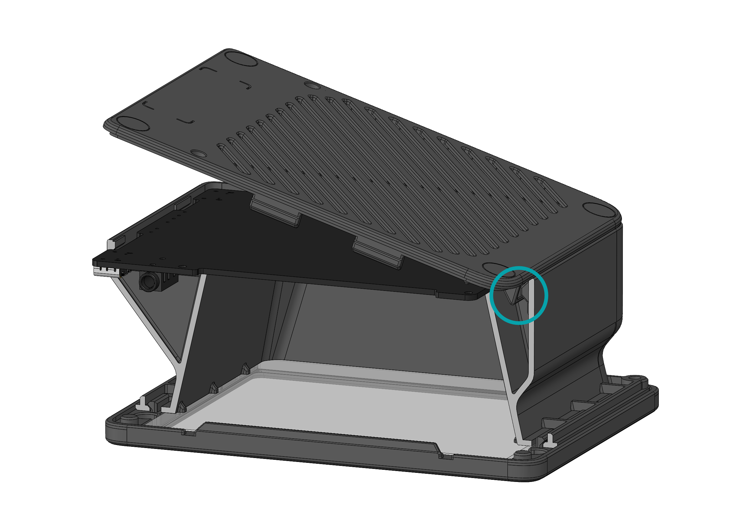
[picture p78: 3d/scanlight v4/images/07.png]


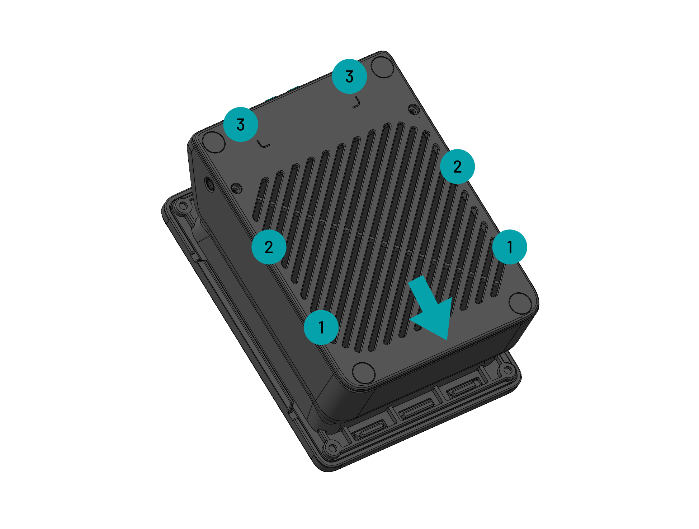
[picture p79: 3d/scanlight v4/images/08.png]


*To disassemble, use a thin plastic or metal pry tool to widen the gap between the PCB cover and housing at location 3, then insert the pry tool between the PCB and the cover and gently pry the cover out completely.*

## 5

Install the two M2x10 self-tapping screws that secure the PCB cover and PCB to the diffuser box housing using a T6 Torx screwdriver.

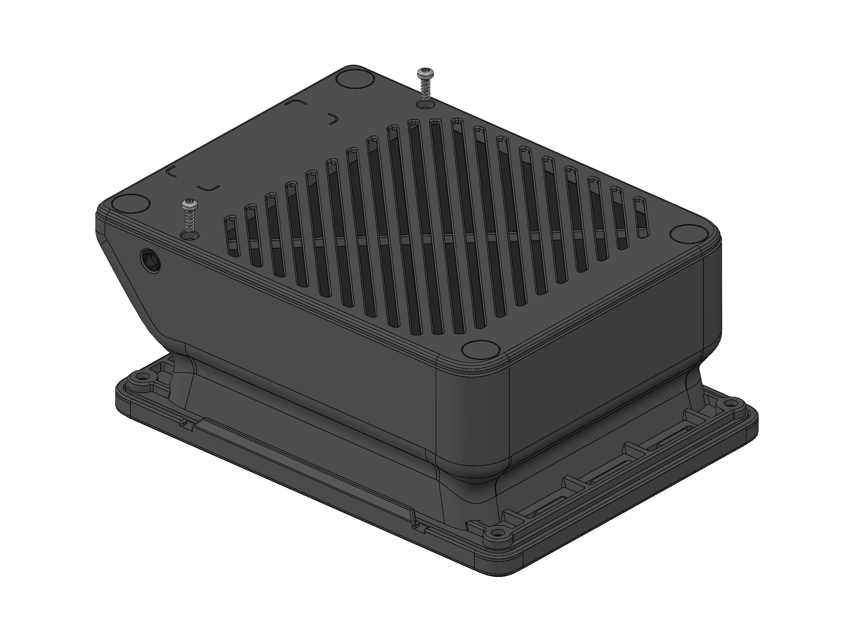
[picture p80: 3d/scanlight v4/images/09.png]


## 6

Clean the marked areas on the PCB cover where the rubber feet and label will attach with a paper towel and isopropanol. Stick on the rubber feet and label.

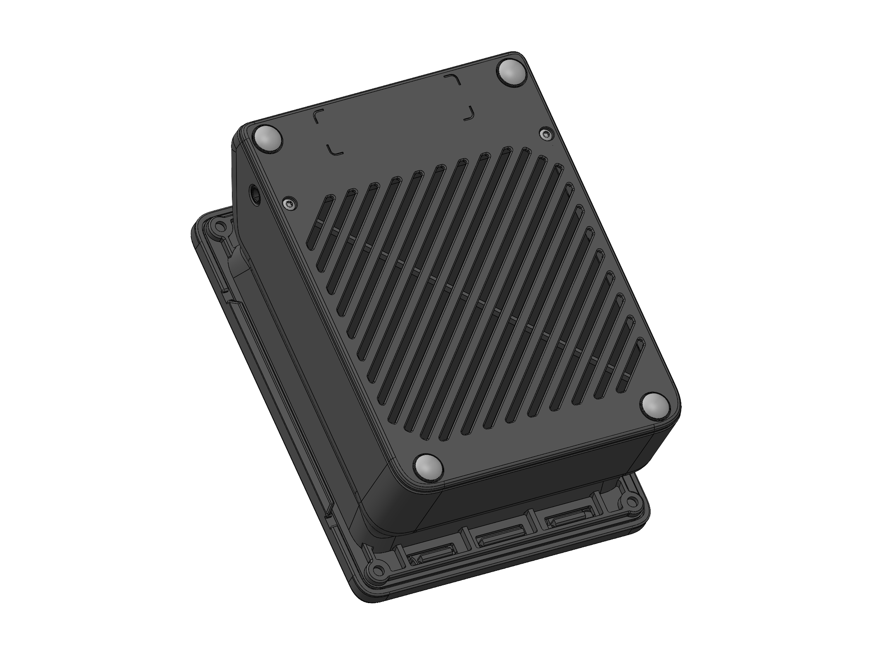
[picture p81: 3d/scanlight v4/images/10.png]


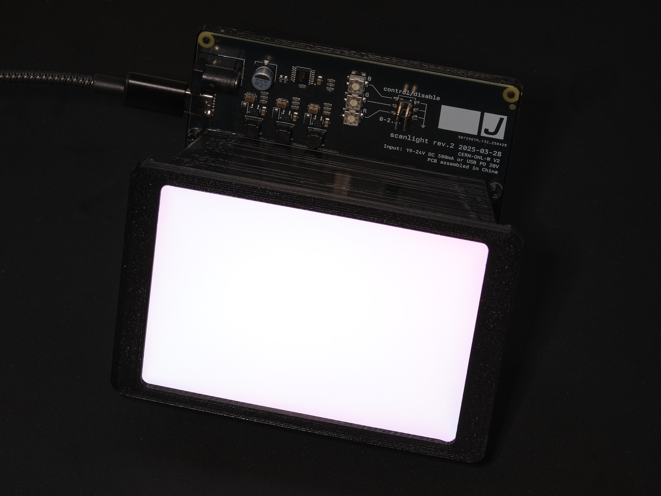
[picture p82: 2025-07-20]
images/light_assembly_v2.jpg

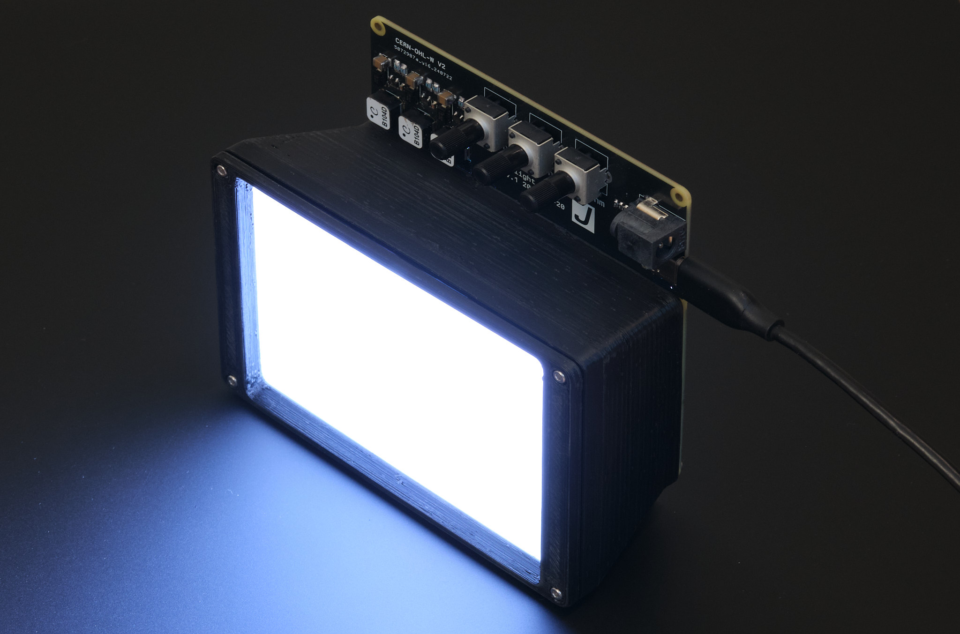
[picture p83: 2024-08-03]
images/light_assembly_top.jpg

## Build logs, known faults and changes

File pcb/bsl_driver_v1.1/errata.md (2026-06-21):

- focus terminal on camera control jack should be utilized for Nikon Z5/Z6

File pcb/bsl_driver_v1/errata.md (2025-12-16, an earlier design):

- TH net on J101 pin 9 should be renamed TH+

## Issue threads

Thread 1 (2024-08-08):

software

jcupitt, 2024-08-08:
Hi @jackw01, I came across your interesting repo on reddit.

I was wondering what software you were using for processing these scans? I made a tool you might find useful:

https://github.com/libvips/nip2

It's a bit like a spreadsheet, but for image processing, so cells can contain whole images. You can enter formula that describe the processing you want (eg. `1 - 1 / log A1` or whatever). Whenever you change anything, perhaps replacing an image in a cell or editing a formula, everything updates. It's built into most linuxes, or there are windows binaries in the "releases" tab.

I tried (very quickly!) processing your comparison shot:

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

That does the following:

- extract the shot from your nice lightbox
- split the colour bands to RGB, then for each band
- estimate the minimum density (max pixel value) by taking the average pixel value of an area of film near the centre edge
- max density by doing a gaussian blur and taking the min (to avoid camera noise)
- rescaling the grey values to 10 .. 240 (ie. avoid the extreme edges)
- recombine the corrected greyscales to RGB
- invert in density space (ie. `exp (1 / log X)`)
- adjust brightness

It makes this output, which looks OK-ish:

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

It's just a quick demo, it needs some obvious improvements:

- in your blue band, the film is brighter than the sprocket holes, I'm not sure why (hence the cyan squares)
- flatfield correction of the lightbox (your box is quite a bit brighter in the centre)
- you could estimate the actual transfer function for your film + camera + lightbox combo from a shot of a greyscale, like a macbeth chart
- once you've found the transfer function, you could use a macbeth shot to compute the optimal 3x3 colour correction matrix, which would be great fun to try

jcupitt, 2024-08-08:
... that workspace, if you're interested:

http://www.rollthepotato.net/~john/lightbox.ws

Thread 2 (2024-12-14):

Markings on PCB and cathodes

sydney-d, 2024-12-14:
Hello,

Can you confirm that these markings always refer to the cathodes for all LEDs ?
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

I have trouble making LEDs work.
By using the continuity tester on my multimeter I have been able to materialize these tracks :
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

For example I'm able to light an LED like this (3v to the anode, gnd to the cathode, cathode to the marking)
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

But the only way to turn on two consecutive LEDs is like this :
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

Which seems to indicate that for the LEDs to work the (conventional) current have to flow from D17 to D16, the opposite of how the PCB seems to have been designed ?

Should I ignore the markings ? Only for the red LEDs ?

Thank you for your help, I've been pulling my hair and wasting components on this one for way too long :D

sydney-d, 2024-12-15:
I Also notice a difference in the markings between the gerber files, and the kicad file [here](https://github.com/jackw01/scanlight/blob/main/images/pcb_cad.png)

Gerber file :
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

Kicad file from readme:
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

Notice the red arrows showing different markings

Is the gerber files up to date ?

Best

jackw01, 2025-01-01:
The gerber file should be the most up-to-date, but the correct mounting depends on which LEDs you are using, since color 2835 LEDs do not have standardized polarization (some have the anode on the large pad and some have the anode on the small pad). What LED part numbers are you using?

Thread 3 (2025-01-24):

Infrared Light Source

spaceChRiS, 2025-01-24:
I was pondering about such a project for a long time already, and now I found your repository which goes 80 % the direction I wanted to go. I definitely need to build such a light source. However, what bothers me, as I have a lot of scratched and dirty negatives (and positives), is if and how one could add an infrared light source for detection of these scratches and dust.

Some thoughts on infrared, maybe this is interesting or somebody reading this might even have some answers …

* Which wavelength would be suitable for scratch detection? I was not able to find what wavelength the fuji or noritsu scanners are using. If this information is not available, that's maybe something to test with different LEDs.
  * Infrared focus: If the wavelength is too far off of the visible spectrum, the result might be too blurry, but a little bit of blur might be acceptable for the IR channel.
* Infrared diffuser: Will the material combination you chose also work for infrared?
* Infrared power: As most cameras have a filter for infrared light, it may be useful to have enough power for reaching enough SNR despite having the IR cut filter on the sensor. Another option would be IR conversion of the camera.

spaceChRiS, 2025-01-26:
For transparency: I've also asked this question partially on pixls.us: https://discuss.pixls.us/t/wavelength-of-infrared-channel-for-scratch-dust-detection/47941.

raphaelb74, 2025-04-26:
@spaceChRiS I completely agree with your approach. I'm currently in the process of rebuilding my setup as well, using a Sony A7R III that will be converted to monochrome with the IR filter removed. I'm quite confident it would be possible to develop something that replicates the functionality of the old "ICE" algorithm.

@jackw01 would you think it'll be possible to add space for IR LED ? Also do you plan on making a larger PCB layout for 120 film ?

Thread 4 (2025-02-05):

Why these specific LEDs? Why isn't the deep red one from Cree also?

RedAnon, 2025-02-05:
Hi,
any particular reason you've chosen these specific LEDs? Especially the deep red one? Why is it different manufacturer? Why not the JE2835AHR-N-0001A0000-N0000001?

jackw01, 2025-02-08:
Those were out of stock when I used it. There's no reason why any other 2835 deep red LED with <3V forward voltage wouldn't work, but make sure to check the pinout.

Closed 2025-02-09.

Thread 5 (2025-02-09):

Where to order/have the pcb built

spoutn1k, 2025-02-09:
Hey, thank you for making this available !

I am a total noob when it comes to electronics but would love to have this made. I was comparing PCB manufacturers and may need some advice on where to get the PCB from; when uploading the files on the german website [aisler](https://aisler.net) they gave me a list of errors:

- Large surfaces and fillings are not permitted. Please change your layout and upload your project again.
- The spacing between copper and the NPTHs listed below is too small, resulting in a risk of unintentional through-hole plating. You can highlight the affected NPTHs by clicking on them. As NPTHs are covered by a film during the plating of PTHs, sufficient spacing to copper is needed to ensure that the film stays safely attached. We recommend that you revise your layout with increased spacing and upload a new revision. If a plating of the through-hole is irrelevant, you can ignore this warning.
- The spacing between copper and the NPTHs listed below is too small and we were forced to remove some of the copper around it. You can highlight the affected NPTHs by clicking on them. As NPTHs are covered by a film during the plating of PTHs, sufficient spacing to the copper is needed to ensure that the film stays safely attached. We recommend that you revise your layout with increase spacing and upload a new revision. If a plating of the through-hole is irrelevant, you can ignore this warning.

I was wondering where you got your copy made. Sorry to open an issue about this, this would belong in the discussions but they are not enabled ...

jackw01, 2025-02-09:
I used JLCPCB to order the boards. PCBWAY should also be able to manufacture them. It looks like Aisler can not make these because of the large filled silkscreen areas. I haven't heard of that being an issue with any of the Chinese PCB suppliers I have used.

Closed 2025-02-09.

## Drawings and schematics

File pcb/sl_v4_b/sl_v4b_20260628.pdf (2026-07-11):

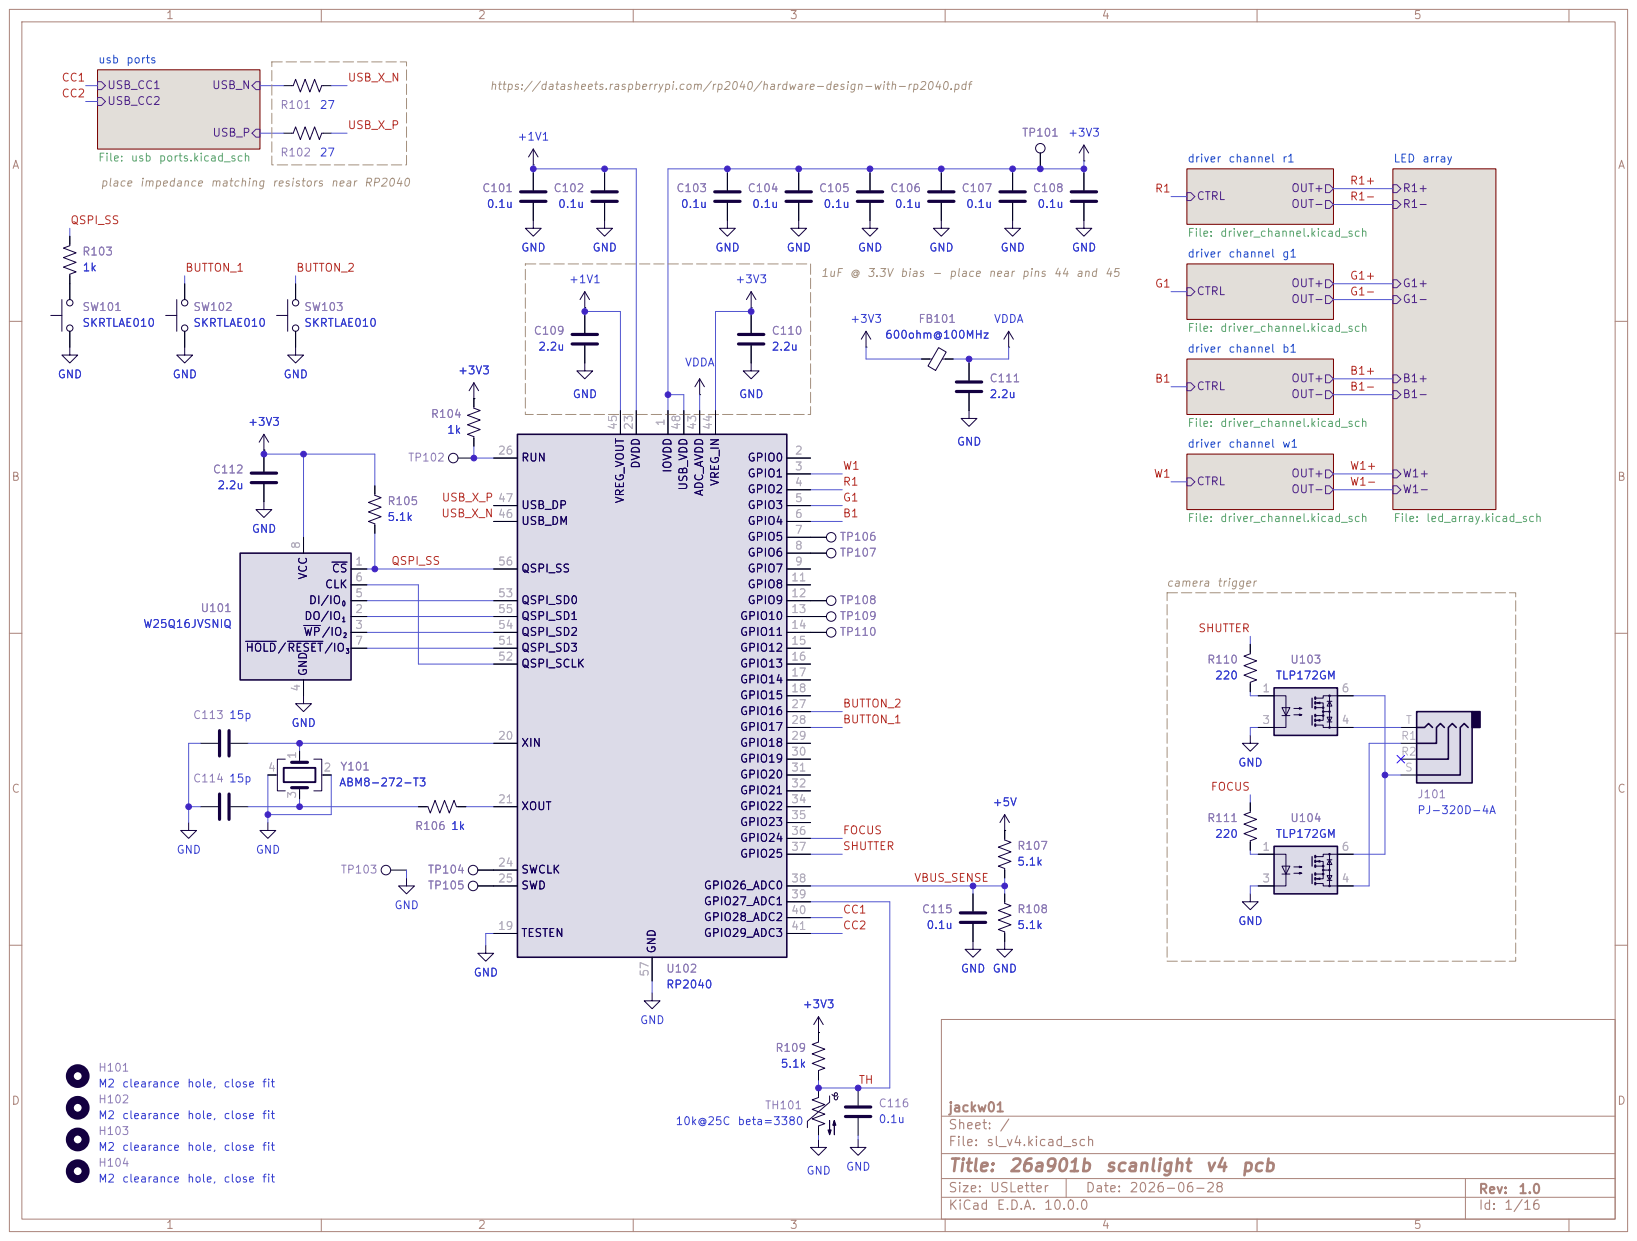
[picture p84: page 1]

https://datasheets.raspberrypi.com/rp2040/hardware-design-with-rp2040.pdf

place impedance matching resistors near RP2040

1uF @ 3.3V bias - place near pins 44 and 45

4 DI/IO0 5 CLK 6 HOLD/RESET/IO3 7 VCC

Size: USLetter | Rev: 1.0

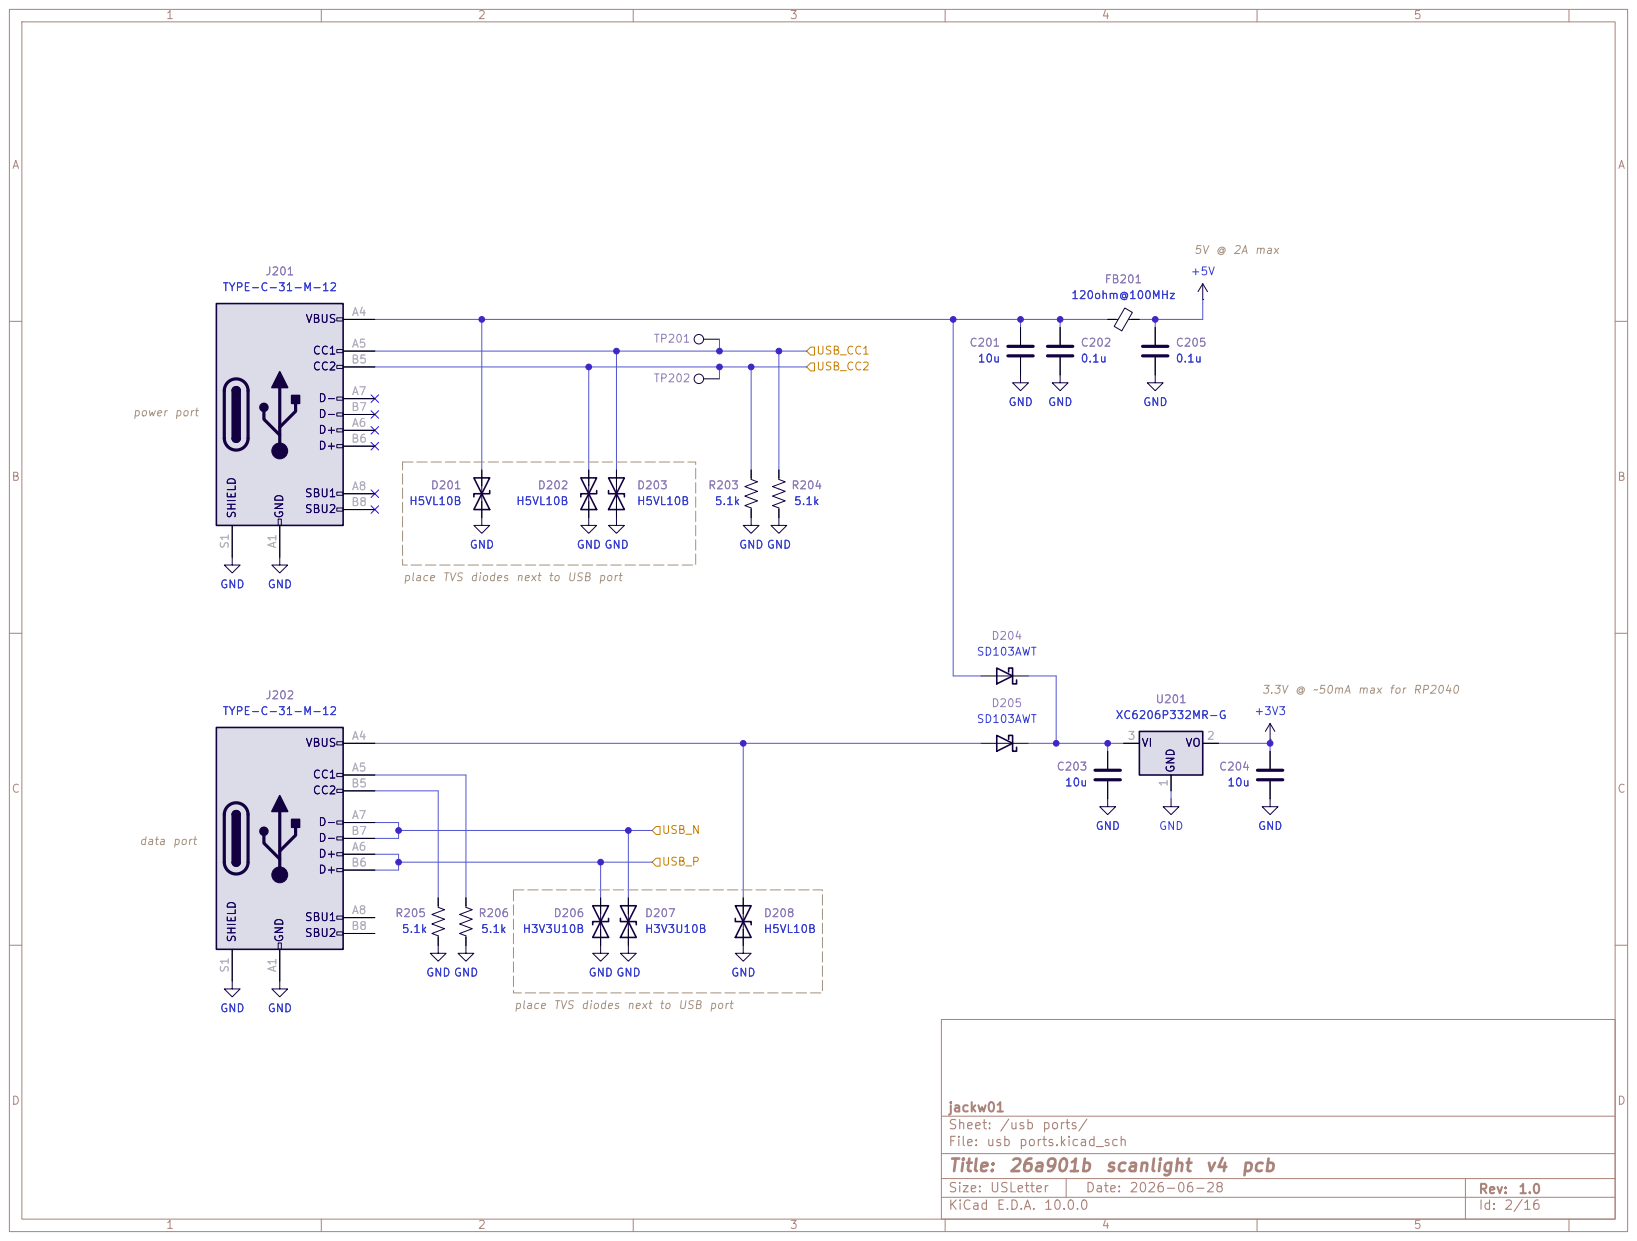
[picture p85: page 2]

place TVS diodes next to USB port

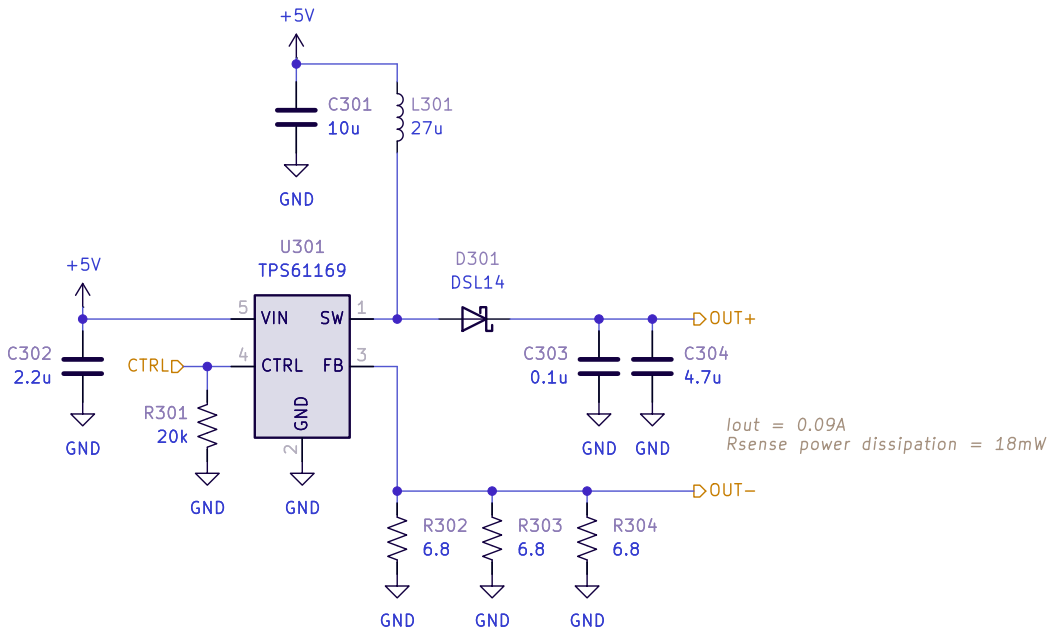
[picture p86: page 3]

Iout = 0.09A Rsense power dissipation = 18mW

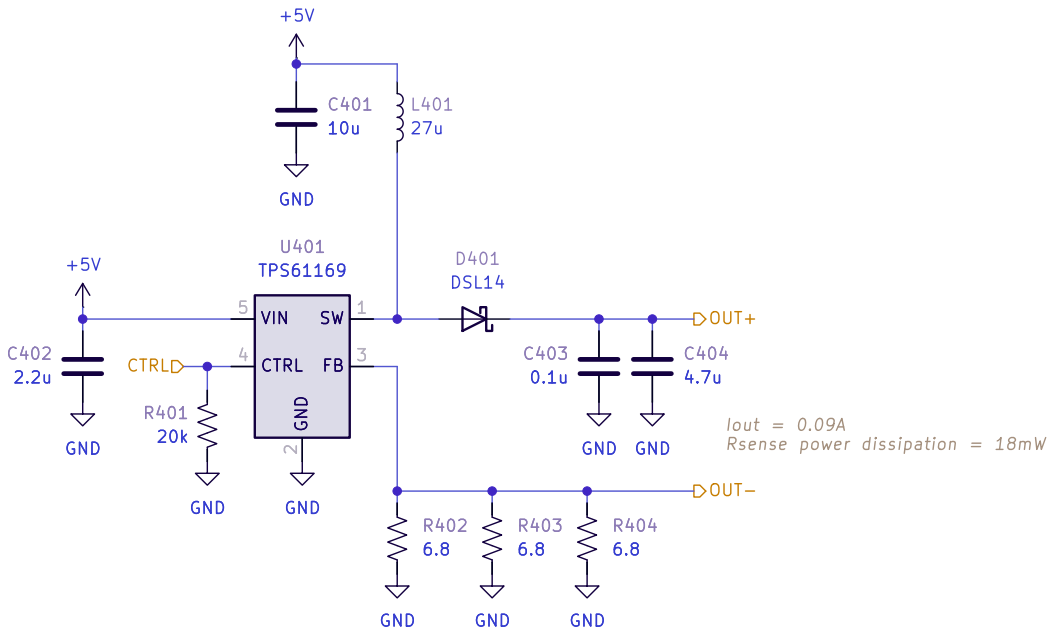
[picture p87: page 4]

Iout = 0.09A Rsense power dissipation = 18mW

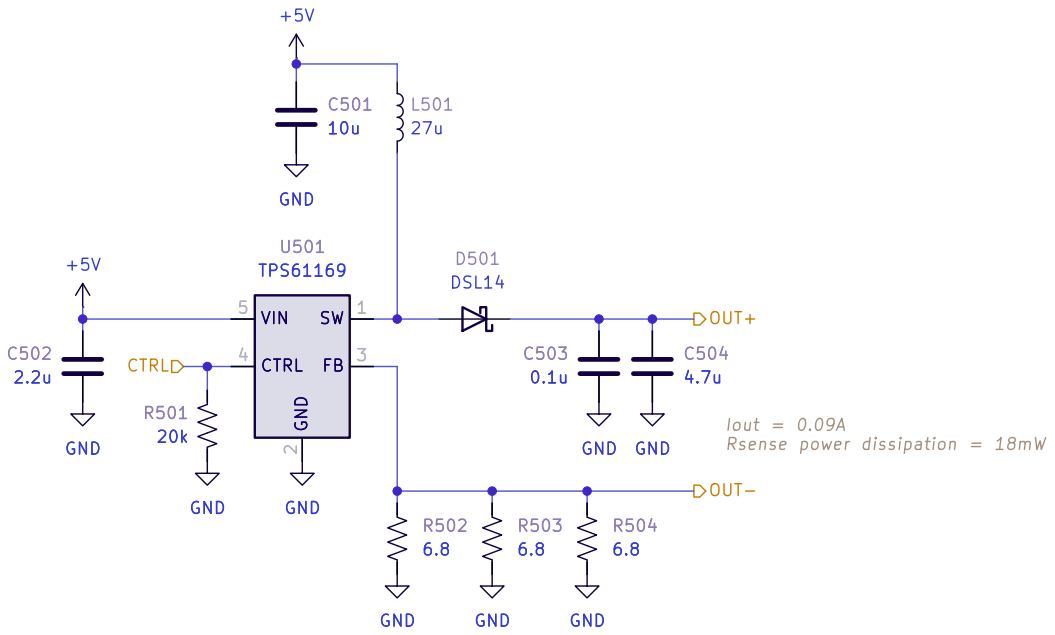
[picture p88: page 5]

Iout = 0.09A Rsense power dissipation = 18mW

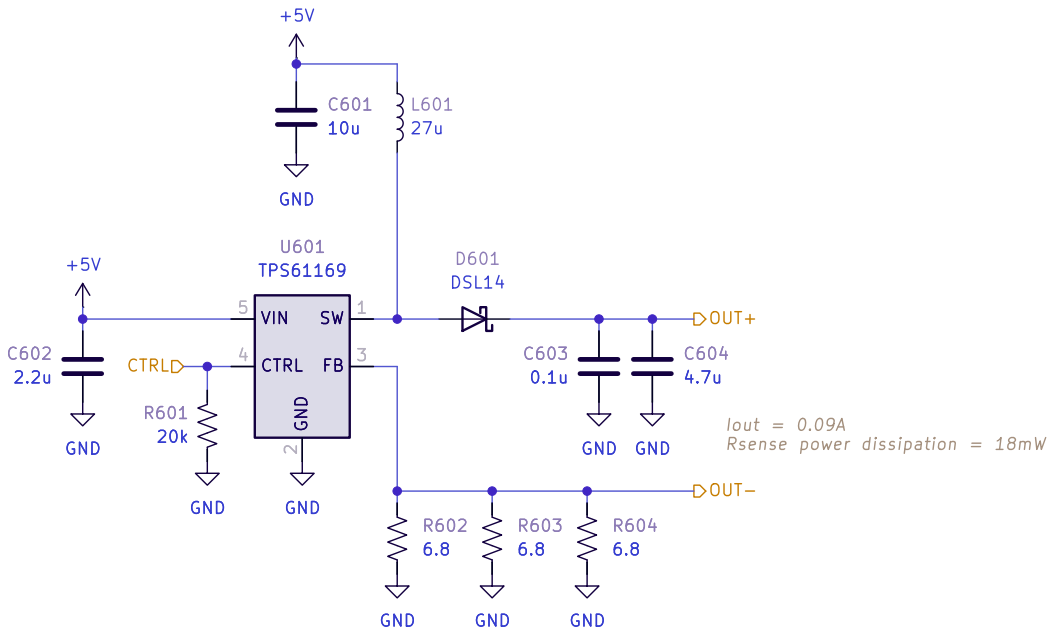
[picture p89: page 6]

Iout = 0.09A Rsense power dissipation = 18mW

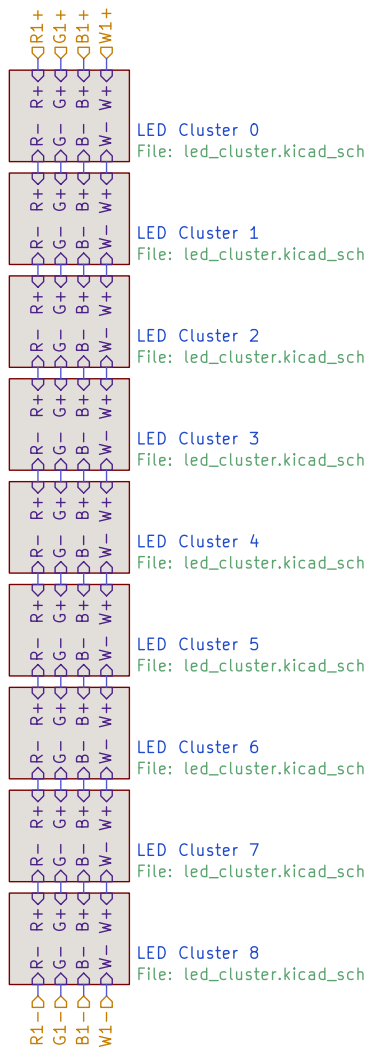
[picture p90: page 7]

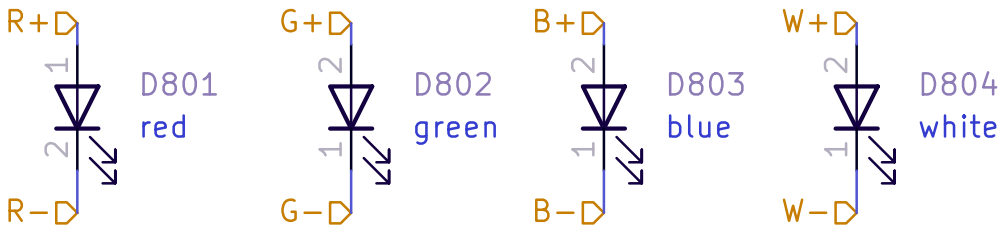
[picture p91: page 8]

jackw01
Sheet: /LED array/LED Cluster 0/

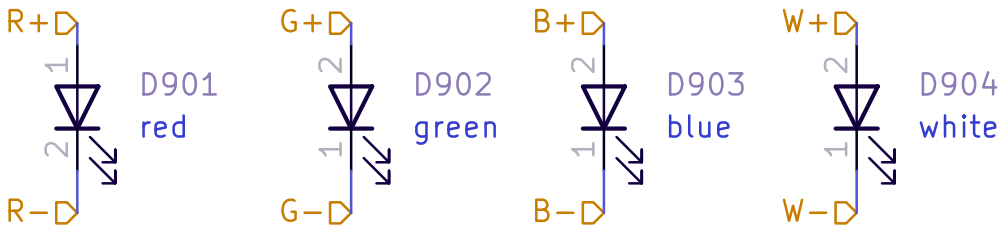
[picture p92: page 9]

jackw01
Sheet: /LED array/LED Cluster 1/

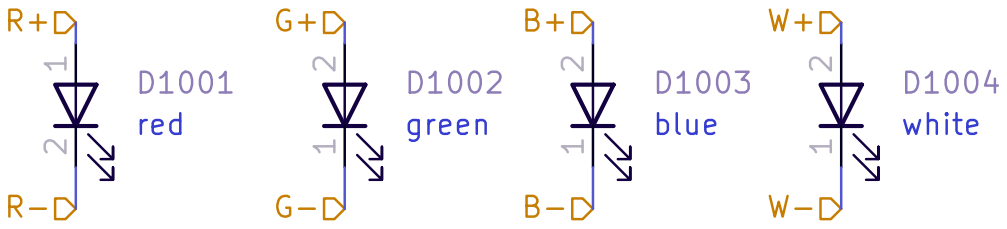
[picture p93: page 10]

jackw01
Sheet: /LED array/LED Cluster 2/

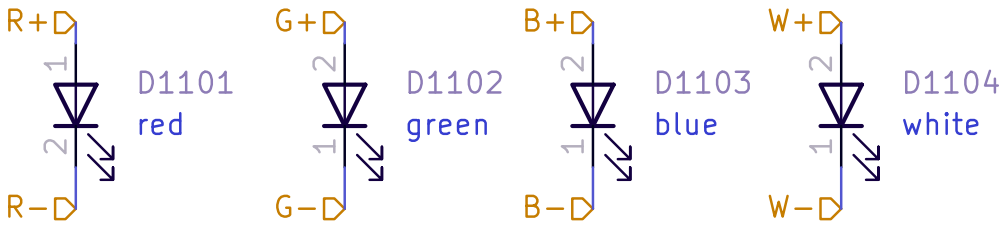
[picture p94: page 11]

jackw01
Sheet: /LED array/LED Cluster 3/

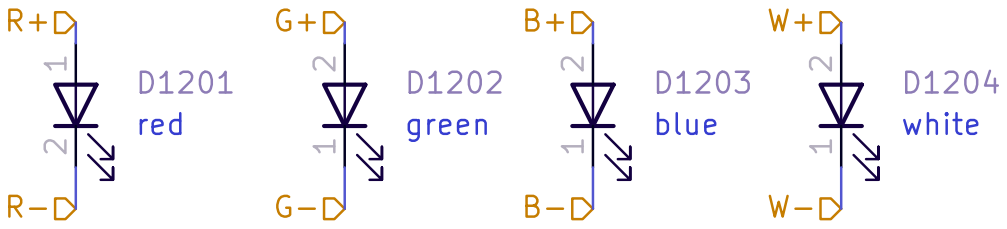
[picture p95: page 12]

jackw01
Sheet: /LED array/LED Cluster 4/


jackw01
Sheet: /LED array/LED Cluster 5/


jackw01
Sheet: /LED array/LED Cluster 6/


jackw01
Sheet: /LED array/LED Cluster 7/


jackw01
Sheet: /LED array/LED Cluster 8/

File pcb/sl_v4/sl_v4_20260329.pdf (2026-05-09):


https://datasheets.raspberrypi.com/rp2040/hardware-design-with-rp2040.pdf

1uF @ 3.3V bias - place near pins 44 and 45

4 DI/IO0 5 CLK 6 HOLD/RESET/IO3 7 VCC

Size: USLetter | Rev: 1.0


place TVS diodes next to USB port


Iout = 0.09A Rsense power dissipation = 18mW


Iout = 0.09A Rsense power dissipation = 18mW


Iout = 0.09A Rsense power dissipation = 18mW


Iout = 0.09A Rsense power dissipation = 18mW



jackw01
Sheet: /LED array/LED Cluster 0/


jackw01
Sheet: /LED array/LED Cluster 1/


jackw01
Sheet: /LED array/LED Cluster 2/


jackw01
Sheet: /LED array/LED Cluster 3/


jackw01
Sheet: /LED array/LED Cluster 4/


jackw01
Sheet: /LED array/LED Cluster 5/


jackw01
Sheet: /LED array/LED Cluster 6/


jackw01
Sheet: /LED array/LED Cluster 7/


jackw01
Sheet: /LED array/LED Cluster 8/

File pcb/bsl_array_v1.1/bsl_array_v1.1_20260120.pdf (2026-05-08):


File: bsl_array_v1.kicad_sch Sheet: /
Id: 1/1 Title: big scanlight array pcb

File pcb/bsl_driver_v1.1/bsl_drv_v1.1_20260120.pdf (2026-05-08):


https://datasheets.raspberrypi.com/rp2040/hardware-design-with-rp2040.pdf R106 1k GND Q101 BSS138 Y
USB_N

1uF @ 3.3V bias - place near pins 44 and 45

~{CS}1 CLK 6 DI/IO_{0}5 DO/IO_{1}2 ~{WP}/IO_{2} 3 ~{HOLD}/~{RESET}/IO_{3} 7 VCC

jackw01
File: bsl_drv_v1.kicad_sch Sheet: /
Id: 1/11 Title: big scanlight driver pcb


place nearby another 10uF cap on PCB

1 VOUT 3 GND GND GND

place TVS diodes next to USB port R206

Id: 2/11 Title: big scanlight driver pcb


Id: 3/11 Title: big scanlight driver pcb


2 SW 1 FB 3 U401 TPS61169 GND GND GND
D401 SD103AWS C402

2 SW 1 FB 3 GND GND

Id: 4/11 Title: big scanlight driver pcb


Id: 5/11 Title: big scanlight driver pcb


Id: 6/11 Title: big scanlight driver pcb


2 SW 1 FB 3 U701 TPS61169 GND GND GND
0.1u D701 SD103AWS C702

2 SW 1 FB 3 GND GND

Id: 7/11 Title: big scanlight driver pcb


Id: 8/11 Title: big scanlight driver pcb


Id: 9/11 Title: big scanlight driver pcb


2 SW 1 FB 3 GND GND

Id: 10/11 Title: big scanlight driver pcb


2 SW 1 FB 3 U1101 TPS61169 GND GND

Id: 11/11 Title: big scanlight driver pcb

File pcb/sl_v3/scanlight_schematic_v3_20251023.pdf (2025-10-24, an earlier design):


Input: 19-24V WARNING: most (all?) 2835 package deep red
(and some deep blue) LEDs have reversed polarity
for some reason! check datasheet before assembling!

2 SET 4 SW 1 GND GND


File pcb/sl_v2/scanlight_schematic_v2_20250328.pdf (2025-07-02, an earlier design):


(and some deep blue) LEDs have reversed polarity
for some reason! check datasheet before assembling!


install R203 to request 20V, remove to request 15V GND

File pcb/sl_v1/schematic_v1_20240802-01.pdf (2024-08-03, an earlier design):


(and some deep blue) LEDs have reversed polarity
for some reason! check datasheet before assembling!


install R203 to request 20V, remove to request 15V

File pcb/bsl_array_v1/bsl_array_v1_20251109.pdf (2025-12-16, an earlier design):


File: bsl_array_v1.kicad_sch Sheet: /
Id: 1/1 Title: big scanlight array pcb

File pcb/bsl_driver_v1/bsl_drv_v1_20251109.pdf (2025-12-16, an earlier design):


1uF @ 3.3V bias - place near pins 44 and 45

~{CS}1 CLK 6 DI/IO_{0}5 DO/IO_{1}2 ~{WP}/IO_{2} 3 ~{HOLD}/~{RESET}/IO_{3} 7 VCC

jackw01
File: bsl_drv_v1.kicad_sch Sheet: /
Id: 1/11 Title: big scanlight driver pcb


place nearby another 10uF cap on PCB

1 VOUT 3 GND GND GND

place TVS diodes next to USB port GND

1 VOUT 3 U202 HT7533-1 D205 SD103AWS SHIELD S1 GND A1 VBUS A4 CC1 A5 CC2 B5 D- A7 D- B7 D+ A6 D+ B6 SBU1 A8 SBU2 B8

Id: 2/11 Title: big scanlight driver pcb


Id: 3/11 Title: big scanlight driver pcb


Id: 4/11 Title: big scanlight driver pcb


2 SW 1 FB 3 U501 TPS61169 GND GND GND
D501 SD103AWS C502

2 SW 1 FB 3 GND GND

Id: 5/11 Title: big scanlight driver pcb


Id: 6/11 Title: big scanlight driver pcb


Id: 7/11 Title: big scanlight driver pcb


2 SW 1 FB 3 U801 TPS61169 GND GND GND
0.1u D801 SD103AWS C802

2 SW 1 FB 3 GND GND

Id: 8/11 Title: big scanlight driver pcb


Id: 9/11 Title: big scanlight driver pcb


Id: 10/11 Title: big scanlight driver pcb


Id: 11/11 Title: big scanlight driver pcb

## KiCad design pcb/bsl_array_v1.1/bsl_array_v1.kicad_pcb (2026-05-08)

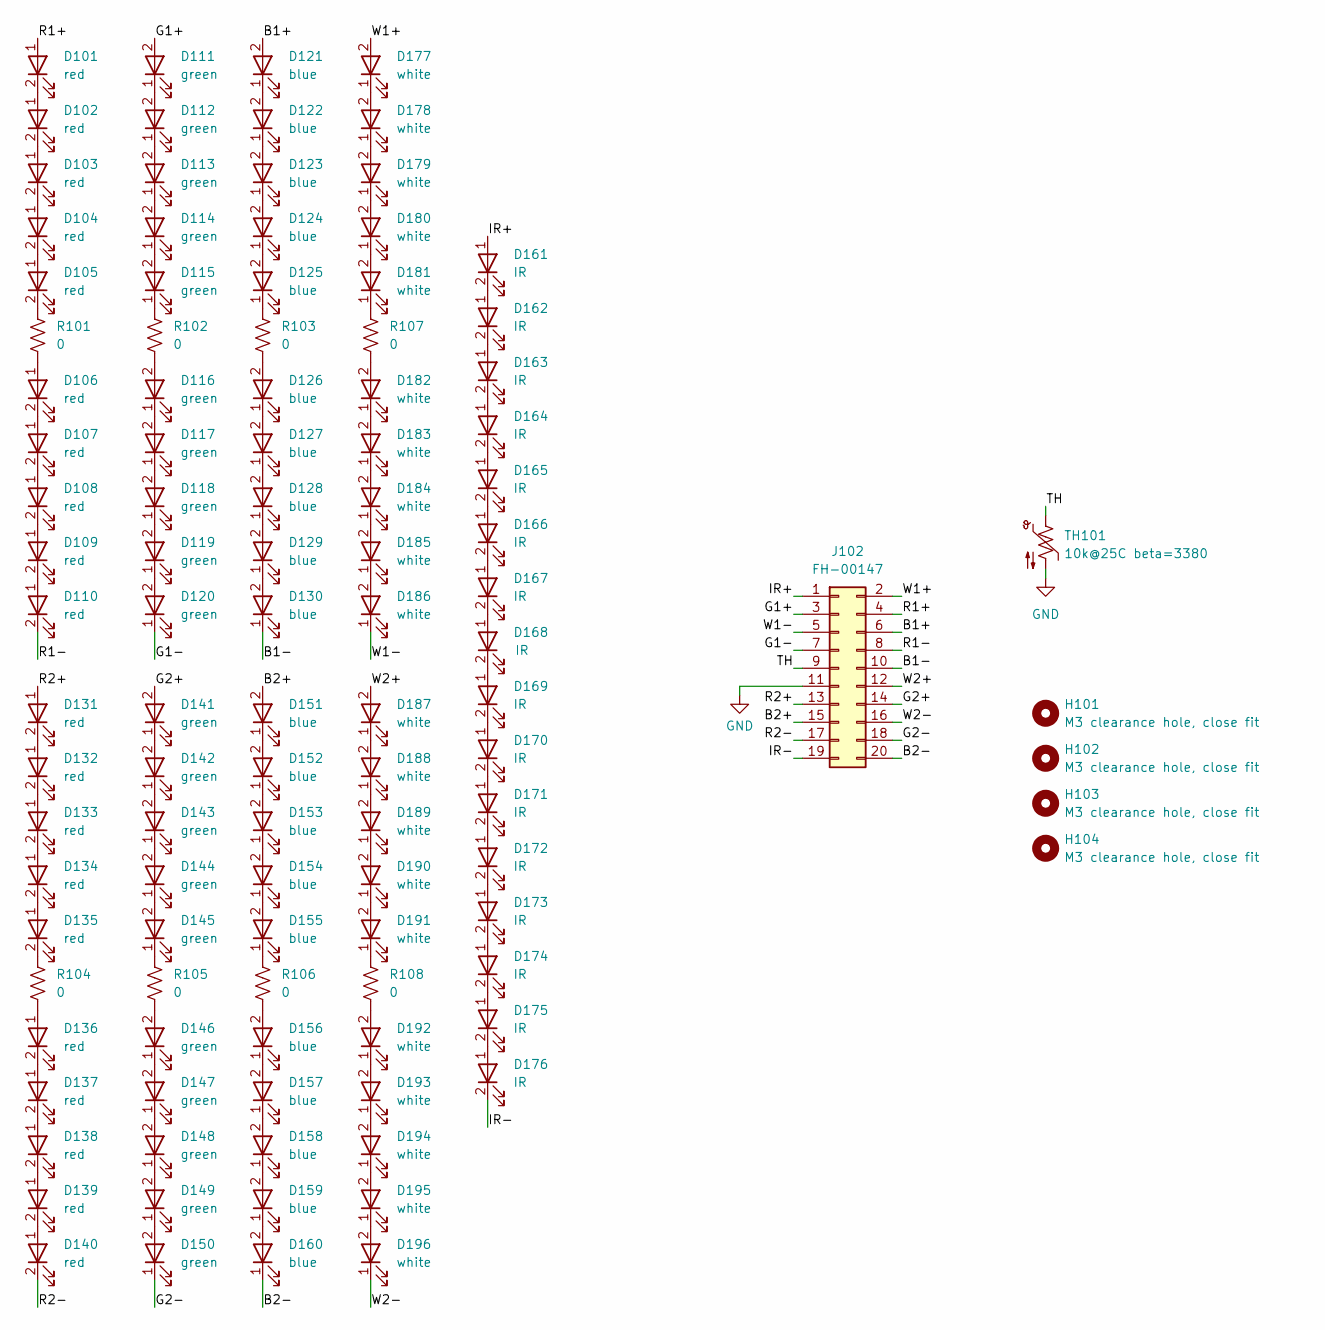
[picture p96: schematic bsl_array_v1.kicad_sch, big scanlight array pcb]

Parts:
D101, D102, D103, D104, D105, D106, D107, D108, D109, D110, D131, D132, D133, D134, D135, D136, D137, D138, D139, D140: red; LED_2835_Reversed_Red; MPN HL-AS-2835D15FC-S1-08-PCT-ZW-P6; LCSC C49435764
D111, D112, D113, D114, D115, D116, D117, D118, D119, D120, D141, D142, D143, D144, D145, D146, D147, D148, D149, D150: green; LED_2835; MPN TJ-S2835UG5W8TLC2G-A5; LCSC C440451
D121, D122, D123, D124, D125, D126, D127, D128, D129, D130, D151, D152, D153, D154, D155, D156, D157, D158, D159, D160: blue; LED_2835; MPN TJ-S2835UG5W8TLC6B-A5; LCSC C440452
D161, D162, D163, D164, D165, D166, D167, D168, D169, D170, D171, D172, D173, D174, D175, D176: IR; LED_2835_Reversed_Red; MPN P2835P1IRS7G12 850nm; LCSC C22466172
D177, D178, D179, D180, D181, D182, D183, D184, D185, D186, D187, D188, D189, D190, D191, D192, D193, D194, D195, D196: white; LED_2835; MPN HL-AM-2835H421W-S1-08-HR6(SDCM<6)(4750K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; LCSC C516133
H101, H102, H103, H104: M3 clearance hole, close fit; MountingHole_3.2mm_M3_Mask
J102: FH-00147; PinSocket_2x10_P2.00mm_Vertical_SMD; MPN FH-00147; LCSC C2685091
R101, R102, R103, R104, R105, R106, R107, R108: 0; R_1206_3216Metric; MPN 1206W4F0000T5E; LCSC C17888
TH101: 10k@25C beta=3380; R_0603_1608Metric; MPN NCP18XH103F03RB; LCSC C13564

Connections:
/B1+: D121.2 (A), J102.6
/B1-: D130.1 (K), J102.10
/B2+: D151.2 (A), J102.15
/B2-: D160.1 (K), J102.20
/G1+: D111.2 (A), J102.3
/G1-: D120.1 (K), J102.7
/G2+: D141.2 (A), J102.14
/G2-: D150.1 (K), J102.18
/IR+: D161.1 (A), J102.1
/IR-: D176.2 (K), J102.19
/R1+: D101.1 (A), J102.4
/R1-: D110.2 (K), J102.8
/R2+: D131.1 (A), J102.13
/R2-: D140.2 (K), J102.17
/TH: J102.9, TH101.1
/W1+: D177.2 (A), J102.2
/W1-: D186.1 (K), J102.5
/W2+: D187.2 (A), J102.12
/W2-: D196.1 (K), J102.16
GND: J102.11, TH101.2
unnamed: D101.2 (K), D102.1 (A)
unnamed: D102.2 (K), D103.1 (A)
unnamed: D103.2 (K), D104.1 (A)
unnamed: D104.2 (K), D105.1 (A)
unnamed: D105.2 (K), R101.1
unnamed: D106.1 (A), R101.2
unnamed: D106.2 (K), D107.1 (A)
unnamed: D107.2 (K), D108.1 (A)
unnamed: D108.2 (K), D109.1 (A)
unnamed: D109.2 (K), D110.1 (A)
unnamed: D111.1 (K), D112.2 (A)
unnamed: D112.1 (K), D113.2 (A)
unnamed: D113.1 (K), D114.2 (A)
unnamed: D114.1 (K), D115.2 (A)
unnamed: D115.1 (K), R102.1
unnamed: D116.2 (A), R102.2
unnamed: D116.1 (K), D117.2 (A)
unnamed: D117.1 (K), D118.2 (A)
unnamed: D118.1 (K), D119.2 (A)
unnamed: D119.1 (K), D120.2 (A)
unnamed: D121.1 (K), D122.2 (A)
unnamed: D122.1 (K), D123.2 (A)
unnamed: D123.1 (K), D124.2 (A)
unnamed: D124.1 (K), D125.2 (A)
unnamed: D125.1 (K), R103.1
unnamed: D126.2 (A), R103.2
unnamed: D126.1 (K), D127.2 (A)
unnamed: D127.1 (K), D128.2 (A)
unnamed: D128.1 (K), D129.2 (A)
unnamed: D129.1 (K), D130.2 (A)
unnamed: D131.2 (K), D132.1 (A)
unnamed: D132.2 (K), D133.1 (A)
unnamed: D133.2 (K), D134.1 (A)
unnamed: D134.2 (K), D135.1 (A)
unnamed: D135.2 (K), R104.1
unnamed: D136.1 (A), R104.2
unnamed: D136.2 (K), D137.1 (A)
unnamed: D137.2 (K), D138.1 (A)
unnamed: D138.2 (K), D139.1 (A)
unnamed: D139.2 (K), D140.1 (A)
unnamed: D141.1 (K), D142.2 (A)
unnamed: D142.1 (K), D143.2 (A)
unnamed: D143.1 (K), D144.2 (A)
unnamed: D144.1 (K), D145.2 (A)
unnamed: D145.1 (K), R105.1
unnamed: D146.2 (A), R105.2
unnamed: D146.1 (K), D147.2 (A)
unnamed: D147.1 (K), D148.2 (A)
unnamed: D148.1 (K), D149.2 (A)
unnamed: D149.1 (K), D150.2 (A)
unnamed: D151.1 (K), D152.2 (A)
unnamed: D152.1 (K), D153.2 (A)
unnamed: D153.1 (K), D154.2 (A)
unnamed: D154.1 (K), D155.2 (A)
unnamed: D155.1 (K), R106.1
unnamed: D156.2 (A), R106.2
unnamed: D156.1 (K), D157.2 (A)
unnamed: D157.1 (K), D158.2 (A)
unnamed: D158.1 (K), D159.2 (A)
unnamed: D159.1 (K), D160.2 (A)
unnamed: D161.2 (K), D162.1 (A)
unnamed: D162.2 (K), D163.1 (A)
unnamed: D163.2 (K), D164.1 (A)
unnamed: D164.2 (K), D165.1 (A)
unnamed: D165.2 (K), D166.1 (A)
unnamed: D166.2 (K), D167.1 (A)
unnamed: D167.2 (K), D168.1 (A)
unnamed: D168.2 (K), D169.1 (A)
unnamed: D169.2 (K), D170.1 (A)
unnamed: D170.2 (K), D171.1 (A)
unnamed: D171.2 (K), D172.1 (A)
unnamed: D172.2 (K), D173.1 (A)
unnamed: D173.2 (K), D174.1 (A)
unnamed: D174.2 (K), D175.1 (A)
unnamed: D175.2 (K), D176.1 (A)
unnamed: D177.1 (K), D178.2 (A)
unnamed: D178.1 (K), D179.2 (A)
unnamed: D179.1 (K), D180.2 (A)
unnamed: D180.1 (K), D181.2 (A)
unnamed: D181.1 (K), R107.1
unnamed: D182.2 (A), R107.2
unnamed: D182.1 (K), D183.2 (A)
unnamed: D183.1 (K), D184.2 (A)
unnamed: D184.1 (K), D185.2 (A)
unnamed: D185.1 (K), D186.2 (A)
unnamed: D187.1 (K), D188.2 (A)
unnamed: D188.1 (K), D189.2 (A)
unnamed: D189.1 (K), D190.2 (A)
unnamed: D190.1 (K), D191.2 (A)
unnamed: D191.1 (K), R108.1
unnamed: D192.2 (A), R108.2
unnamed: D192.1 (K), D193.2 (A)
unnamed: D193.1 (K), D194.2 (A)
unnamed: D194.1 (K), D195.2 (A)
unnamed: D195.1 (K), D196.2 (A)

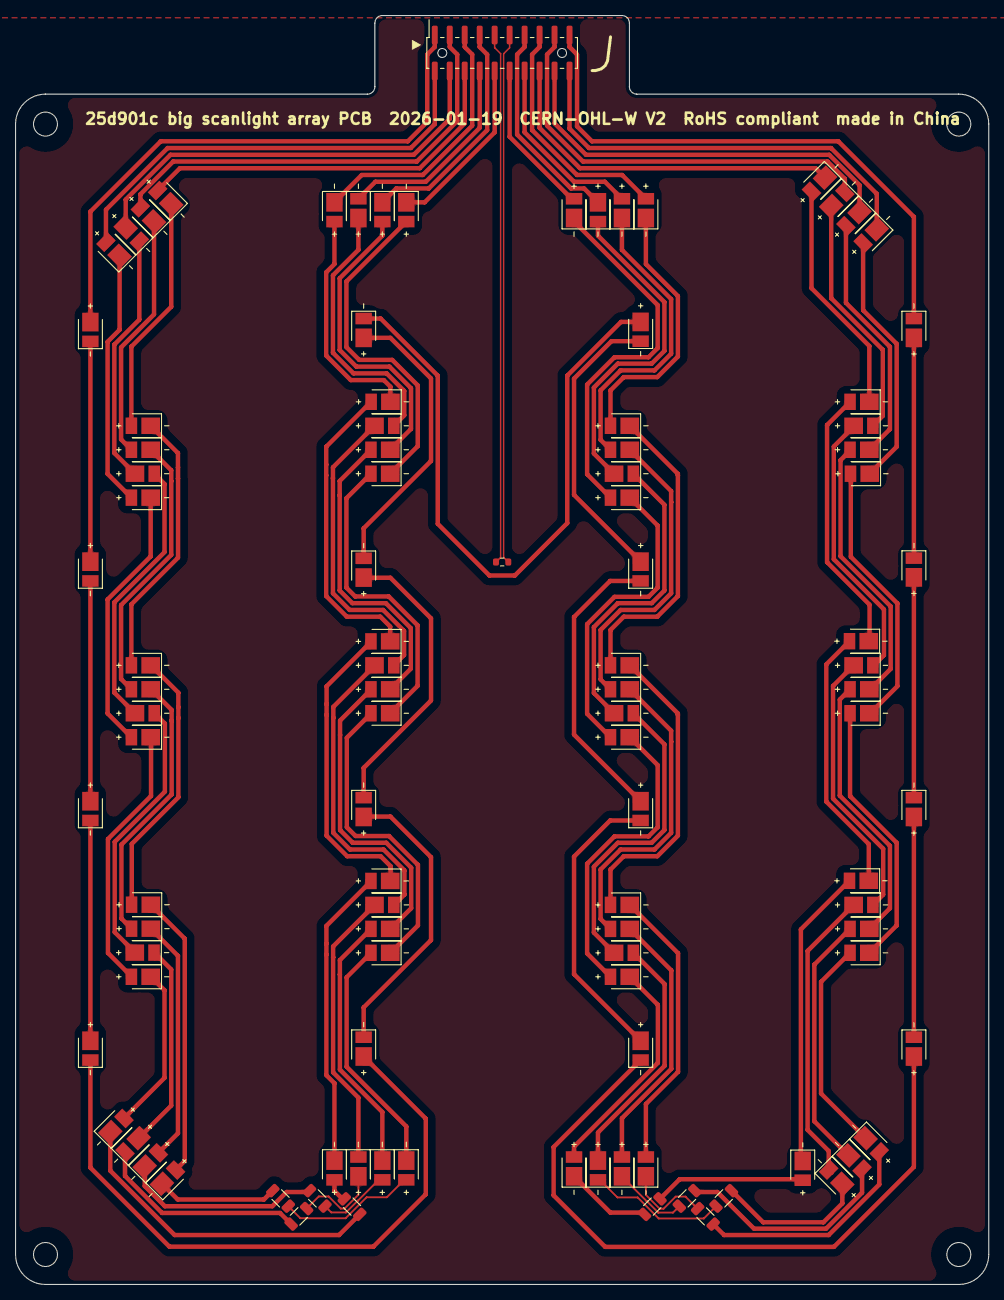
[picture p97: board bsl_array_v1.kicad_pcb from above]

Board: 2 copper layers, 130.0 x 169.5 mm, 110 parts (0 on the bottom side), 115 nets.

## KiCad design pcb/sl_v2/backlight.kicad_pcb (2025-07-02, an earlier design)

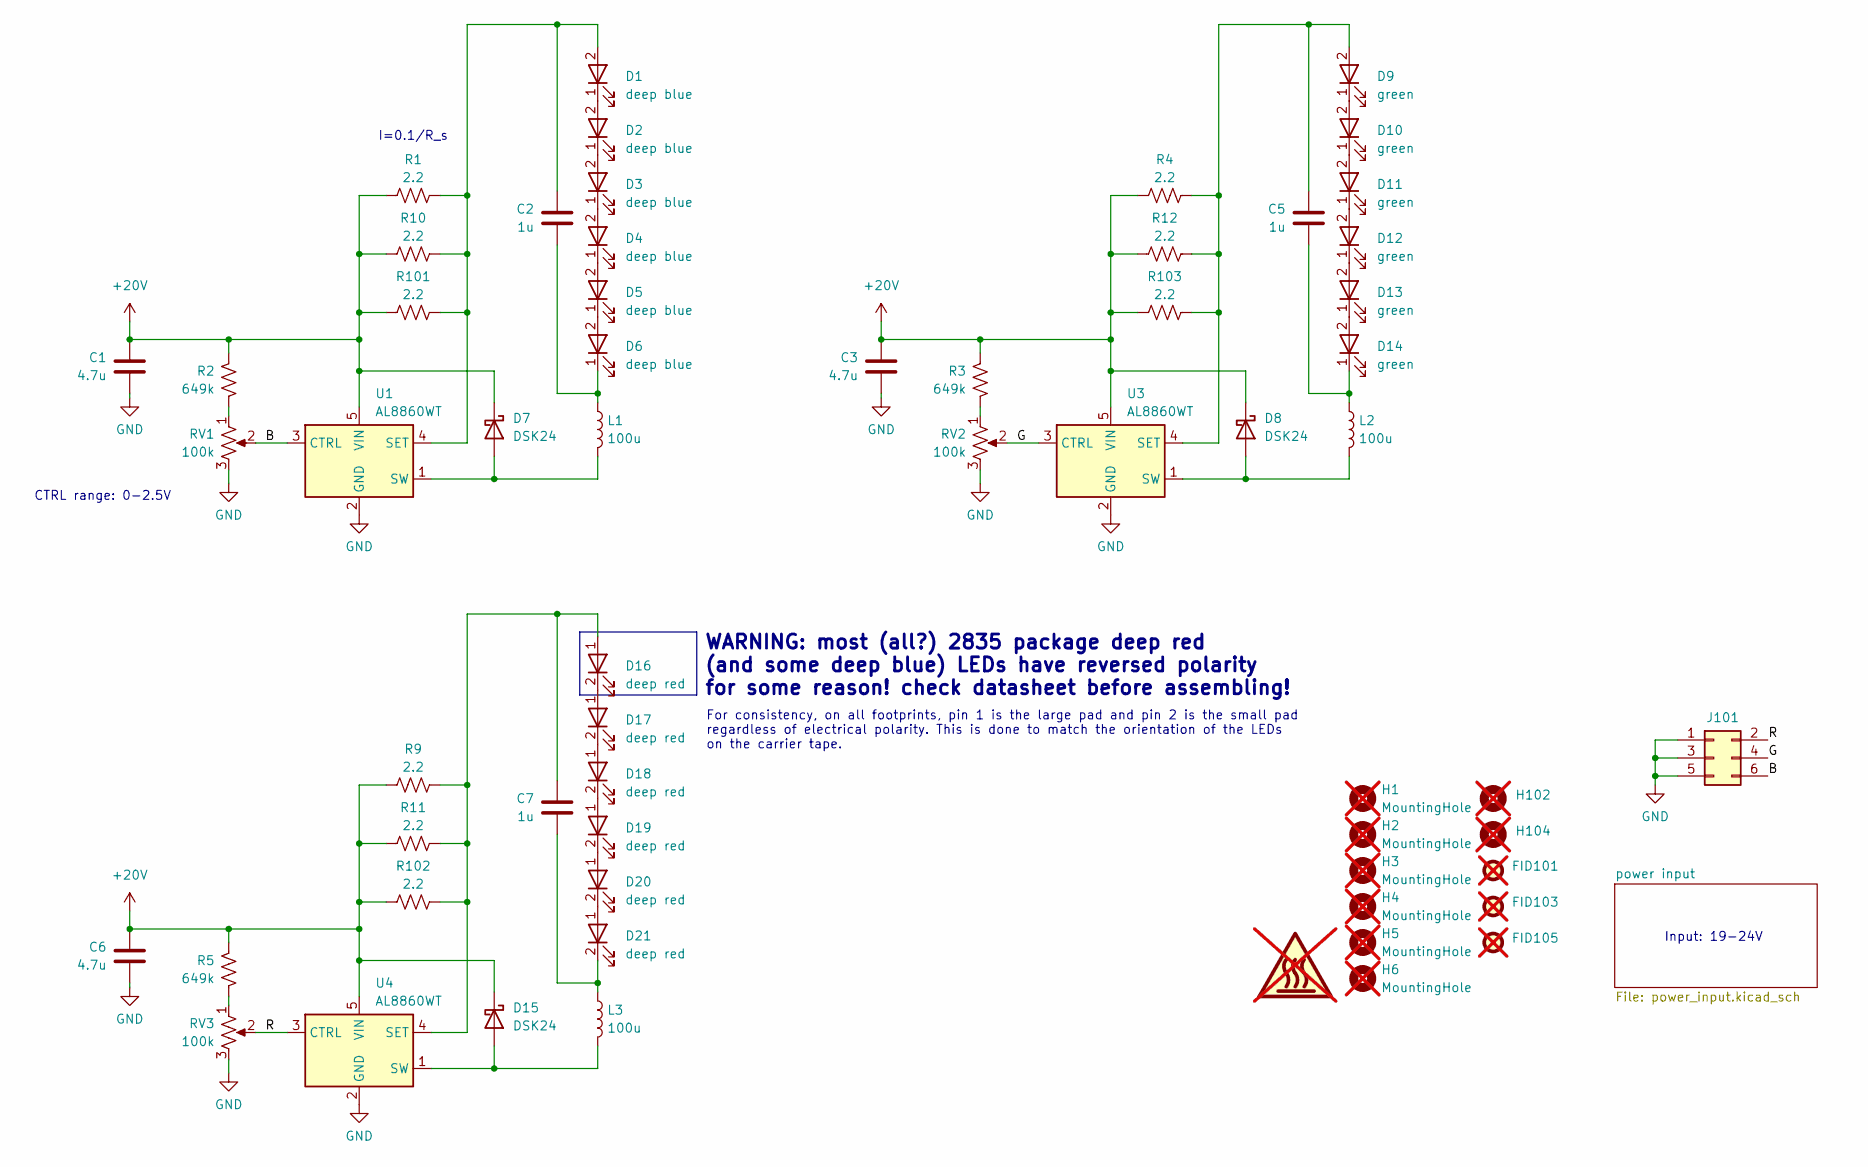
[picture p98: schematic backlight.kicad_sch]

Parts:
C1, C3, C6: 4.7u; C_1206_3216Metric; MPN Generic 4.7uF 50V 1206 X7R; LCSC C29823
C2, C5, C7: 1u; C_0805_2012Metric; MPN Generic 1uF 50V 0805 X7R; LCSC C28323
D1, D2, D3, D4, D5, D6: deep blue; LED_PLCC_2835_Handsoldering; MPN JE2835ARY-N-0002A0000-N0000001; LCSC C9900080487
D7, D8, D15: DSK24; D_SOD-123F; MPN DSK24; LCSC C22466352
D9, D10, D11, D12, D13, D14: green; LED_PLCC_2835_Handsoldering; MPN JE2835AGR-N-0002A0000-N0000001; LCSC C6159257
D16, D17, D18, D19, D20, D21: deep red; LED_PLCC_2835_Handsoldering_Reversed_Red; MPN JE2835AHR-N-0001A0000-N0000001; LCSC C17235048
FID101, FID103, FID105: Fiducial_1mm_Mask2mm; not fitted
H1, H2, H3, H4, H5, H6: MountingHole; MountingHole_2.2mm_M2_Mask_5mm; not fitted
H102, H104: ToolingHole; JLC_tooling_hole; not fitted
J101: Conn_02x03_Odd_Even; PinHeader_2x03_P2.54mm_Vertical_SMD; MPN IPCP254M06PB28S; LCSC C22438447
L1, L2, L3: 100u; L_Changjiang_FNR5040S; MPN SLW5040S101MST; LCSC C206391
R1, R4, R9, R10, R11, R12, R101, R102, R103: 2.2; R_0603_1608Metric; MPN Generic 2.2Ohm 0603 1%; LCSC C22939
R2, R3, R5: 649k; R_0603_1608Metric; MPN Generic 649KOhm 0603 1%; LCSC C245991
RV1, RV2, RV3: 100k; Potentiometer_Bourns_3314G_Vertical; MPN 3314G-1-104E; LCSC C780219
SYM101: SYM_Hot_Large; hot-surface_1x; not fitted
U1, U3, U4: AL8860WT; TSOT-23-5; MPN AL8860WT-7; LCSC C125330

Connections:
+20V: C1.1, C3.1, C6.1, D7.1 (K), D8.1 (K), D15.1 (K), R1.1, R2.1, R3.1, R4.1, R5.1, R9.1, R10.1, R11.1, R12.1, R101.1, R102.1, R103.1, U1.5 (VIN), U3.5 (VIN), U4.5 (VIN); also elsewhere on the board
/B: J101.6, RV1.2, U1.3 (CTRL)
/G: J101.4, RV2.2, U3.3 (CTRL)
/R: J101.2, RV3.2, U4.3 (CTRL)
GND: C1.2, C3.2, C6.2, J101.1, J101.3, J101.5, RV1.3, RV2.3, RV3.3, U1.2 (GND), U3.2 (GND), U4.2 (GND); also elsewhere on the board
unnamed: C2.1, D1.2 (A), R1.2, R10.2, R101.2, U1.4 (SET)
unnamed: D1.1 (K), D2.2 (A)
unnamed: D2.1 (K), D3.2 (A)
unnamed: D3.1 (K), D4.2 (A)
unnamed: D4.1 (K), D5.2 (A)
unnamed: D5.1 (K), D6.2 (A)
unnamed: C2.2, D6.1 (K), L1.1
unnamed: D7.2 (A), L1.2, U1.1 (SW)
unnamed: D8.2 (A), L2.2, U3.1 (SW)
unnamed: C5.1, D9.2 (A), R4.2, R12.2, R103.2, U3.4 (SET)
unnamed: D9.1 (K), D10.2 (A)
unnamed: D10.1 (K), D11.2 (A)
unnamed: D11.1 (K), D12.2 (A)
unnamed: D12.1 (K), D13.2 (A)
unnamed: D13.1 (K), D14.2 (A)
unnamed: C5.2, D14.1 (K), L2.1
unnamed: D15.2 (A), L3.2, U4.1 (SW)
unnamed: C7.1, D16.1 (A), R9.2, R11.2, R102.2, U4.4 (SET)
unnamed: D16.2 (K), D17.1 (A)
unnamed: D17.2 (K), D18.1 (A)
unnamed: D18.2 (K), D19.1 (A)
unnamed: D19.2 (K), D20.1 (A)
unnamed: D20.2 (K), D21.1 (A)
unnamed: C7.2, D21.2 (K), L3.1
unnamed: R2.2, RV1.1
unnamed: R3.2, RV2.1
unnamed: R5.2, RV3.1

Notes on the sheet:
Input: 19-24V
CTRL range: 0-2.5V
For consistency, on all footprints, pin 1 is the large pad and pin 2 is the small pad regardless of electrical polarity. This is done to match the orientation of the LEDs on the carrier tape.
I=0.1/R_s
WARNING: most (all?) 2835 package deep red (and some deep blue) LEDs have reversed polarity for some reason! check datasheet before assembling!

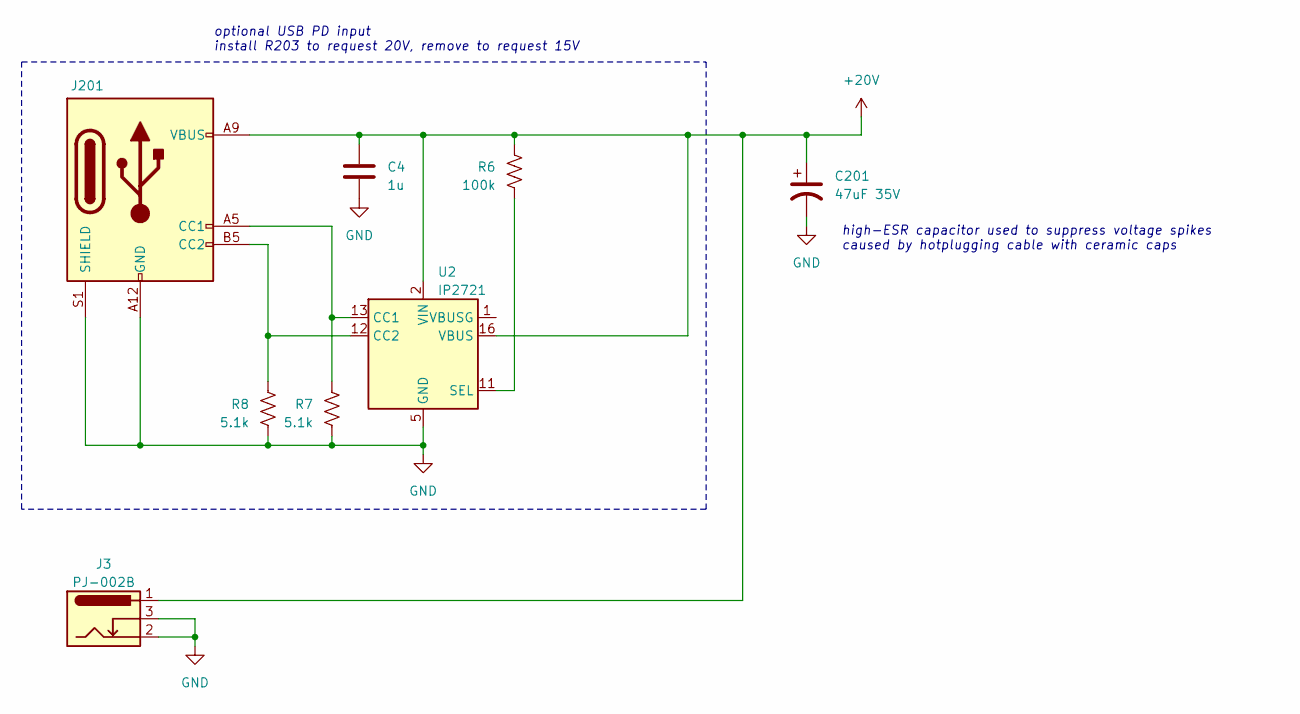
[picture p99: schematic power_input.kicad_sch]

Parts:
C4: 1u; C_0805_2012Metric; MPN Generic 1uF 50V 0805 X7R; LCSC C28323
C201: 47uF 35V; CP_Elec_6.3x5.8; MPN EEEFK1V470P; LCSC C178565
J3: PJ-002B; BarrelJack_GCT_DCJ200-10-A_Horizontal; MPN DC-005-2.5A-2.0; LCSC C319099
J201: USB_C_Receptacle_PowerOnly_6P; USB_C_Receptacle_6PIN_generic; MPN TYPE-C 6P(073); LCSC C668623
R6: 100k; R_0603_1608Metric; MPN Generic 100KOhm 0603 5%; LCSC C25803
R7, R8: 5.1k; R_0603_1608Metric; MPN Generic 5.1KOhm 0603 5%; LCSC C23186
U2: IP2721; TSSOP-16_4.4x5mm_P0.65mm; MPN IP2721; LCSC C603176

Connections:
+20V: C4.2, C201.1, J3.1, J201.A9 (VBUS), J201.B9 (VBUS), R6.1, U2.2 (VIN), U2.16 (VBUS); also elsewhere on the board
GND: C4.1, C201.2, J3.2, J3.3, J201.A12 (GND), J201.B12 (GND), J201.S1 (SHIELD), R7.2, R8.2, U2.5 (GND); also elsewhere on the board
unnamed: J201.A5 (CC1), R7.1, U2.13 (CC1)
unnamed: J201.B5 (CC2), R8.1, U2.12 (CC2)
unnamed: R6.2, U2.11 (SEL)

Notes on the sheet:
optional USB PD input install R203 to request 20V, remove to request 15V
high-ESR capacitor used to suppress voltage spikes caused by hotplugging cable with ceramic caps

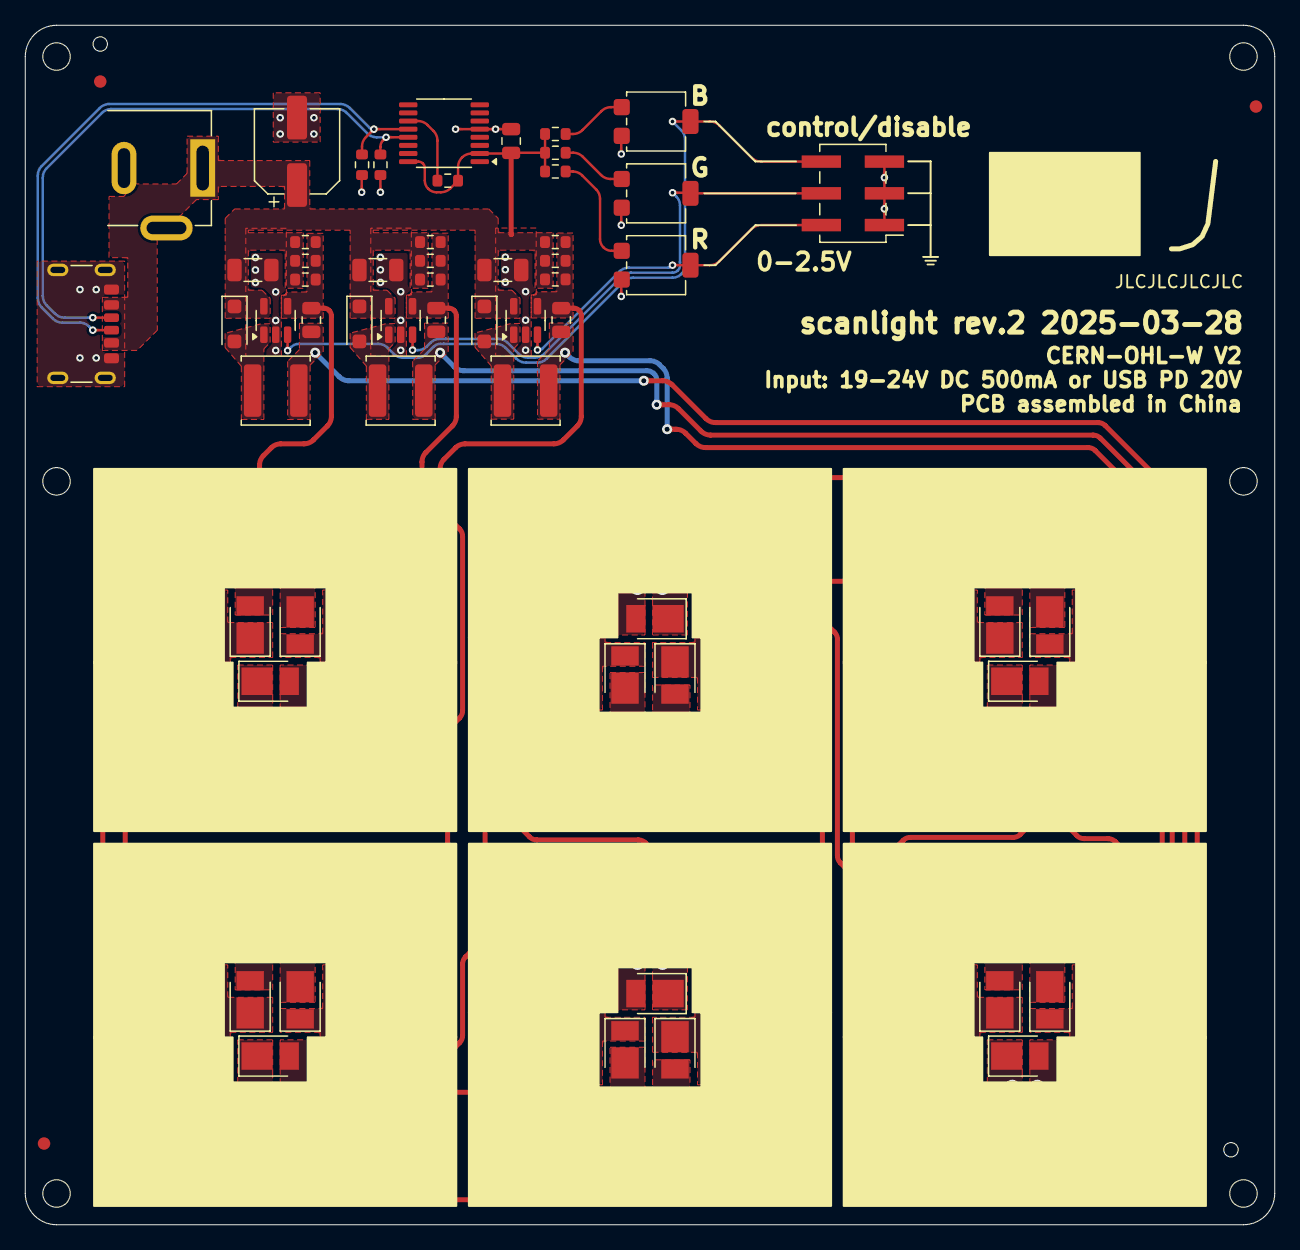
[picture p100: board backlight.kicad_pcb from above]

Board: 2 copper layers, 100.0 x 96.0 mm, 69 parts (1 on the bottom side), 35 nets.

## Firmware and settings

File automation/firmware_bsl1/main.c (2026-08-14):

#include <math.h>
#include <string.h>

#include "pico/stdlib.h"
#include "pico/bootrom.h"
#include "hardware/pwm.h"
#include "hardware/clocks.h"
#include "hardware/gpio.h"
#include "hardware/adc.h"
#include "hardware/sync.h"
#include "hardware/flash.h"

#include "button.h"

#include "config.h"
#include "protocol.h"

// R, G, B, W, IR
uint8_t color[5] = {0, 0, 0, 0, 0};
int8_t trim[5] = {0, 0, 0, 0, 0}; // 5th byte is used as flag for flash memory initialization
uint8_t rgb_preset[3] = {255, 255, 255};

uint32_t pwm_wrap;

OperatingMode operating_mode = OperatingModeOff;
uint32_t led_enable = 0;

uint32_t adc_reporting_timer = 1;
int32_t shutter_pulse_timer = -1;
int32_t led_temp_mdegc = 0;
int32_t vbus_mv = 0;
int32_t cc_mv = 0;

// PWM

void update_pwm_pin(uint32_t pin, uint8_t level, uint8_t scale1, uint8_t scale2)
{
  uint slice_num = pwm_gpio_to_slice_num(pin);
  uint channel = pwm_gpio_to_channel(pin);
  uint32_t level_scaled = (pwm_wrap * ((uint32_t)level * scale1) / 255) / 255;
  level_scaled = (level_scaled * scale2) / 255;
  pwm_set_chan_level(slice_num, channel, level_scaled);
}

void update_pwm()
{
  // ensure white and IR channels exclude other channels
  if (color[3] > 0)
  {
    color[0] = 0;
    color[1] = 0;
    color[2] = 0;
    color[4] = 0;
  }
  else if (color[4] > 0)
  {
      color[0] = 0;
      color[1] = 0;
      color[2] = 0;
      color[3] = 0;
  }

  // reduced power operating mode allows one channel at a time, or multichannel RGB at reduced power
  uint8_t scale = 255;
  uint8_t scaleIR = 255;

  uint32_t n_channels = 0;
  for (uint32_t i = 0; i < 5; i++)
  {
    if (color[i] > 0)
      n_channels++;
  }
  if (n_channels > 1)
    scale = PowerLimitRGB[operating_mode];
  else
    scale = PowerLimitSingleChannel[operating_mode];

  // led_enable overrides all other settings
  if (led_enable == 0)
  {
    scale = 0;
    scaleIR = 0;
  }

  update_pwm_pin(PinR1, color[0], (uint32_t)(trim[0] > 0 ? 255 - trim[0] : 255), scale);
  update_pwm_pin(PinG1, color[1], (uint32_t)(trim[1] > 0 ? 255 - trim[1] : 255), scale);
  update_pwm_pin(PinB1, color[2], (uint32_t)(trim[2] > 0 ? 255 - trim[2] : 255), scale);
  update_pwm_pin(PinW1, color[3], (uint32_t)(trim[3] > 0 ? 255 - trim[3] : 255), scale);
#ifdef HW_VERSION_BSL1
  update_pwm_pin(PinR2, color[0], (uint32_t)(trim[0] < 0 ? 255 + trim[0] : 255), scale);
  update_pwm_pin(PinG2, color[1], (uint32_t)(trim[1] < 0 ? 255 + trim[1] : 255), scale);
  update_pwm_pin(PinB2, color[2], (uint32_t)(trim[2] < 0 ? 255 + trim[2] : 255), scale);
  update_pwm_pin(PinW2, color[3], (uint32_t)(trim[3] < 0 ? 255 + trim[3] : 255), scale);
  update_pwm_pin(PinIR, color[4], 255, 255);
#endif
}

// ADC

float thermistor_voltage_to_temp(float v, const float lookup_table[][2])
{
  // convert voltage to temperature using a lookup table with linear interpolation
  // lookup table format:
  // float ThermistorLookUpTable[][2] = {
  //     {V, degrees C}, {V, degrees C}, ...
  // }
  // entries are assumed to be in descending order by voltage

  uint32_t count = sizeof(lookup_table) / sizeof(lookup_table[0]);

  if (v >= lookup_table[0][0])
    return lookup_table[0][1];

  if (v <= lookup_table[count - 1][0])
    return lookup_table[count - 1][1];

  for (uint32_t i = 0; i < count - 1; i++)
  {
    float v1 = lookup_table[i][0];
    float t1 = lookup_table[i][1];
    float v2 = lookup_table[i + 1][0];
    float t2 = lookup_table[i + 1][1];

    if (v <= v1 && v >= v2)
    {
      float f = (v - v2) / (v1 - v2);
      return t2 + f * (t1 - t2);
    }
  }

  return 0.0f;
}

int32_t adc_get_led_temp_mdegc()
{
#ifdef HW_VERSION_SL2
  return 0;
#else
  adc_select_input(PinADCThermistor);
  float raw_v = (float)adc_read() * ADCVPerCount;
  return (int32_t)(thermistor_voltage_to_temp(raw_v, ThermistorLookUpTable) * 1e3);
#endif
}

int32_t adc_get_vbus_mv()
{
#ifdef HW_VERSION_SL2
  return 0;
#else
  adc_select_input(PinADCVBUSSense);
  float raw_v = (float)adc_read() * ADCVPerCount;
  return (int32_t)(raw_v * ADCVBUSSenseScale * 1e3);
#endif
}


int32_t adc_get_cc_mv()
{
#ifdef HW_VERSION_SL4
  adc_select_input(PinADCUSBCC1);
  float raw_v1 = (float)adc_read() * ADCVPerCount;
  adc_select_input(PinADCUSBCC2);
  float raw_v2 = (float)adc_read() * ADCVPerCount;
  if (raw_v1 > raw_v2)
    return (int32_t)(raw_v1 * 1e3);
  else
    return (int32_t)(raw_v2 * 1e3);
#else
  return 3300;
#endif
}


// Flash

void write_preset_to_flash()
{
  uint32_t irq_state = save_and_disable_interrupts();

  uint8_t page_buffer[FLASH_PAGE_SIZE];
  memset(page_buffer, 0xFF, sizeof(page_buffer));
  memcpy(&page_buffer[FLASH_PERSIST_ADDR_RGB_PRESET], rgb_preset, 3);
  memcpy(&page_buffer[FLASH_PERSIST_ADDR_TRIM], trim, 5);

  flash_range_erase(FLASH_PERSIST_OFFSET, FLASH_SECTOR_SIZE);
  flash_range_program(FLASH_PERSIST_OFFSET, page_buffer, FLASH_PAGE_SIZE);

  restore_interrupts(irq_state);
}

void read_preset_from_flash()
{
  uint32_t flash_ptr = XIP_BASE + FLASH_PERSIST_OFFSET + FLASH_PERSIST_ADDR_RGB_PRESET;
  memcpy(rgb_preset, (const uint8_t *)flash_ptr, 3);

  if (rgb_preset[0] == 0 && rgb_preset[1] == 0 && rgb_preset[2] == 0)
  {
    rgb_preset[0] = 255;
    rgb_preset[1] = 255;
    rgb_preset[2] = 255;
  }

  flash_ptr = XIP_BASE + FLASH_PERSIST_OFFSET + FLASH_PERSIST_ADDR_TRIM;
  memcpy(trim, (const uint8_t *)flash_ptr, 5);

  // First read of flash memory?
  if (trim[4] == -1)
  {
    trim[0] = DefaultTrimR;
    trim[1] = DefaultTrimG;
    trim[2] = DefaultTrimB;
    trim[3] = DefaultTrimW;
    trim[4] = 0;
  }
}

// Button handler

void on_button_change(button_t *button_p)
{
  button_t *button = (button_t *)button_p;
  if (button->state)
    return; // Ignore button release

  switch (button->pin)
  {
    case PinButton1:
      // LED on/off toggle
      led_enable = !led_enable;
      // Check if turning on with no color set
      if (led_enable && color[0] == 0 && color[1] == 0 && color[2] == 0 && color[3] == 0 && color[4] == 0)
      {
        color[0] = rgb_preset[0];
        color[1] = rgb_preset[1];
        color[2] = rgb_preset[2];
      }
      update_pwm();
      break;
    case PinButton2:
      // RGB/white mode toggle
      if (color[3] > 0)
      {
        color[0] = rgb_preset[0];
        color[1] = rgb_preset[1];
        color[2] = rgb_preset[2];
        color[3] = 0;
      }
      else
      {
        color[0] = 0;
        color[1] = 0;
        color[2] = 0;
        color[3] = 255;
      }
      update_pwm();
      break;
  }
}

// Main loop

void tick(uint32_t millis, uint32_t dt_micros)
{
#ifndef HW_VERSION_SL2
  button_poll_events();
#endif
  protocol_tick();

  if (protocol_data.incoming_packet_ready != 0)
  {
    protocol_data.incoming_packet_ready = 0;
    switch (protocol_data.incoming_packet_header)
    {
      case PKT_H2D_SET_COLOR:
        memcpy(color, protocol_data.incoming_packet_data, 5);
        if (protocol_data.incoming_packet_data[5] != 0)
        {
          memcpy(rgb_preset, protocol_data.incoming_packet_data, 3);
          write_preset_to_flash();
        }
        led_enable = 1;
        update_pwm();
        break;
      case PKT_H2D_GET_DEFAULT_RGB:
        protocol_send_packet(PKT_D2H_DEFAULT_RGB, rgb_preset, 3);
        break;
      case PKT_H2D_GET_FW_VERSION:
        protocol_send_packet_uint32(PKT_D2H_FW_VERSION, FW_VERSION_ID + (HW_VERSION_ID << 16));
        break;
      case PKT_H2D_SHUTTER_PULSE:
        shutter_pulse_timer = millis + protocol_data.incoming_packet_data[0] * 10; // stored as 10s of ms
        gpio_put(PinShutter, 1);
        break;
      case PKT_H2D_DFU_MODE:
        // enter DFU mode by resetting into USB mass storage bootloader
        reset_usb_boot(0, 0);
        break;
#ifdef HW_VERSION_BSL1
      case PKT_H2D_GET_TRIM:
        protocol_send_packet(PKT_D2H_TRIM, (char *)trim, 4);
        break;
      case PKT_H2D_SET_TRIM:
        memcpy(trim, protocol_data.incoming_packet_data, 4);
        write_preset_to_flash();
        update_pwm();
        break;
#endif
#ifdef HW_SUPPORTS_FOCUS
      case PKT_H2D_SET_FOCUS:
        gpio_put(PinFocus, protocol_data.incoming_packet_data[0] != 0 ? 1 : 0);
        break;
#endif
    }
  }

  if (shutter_pulse_timer > 0 && millis >= shutter_pulse_timer)
  {
    gpio_put(PinShutter, 0);
    shutter_pulse_timer = -1;
  }

  if (millis >= adc_reporting_timer)
  {
    led_temp_mdegc = adc_get_led_temp_mdegc();
    vbus_mv = adc_get_vbus_mv();
    cc_mv = adc_get_cc_mv();

    OperatingMode prev_operating_mode = operating_mode;

    if (led_temp_mdegc > OverTemperatureThresholdMdegc)
      operating_mode = OperatingModeOff;

    if (vbus_mv < USBVBUSThreshold5V)
      operating_mode = OperatingModeOff;
    else if (vbus_mv > USBVBUSThreshold9V)
      operating_mode = OperatingMode9V;
    else // 5V range
      if (cc_mv > USBCCThresholdRd3p0)
        operating_mode = OperatingMode5V3A;
      else if (cc_mv > USBCCThresholdRd1p5)
        operating_mode = OperatingMode5V1P5A;
      else
        operating_mode = OperatingMode5V0P5A;

#ifdef HW_VERSION_SL2
    operating_mode = OperatingMode5V3A;
#endif

    if (prev_operating_mode != operating_mode)
    {
      if (operating_mode == OperatingModeOff)
      {
        // undervoltage protection - ensure that LED drivers are off before USB is connected
        // clear color setting
        for (uint32_t i = 0; i < 5; i++)
        {
          color[i] = 0;
        }
      }

      if (prev_operating_mode == OperatingModeOff)
      {
        // visual self test when power is connected
        led_enable = 1;
        color[0] = 0;
        color[1] = 0;
        color[2] = 0;
        color[3] = 32;
        update_pwm();
        busy_wait_ms(150);
        color[0] = 32;
        color[1] = 0;
        color[2] = 0;
        color[3] = 0;
        update_pwm();
        busy_wait_ms(150);
        color[0] = 0;
        color[1] = 32;
        color[2] = 0;
        update_pwm();
        busy_wait_ms(150);
        color[0] = 0;
        color[1] = 0;
        color[2] = 32;
        update_pwm();
        busy_wait_ms(150);
        // set color to RGB "white" but off by default
        color[0] = rgb_preset[0];
        color[1] = rgb_preset[1];
        color[2] = rgb_preset[2];
#ifdef HW_VERSION_SL2
        led_enable = 1;
#else
        led_enable = 0;
#endif
      }

      update_pwm();
    }

    protocol_send_packet_int32(PKT_D2H_LED_TEMP, led_temp_mdegc);
    protocol_send_packet_int32(PKT_D2H_VBUS, vbus_mv);
    adc_reporting_timer = millis + ADCReportingIntervalMs;
  }
}

int main()
{
  stdio_init_all();

  read_preset_from_flash();

  adc_init();
#ifndef HW_VERSION_SL2
  adc_gpio_init(PinADCGPIOOffset + PinADCThermistor);
  adc_gpio_init(PinADCGPIOOffset + PinADCVBUSSense);
#endif
#ifdef HW_VERSION_SL4
  adc_gpio_init(PinADCGPIOOffset + PinADCUSBCC1);
  adc_gpio_init(PinADCGPIOOffset + PinADCUSBCC2);
#endif

  gpio_init(PinShutter);
  gpio_set_dir(PinShutter, GPIO_OUT);
  gpio_put(PinShutter, 0);
  gpio_init(PinFocus);
  gpio_set_dir(PinFocus, GPIO_OUT);
  gpio_put(PinFocus, 0);

#ifndef HW_VERSION_SL2
  button_system_init();

  button_t *button_1 = create_button(PinButton1, on_button_change);
  button_t *button_2 = create_button(PinButton2, on_button_change);
#endif

  // setup PWM pins
  uint32_t f_sys = clock_get_hz(clk_sys);
  uint32_t clk_div = 4;
  pwm_wrap = (f_sys / (clk_div * PWMFreqHz)) - 1;

  for (int i = 0; i < PWM_PIN_COUNT; i++)
  {
    gpio_set_function(PWMPins[i], GPIO_FUNC_PWM);

    uint slice_num = pwm_gpio_to_slice_num(PWMPins[i]);
    uint channel = pwm_gpio_to_channel(PWMPins[i]);

    pwm_set_clkdiv_int_frac(slice_num, clk_div, 0);
    pwm_set_wrap(slice_num, pwm_wrap);

    pwm_set_chan_level(slice_num, channel, 0);
    pwm_set_enabled(slice_num, true);
  }

  uint64_t micros;
  uint32_t dt;

  while (true)
  {
    micros = time_us_64();
    tick(us_to_ms(micros), dt);
    dt = time_us_64() - micros;
    if (dt < TickIntervalUs)
    {
      absolute_time_t target;
      update_us_since_boot(&target, micros + TickIntervalUs);
      busy_wait_until(target);
    }
  }
}

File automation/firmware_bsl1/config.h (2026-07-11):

#include "pico/stdlib.h"

#include "hardware/flash.h"

#define FW_VERSION_ID 2

#if !defined(HW_VERSION_BSL1) && !defined(HW_VERSION_SL4) && !defined(HW_VERSION_SL2)
#define HW_VERSION_BSL1
#endif

typedef enum
{
  OperatingModeOff,
  OperatingMode5V0P5A,
  OperatingMode5V1P5A,
  OperatingMode5V3A,
  OperatingMode9V,
} OperatingMode;

static const float ADCVPerCount = 3.3 / 4095.0;

static const float ThermistorLookUpTable[][2] = {
    // {V, degrees C}
    {2.9, -5.0},
    {2.45, 15.0},
    {1.66, 43.0},
    {0.89, 75.0},
    {0.41, 111.0},
    {0.21, 150.0}};

static const uint32_t PWMFreqHz = 40000;
static const uint32_t USBVBUSThreshold5V = 4400;
static const uint32_t USBVBUSThreshold9V = 7800;
static const uint32_t USBCCThresholdRdUSB = 200;
static const uint32_t USBCCThresholdRd1p5 = 660;
static const uint32_t USBCCThresholdRd3p0 = 1230;
static const uint32_t OverTemperatureThresholdMdegc = 80000;

static const uint32_t TickIntervalUs = 10000;
static const uint32_t ADCReportingIntervalMs = 200;

#define FLASH_PERSIST_OFFSET (PICO_FLASH_SIZE_BYTES - FLASH_SECTOR_SIZE)
#define FLASH_PERSIST_ADDR_RGB_PRESET 0
#define FLASH_PERSIST_ADDR_TRIM 8

#ifdef HW_VERSION_BSL1

#define HW_VERSION_ID 0

static const uint32_t PinR1 = 2;
static const uint32_t PinG1 = 3;
static const uint32_t PinB1 = 4;
static const uint32_t PinW1 = 1;
static const uint32_t PinR2 = 6;
static const uint32_t PinG2 = 9;
static const uint32_t PinB2 = 10;
static const uint32_t PinW2 = 5;
static const uint32_t PinIR = 11;
static const uint32_t PinButton1 = 16; // top button
static const uint32_t PinButton2 = 17; // bottom button
static const uint32_t PinShutter = 25;
static const uint32_t PinFocus = 24; // UNUSED
static const uint32_t PinADCGPIOOffset = 26;
static const uint32_t PinADCVBUSSense = 0;
static const uint32_t PinADCThermistor = 1;

#define PWM_PIN_COUNT 9
static const uint32_t PWMPins[PWM_PIN_COUNT] = {PinR1, PinG1, PinB1, PinW1, PinR2, PinG2, PinB2, PinW2, PinIR};

static const int8_t DefaultTrimR = 0;
static const int8_t DefaultTrimG = 0;
static const int8_t DefaultTrimB = 0;
static const int8_t DefaultTrimW = 17;

// LED driver power limits - lookup by operating mode
static const uint8_t PowerLimitRGB[5] = {0, 153, 153, 153, 255};
static const uint8_t PowerLimitSingleChannel[5] = {0, 204, 204, 204, 255};

static const float ADCVBUSSenseScale = (5.1 + 20.0) / 5.1;

#endif

#ifdef HW_VERSION_SL4

#ifdef HW_SUPPORTS_FOCUS
#define HW_VERSION_ID 3
#else
#define HW_VERSION_ID 1
#endif

static const uint32_t PinR1 = 2;
static const uint32_t PinG1 = 3;
static const uint32_t PinB1 = 4;
static const uint32_t PinW1 = 1;
static const uint32_t PinButton1 = 16; // top button
static const uint32_t PinButton2 = 17; // bottom button
static const uint32_t PinShutter = 25;
static const uint32_t PinFocus = 24;
static const uint32_t PinADCGPIOOffset = 26;
static const uint32_t PinADCVBUSSense = 0;
static const uint32_t PinADCThermistor = 1;
static const uint32_t PinADCUSBCC1 = 2;
static const uint32_t PinADCUSBCC2 = 3;

#define PWM_PIN_COUNT 4
static const uint32_t PWMPins[PWM_PIN_COUNT] = {PinR1, PinG1, PinB1, PinW1};

static const int8_t DefaultTrimR = 0;
static const int8_t DefaultTrimG = 0;
static const int8_t DefaultTrimB = 0;
static const int8_t DefaultTrimW = 0;

// LED driver power limits - lookup by operating mode
// Decided not to limit power for 500mA/1.5A USB modes, since it may be too confusing for users
static const uint8_t PowerLimitRGB[5] = {0, 255, 255, 255, 255};
static const uint8_t PowerLimitSingleChannel[5] = {0, 255, 255, 255, 255};
//static const uint8_t PowerLimitRGB[5] = {0, 82, 234, 255, 255};
//static const uint8_t PowerLimitSingleChannel[5] = {0, 170, 255, 255, 255};

static const float ADCVBUSSenseScale = 2.0;

#endif

#ifdef HW_VERSION_SL2

#define HW_VERSION_ID 2

static const uint32_t PinR1 = 7;
static const uint32_t PinG1 = 8;
static const uint32_t PinB1 = 9;
static const uint32_t PinW1 = 10; // UNUSED
static const uint32_t PinButton1 = 16; // UNUSED
static const uint32_t PinButton2 = 17; // UNUSED
static const uint32_t PinShutter = 14; // UNUSED
static const uint32_t PinFocus = 15; // UNUSED
static const uint32_t PinADCGPIOOffset = 26;
static const uint32_t PinADCVBUSSense = 0; // UNUSED
static const uint32_t PinADCThermistor = 1; // UNUSED

#define PWM_PIN_COUNT 3
static const uint32_t PWMPins[PWM_PIN_COUNT] = {PinR1, PinG1, PinB1};

static const int8_t DefaultTrimR = 0;
static const int8_t DefaultTrimG = 0;
static const int8_t DefaultTrimB = 0;
static const int8_t DefaultTrimW = 0; // UNUSED
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

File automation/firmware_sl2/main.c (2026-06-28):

#include <stdio.h>
#include <math.h>

#include "pico/stdlib.h"
#include "hardware/pwm.h"
#include "hardware/clocks.h"
#include "hardware/gpio.h"

static const uint32_t PinR = 7;
static const uint32_t PinG = 8;
static const uint32_t PinB = 9;
static const uint32_t PinShutter = 14;
static const uint32_t RGBPins[] = {PinR, PinG, PinB};

static const uint32_t PWMFreqHz = 120000;//120000;

static const uint32_t ShutterPulseDelayMs = 100;
static const uint32_t TickIntervalUs = 1000;

uint8_t color[3] = { 255, 255, 255 };
uint32_t pwm_wrap;

// Camera

void camera_activate_shutter() {
  gpio_put(PinShutter, true);
  sleep_ms(ShutterPulseDelayMs);
  gpio_put(PinShutter, false);
}

// PWM

void update_pwm() {
  for (int i = 0; i < 3; i++) {
    uint slice_num = pwm_gpio_to_slice_num(RGBPins[i]);
    uint channel = pwm_gpio_to_channel(RGBPins[i]);
    // Duty cycle = wrap * percent / 100
    uint32_t level = (pwm_wrap * color[i]) / 255;
    pwm_set_chan_level(slice_num, channel, level);
  }
}

// UART

static const char PacketStartByte = 254;
static const char PacketEndByte = 255;

enum CmdType {
    CmdTypeSet = 0,
    CmdTypeReset,
    CmdTypeMax
};

char packet_type;
char incoming_packet[128];
uint32_t packet_index = 0;
uint32_t packet_end;

void handle_uart_packet() {
  if (packet_type == CmdTypeSet) {
    color[0] = incoming_packet[0];
    color[1] = incoming_packet[1];
    color[2] = incoming_packet[2];
    update_pwm();
  }
}

void handle_uart_input(char c) {
  if (packet_index == 0 && c == PacketStartByte) {
    // Packet start
    packet_index++;
  } else if (packet_index == 1) {
    // Packet type
    if (c < CmdTypeMax) {
      packet_type = c;
      packet_index++;
    } else packet_index = 0;
  } else if (packet_index == 2) {
      // Data Length
      packet_end = c + 2;
      packet_index++;
  } else if (packet_index >= 3 && packet_index < packet_end && packet_index - 3 < sizeof(incoming_packet) - 1) {
    // Data start
    incoming_packet[packet_index - 3] = c;
    packet_index++;
  } else {
    // End
    incoming_packet[packet_index - 3] = c;
    incoming_packet[packet_index - 2] = 0;
    handle_uart_packet();
    packet_index = 0;
  }
}

// Main loop

void tick(uint32_t millis, uint32_t dt_micros) {
  while (true) {
    int32_t c = getchar_timeout_us(0);
    if (c != PICO_ERROR_TIMEOUT) handle_uart_input(c);
    else break;
  }
}

int main() {
  stdio_init_all();

  gpio_init(PinShutter);
  gpio_set_dir(PinShutter, GPIO_OUT);
  gpio_put(PinShutter, false);

  uint32_t f_sys = clock_get_hz(clk_sys);
  uint32_t clk_div = 4;
  pwm_wrap = (f_sys / (clk_div * PWMFreqHz)) - 1;

  for (int i = 0; i < 3; i++) {
    gpio_set_function(RGBPins[i], GPIO_FUNC_PWM);

    uint slice_num = pwm_gpio_to_slice_num(RGBPins[i]);
    uint channel = pwm_gpio_to_channel(RGBPins[i]);

    pwm_set_clkdiv_int_frac(slice_num, clk_div, 0);
    pwm_set_wrap(slice_num, pwm_wrap);

    pwm_set_chan_level(slice_num, channel, pwm_wrap);
    pwm_set_enabled(slice_num, true);
  }

  // visual self test at startup
  busy_wait_ms(100);
  color[0] = 255;
  color[1] = 0;
  color[2] = 0;
  update_pwm();
  busy_wait_ms(150);
  color[0] = 0;
  color[1] = 255;
  color[2] = 0;
  update_pwm();
  busy_wait_ms(150);
  color[0] = 0;
  color[1] = 0;
  color[2] = 255;
  update_pwm();
  busy_wait_ms(150);
  color[0] = 255;
  color[1] = 255;
  color[2] = 255;
  update_pwm();

  uint64_t micros;
  uint32_t dt;

  while (true) {
    micros = time_us_64();
    tick(us_to_ms(micros), dt);
    dt = time_us_64() - micros;
    if (dt < TickIntervalUs) {
      absolute_time_t target;
      update_us_since_boot(&target, micros + TickIntervalUs);
      busy_wait_until(target);
    }
  }
}

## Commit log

2024-08-03 add pcb
    [backlight-B_Cu.gbl, backlight-B_Mask.gbs, backlight-B_Silkscreen.gbo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]
2024-08-03 add 3d files
    [24d-p0010 diffuser housing.SLDPRT, 24d-p0010 diffuser housing.STL, 24d-p0020 diffuser cover plate.SLDPRT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]
2024-10-09 fix incorrect part number in BOM
    [backlight.kicad_pcb, bom.csv, power_input.kicad_sch]
2025-07-02 add rev2 pcb
    [backlight-B_Cu.gbl, backlight-B_Mask.gbs, backlight-B_Paste.gbp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]
2025-07-20 link v2 page
    [24d-p0010 diffuser housing.SLDPRT, 24d-p0010 diffuser housing.STL, 24d-p0020 diffuser cover plate.SLDPRT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]
2025-08-02 minor updates to 3d files
    [25c-a102 120 carrier assembly.STEP, 25c-p001d reflector box housing.step, 25c-p001f reflector box housing.step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]
2025-08-15 add horizontal mount cad
    [25c-p032 diffuser mount.step, 25c-p034 camera clamp slider.step, 25c-p035 camera clamp cleat.step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]
2025-08-21 slightly improved 35mm mask design + half frame mask
    [25c-p011 35mm mask.step, 25c-p020 35mm half frame mask.step]
2025-11-09 current production firmware
2025-12-08 big scanlight info page
    [timing diagram.kicad_sch]
2025-12-16 pcb files
    [bsl_array_v1-Edge_Cuts.gm1, bsl_array_v1-F_Cu.gtl, bsl_array_v1-F_Mask.gts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]
2025-12-18 add v3 snapfit design files
    [25c-p001f2 reflector box housing snapfit.step, 25c-p003b2 diffuser bezel snapfit.step]
2025-12-26 add big scanlight assembly instructions
2025-12-28 big scanlight step files
    [25d103 diffuser bezel snapfit.step, 25d104 backplate.step, 25d105 pcb cover.step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]
2025-12-28 add assembly step file
2025-12-31 add tonecarrier adapter
    [25d110 tonecarrier compatibility plate.step]
2026-01-14 add valoi360 adapter info
    [25d111 valoi 360 advancer compatibility plate.step]
2026-05-08 reorganize cad files, add latest big scanlight changes
    [24d-p0010 diffuser housing.STL, 24d-p0020 diffuser cover plate.STL, 24d-p0040 diffuser frame.STL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]
2026-05-09 publish v4 CAD
    [25c-a102 120 carrier assembly.STEP, 25c-p011 35mm mask.step, 25c-p012 35mm film carrier half.step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]
2026-06-05 add v4 horizontal mount option CAD
2026-06-06 update v4 tonecarrier plate
    [26a110 tonecarrier compatibility plate.step, 26a110b tonecarrier compatibility plate.step]
2026-06-21 improved valoi 360 adapter files
    [26a112 valoi 360 mask compatibility plate.step, 26a113 valoi 360 combined compatibility plate.step]
2026-06-28 add pre-shutter delay and keep light on option to web app
    [driver_channel_w.kicad_sch, power.kicad_sch, timing diagram.kicad_sch]
2026-07-05 update assembly instructions for clarity
2026-07-05 update pcb revision / 3.5mm jack info
2026-07-11 update v4 pcb files
    [driver_channel.kicad_sch, led_array.kicad_sch, led_cluster.kicad_sch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]
2026-08-04 updated sample scans
2026-08-14 fix v3 firmware startup behavior bug
    [main.c]
2026-09-15 add lobster holder and essential film holder adapter step files
    [25d114b lobster compatibility plate.step, 25d115 efh compatibility plate.step]
2026-09-20 add white brightness control to webapp (useful for using the light as an adjustable light source for camera testing)
2026-09-20 add step files for film carrier clips
    [26a114 film carrier clip 35.step, 26a115 film carrier clip 120.step]
2026-09-24 sync big scanlight part step files #26
    [25d101c diffuser box.step, 25d103a diffuser bezel.step, 25d104 backplate.step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]
2026-09-27 Update 26a115 film carrier clip 120.step
    [26a115 film carrier clip 120.step]
2026-10-18 remove csv from gitignore, regenerate BOMs and schematics
2026-10-18 update assembly instructions for clearer film carrier compatibility, add aps carrier and some legacy files

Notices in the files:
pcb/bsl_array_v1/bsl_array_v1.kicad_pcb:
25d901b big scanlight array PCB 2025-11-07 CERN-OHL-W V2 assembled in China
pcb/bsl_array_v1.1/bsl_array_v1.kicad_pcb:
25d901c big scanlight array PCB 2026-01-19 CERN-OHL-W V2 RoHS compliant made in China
